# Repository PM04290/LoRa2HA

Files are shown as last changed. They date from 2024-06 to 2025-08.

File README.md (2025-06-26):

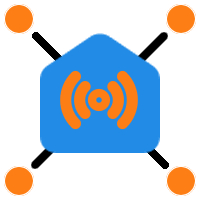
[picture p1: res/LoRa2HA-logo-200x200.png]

# LoRa2HA

Document version 1.4

## Introduction
LoRa2HA permet de combler un vide dans les équipements domotique lorsque qu'il est nécéssaire de surveiller/piloter sur une longue distance, là où Wifi et Zigbee ne peuvent aller.
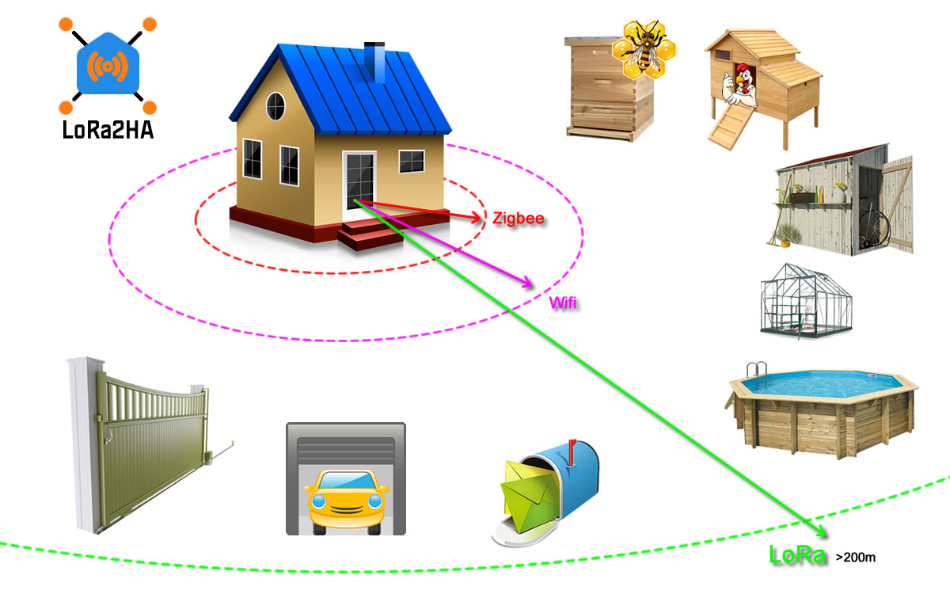
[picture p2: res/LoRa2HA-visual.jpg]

Le projet propose des équipements permettant une interconnexion entre des capteurs/actionneurs très éloignés d'un serveur HomeAssistant (via MQTT), par radio en utilisant des modules LoRa.
Le HUB, à base d'ESP32 (Wifi ou Ethernet), reçoit les données radio et les envoi vers Home Assistant (H.A.) au travers d'un serveur MQTT. Le terme de HUB sera utilisé, et non Gateway, afin de ne pas créer de confusion avec les Gateway « LoRaWan ».

Le projet contient les sources de tous les firmwares, les schémas des cartes, les « Gerber » afin de pouvoir les fabriquer et des fichiers 3D pour la fabrication de boîtiers.

## Documentation

Le fichier PDF de la documentation complète est téléchargeable [ici](https://raw.githubusercontent.com/PM04290/LoRa2HA/main/doc/LoRa2HA-readme-14.pdf)

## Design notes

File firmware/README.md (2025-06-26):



# LoRa2HA T3216 Firmware
Firmware library for LoRa2HA module with ATtiny3216 mcu

|File name|Version|Target|Description|
|---|--:|---|---|
|T3216_blinkLED|1.0|T3216|Just a blink test, for 1MHz, low power (MLA30)
|T3216_blinkRGB|1.0|T3216|Just a blink test, for 4MHz (MLD03, MLE31, MLE42)
|MLD03_waterpool-02|2.0|T3216|Waterpool manager (filter, refill, frost)
|MLD03_sprinkle-02|2.0|T3216|2 ways sprinkle manager
|MLA30_mboxS-02|2.0|T3216|Mailbox with 3 magnetic sensor (NO), state in H.A
|MLA30_mboxT-02|2.0|T3216|Mailbox with 3 magnetic sensor (NO), opening trigger in H.A
|MLA30_ping-02|2.0|T3216|MLA30+Oled pinger for distance test
|MLE31_gate-02|2.0|T3216|Control gate opening
|MLE42_garage-02|2.0|T3216|Control garage door
|MLE42_henhouse-02|2.0|T3216|Control henhouse door

# HowTo

Use a simple USB/TTL dongle, with 1k resistor between RX and TX; connect VCC/GND and TX to UPDI.

Run uploadfirmware.bat

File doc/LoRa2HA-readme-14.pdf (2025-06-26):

# LoRa2HA

Documentation version 1.4

# Introduction

LoRa2HA est un ensemble d’équipements permettant une interconnexion entre des capteurs/actionneurs éloignés et un serveur Home Assistant (via MQTT), par radio en utilisant des modules LoRa®
; la portée peut
aller jusqu’à plus de 500m selon la qualité des antennes.

Le HUB (basé sur ESP32), reçoit les données radio et les envoi à Home Assistant (H.A) au travers d’un serveur MQTT.

Le terme de HUB sera utilisé, et non Gateway, afin de ne pas créer de confusion avec les Gateway
« LoRaWan ».

Le projet¹
contient les sources de tous les firmwares, les schémas des cartes ainsi que les « Gerber » afin de pouvoir fabriquer les PCB.

1 Ce projet est destiné à la communauté des « makers » et est fourni à titre informatif et éducatif. Il est fourni "tel quel", sans garantie d'aucune sorte, expresse ou implicite, y compris, mais sans s'y limiter, notamment concernant son fonctionnement, sa sécurité ou son adéquation à un usage particulier. L'utilisation de ce projet se fait à vos propres risques. L'auteur et les contributeurs ne pourront être tenus responsables des conséquences de l'utilisation de ce projet, des dommages directs, indirects, accessoires, ou consécutifs pouvant résulter de l'utilisation ou de l'incapacité d'utiliser le projet. L'assemblage, la modification ou l'utilisation des matériels et logiciels associés à ce projet impliquent des risques. Vous êtes seul responsable de l'utilisation que vous en faites, y compris des éventuels
dommages matériels, blessures, ou autres incidents pouvant survenir.
Important : Avant d'utiliser ce projet dans un environnement de production ou dans un cadre professionnel, veuillez vous assurer qu'il est conforme à vos exigences et aux réglementations en vigueur.
Attention : Manipuler des composants électroniques, des outils, ou des matériaux peut être dangereux. Prenez toutes les précautions nécessaires, notamment l'utilisation d'équipements de protection, et suivez les réglementations locales en matière de sécurité.

### LoRa2HA

## Sommaire

# 1 Les équipements

La référence de chaque module adopte la terminologie suivante :

- ML : Module LoRa
- H : Hub, D : Dédié, E : alimentation Externe, A : alimentation Autonome
- un nombre indiquant un ordre de création (Ex : Hub et Dédié) ou un nombre d’entrées sorties (Ex 31 = 3 entrées / 1 sortie), éventuellement suivi d’un ordre de création ou d’une lettre (fonctionnalité particulière).

La nouvelle génération de modules est basée sur le microprocesseur ATtiny3216, une carte « fille » MLT3216 équipe la majorité des modules de terrains, étant extractible elle permet une mise à jour firmware plus facilement.

## 1.1 Les HUB

Il existe 5 types de HUB selon le besoin, tous équipés d’un module LoRa :

- MLH1²
: ESP32-S2 Mini, en wifi
- MLH2 : Olimex-POE-ISO, en Ethernet avec POE
- MLH3 : WT32-ETH01, en Ethernet
- MLH4 : ESP32-D1-Mini, en wifi
- MLH5 : TTGO_LoRa32 (pcb T3_v1.6)

Dans le cas du MLH3, il est tout à fait possible de le rendre « POE » en le connectant derrière un répartiteur POE de ce type, type USB-C/5v (coût inférieur à 10€) :

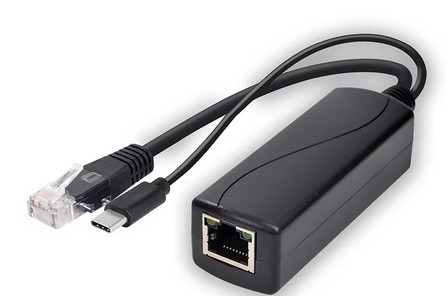
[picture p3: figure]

Le HUB dispose de son propre serveur web permettant le paramétrage de la connexion à H.A ainsi que l’identification des tous les modules sur le terrain.

Estimation de difficulté/prix

Modèle | Wifi | Ethernet | POE | DIY | Coût
MLH1 | ✓ | | | ★☆☆ | ★☆☆
MLH2 | ✓ | ✓ | ✓ | ★☆☆ | ★★★
MLH3 | ✓ | ✓ | indirect | ★★☆ | ★★☆
MLH4 | ✓ | | | ★☆☆ | ★☆☆
MLH5 | ✓ | | | ★☆☆ | ★★☆
DIY : difficulté de fabrication | Coût : <10€, <15€, >15€

2 Le HUB MLH1 ne permet pas le téléchargement des firmware par UPDI

## 1.2 Les modules « capteurs/actionneurs »

Il existe plusieurs types de modules :

- MLD01 : Relevé TIC Linky (alimenté par USB externe)
- MLD02 : Relevé TIC Linky (alimenté par Linky) (projet en cours)
- MLD03 : Gestion de piscine (hors chimie)
- MLA30 : 3 entrées, autonome, très basse consommation, avec batterie et panneau solaire
- MLE21 : 2 entrées / 1 sortie, alimenté en 8-28vdc (remplacé par MLE31)
- MLE31 : 3 entrées / 1 relai, alimenté en 8-28vdc
- MLE42 : 4 entrées / 2 relais ou 1 moteur (2 sens de rotation), alimenté en 8-28vdc

Chaque module possède un Firmware proposé par défaut mais il est possible d’adapter ceux-ci pour en modifier les fonctionnalités et/ou l’adapter aux capteurs connectés.

Estimation de difficulté/prix

Modèle | DIY | Coût module | Coût externe³
MLD01 | ★☆☆ | ★☆☆ | ☆☆☆
MLD03 | ★★☆ | ★★★ | ★★☆
MLA30 | ★★★ | ★★☆ | ★★☆
MLE31 | ★★☆ | ★★★ | ★☆☆
MLE42 | ★★☆ | ★★★ | ★★☆
DIY : difficulté de fabrication | Coût : <10€, <15€, >15€

3 Le coût externe est une indication du coût des différents capteurs/actionneurs les plus courants dans les applications pour lesquelles les modules sont utilisés.

# 2 Fonctionnement

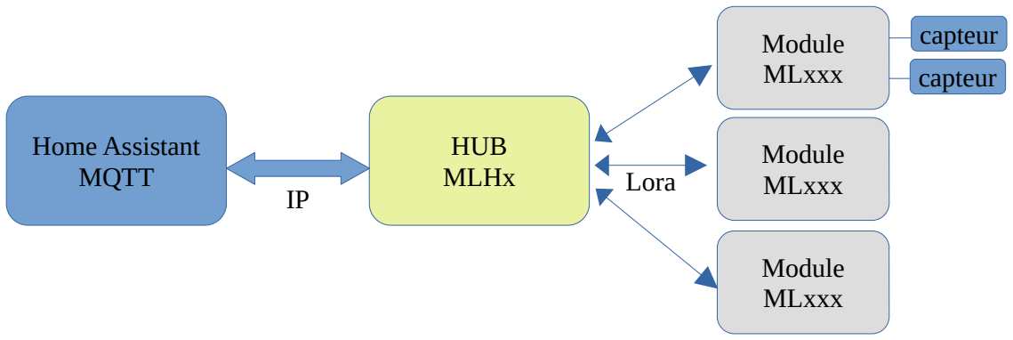
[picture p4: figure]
Home Assistant MQTT; HUB MLHx; Module MLxxx; Lora; capteur capteur

Chaque module (MLxxx) transmet les informations des capteurs (par LoRa) vers le HUB, celui-ci est connecté à H.A (via MQTT) par IP, et redirige les informations.

❗️ ATTENTION : le choix des antennes et leur position sont particulièrement importants.

Il est conseillé d’installer une antenne à gain important sur le HUB (> 3 dBi).

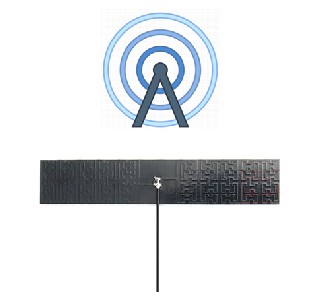
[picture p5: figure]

L’antenne à « ressort » des modules RA-01, ainsi que les antennes « bâton » (généralement avec connecteur SMA) doivent être utilisées à la verticale.

Les antennes IPX sur PCB, comme ci-contre (jonction au milieu), doivent être utilisées à la verticale et perpendiculaire à l’azimut du HUB.

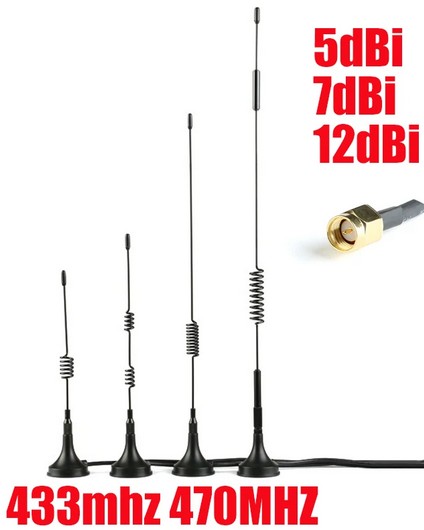
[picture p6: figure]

Exemple de choix d’antenne que vous pouvez installer sur le HUB, avec un convertisseur IPX/SMA, sur un module RA-02.

# 3 Mise en route

Cela commence par l’installation et la configuration du HUB.

H.A doit avoir un serveur MQTT en état de fonctionnement.

## 3.1 Installation du HUB

→ Pour la programmation du HUB, voir le chapitre « Programmation »

Le HUB une foi programmé doit être raccordé au réseau IP, identique à celui de H.A.

## 3.1.1 Sélecteur WMODE

Le sélecteur « WMODE » permet de choisir le mode de fonctionnement du réseau IP : Wifi STA, Wifi AP ou Ethernet.

- Wifi STA (Station) démarre le HUB en mode Wifi « classique », même si ce wifi n’est pas disponible, il restera alors en « défaut » (l’ancienne version passait automatiquement en mode AP, cela générait des problèmes lors de coupure générale du secteur, quand le routeur wifi était long à démarrer, le HUB ne le trouvait pas et passait en mode AP),
- Wifi AP force le HUB à rester en mode AP (Access Point), même si les données wifi ont été renseignées,
- Ethernet (seulement sur MLH2 et MLH3) force le HUB à fonctionner en Ethernet, le Wifi n’est pas utilisé, câble connecté ou non.

→ Pour les HUB wifi :

- si aucun paramétrage n’a jamais été effectué, il passe automatiquement en mode « Point d’accès » (AP).
- si un autre réseau wifi a déjà été paramétré et que vous souhaitez en changer parce qu’il n’est pas accessible, positionnez le sélecteur « WMODE » en position AP.

## 3.1.2 Wifi AP

Cherchez un réseau wifi nommé « lora2ha0 » et connectez-vous ; le mot de passe est : 12345678.

En mode AP, le HUB est à l’adresse IP 192.168.4.1 ou l’URL lora2ha0.local ; la page ci-dessous doit s’afficher.

Avec un smartphone, scannez les QRcode suivants :

Connexion au wifi AP du HUB

Accès à la page web

❗️ Si la page ne s’affiche pas, il est probable que le dossier « data », contenant le serveur web, n’ai pas été téléchargé correctement dans l’ESP32.

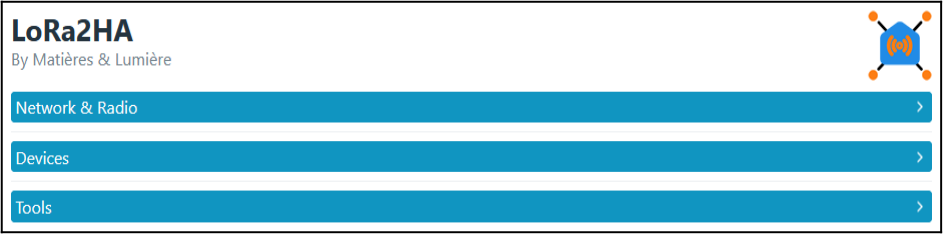
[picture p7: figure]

## 3.1.3 Configuration réseau

Ouvrez la zone « Network & Radio », renseignez les données demandées puis enregistrez.

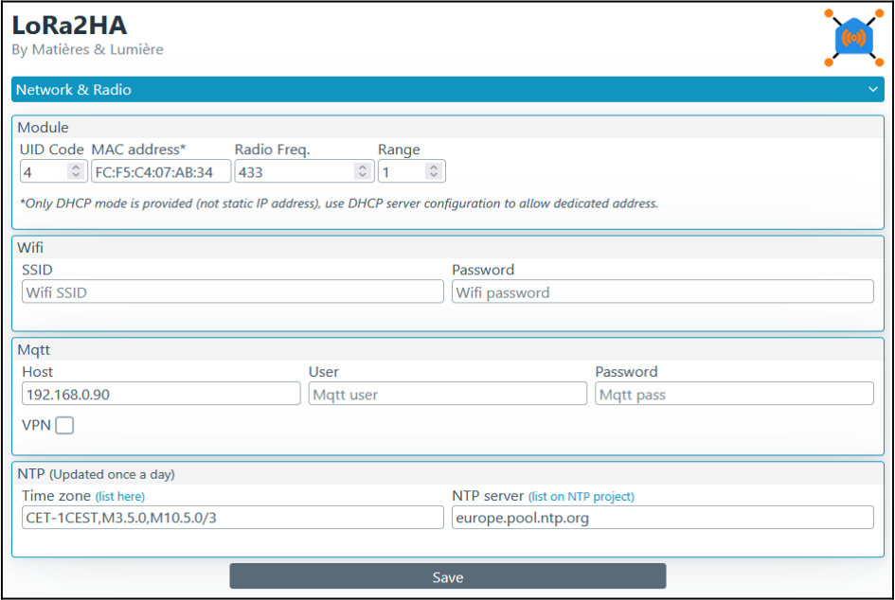
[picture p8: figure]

L’information de l’adresse MAC vous permet de pouvoir gérer votre serveur DHCP et affecter une adresse IP spécifique, le HUB ne fonctionne QUE avec un serveur DHCP, il n’est pas possible de lui attribuer une IP fixe.

Si vous envisagez de mettre plusieurs HUB sur le réseau, il faut indiquer un code unique à chacun dans « UID Code » (sinon laissez 0) ; il est conseillé de mettre « 1 » au premier HUB que vous paramétrez et laisser « 0 » pour le suivant.

Selon le modem LoRa qui est utilisé, vous devez indiquer la fréquence 433 ou 868 (MHz).

Dans « Mqtt host » indiquez uniquement l’adresse IP du serveur Mqtt (ou celle de H.A si Mqtt y est intégré en Add-on).

☞ Le port par défaut est le 1883 (pas de SSL). Un prochaine version permettra d’utiliser SSL.

Le configuration NTP sert au HUB pour « publier » l’heure vers les différents modules qui en ont besoin.

Une fois sauvegardé, il faut redémarrer le HUB, physiquement ou en cliquant sur le bouton « Reset » dans la zone « Tools », avant cela, positionnez le sélecteur « WMODE » sur STA.

En « production » l’adresse du HUB est « lora2ha0.local », ou l’adresse IP fournie par votre serveur DHCP.

Le HUB est prêt à recevoir les informations radio des « modules » et ainsi pouvoir les paramétrer.

## 3.1.4 Utilitaires

La zone « Tools » permet d’effectuer la maintenance du HUB ainsi que des mises à jours de fichiers, ou sauvegarder la configuration.

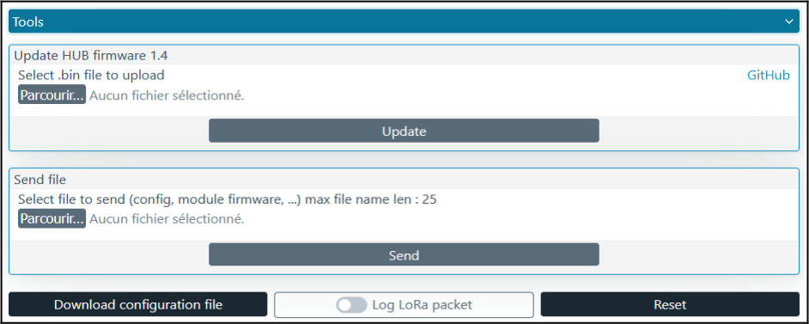
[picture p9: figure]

## 3.1.5 Mise à jour du Firmware

Le firmware peut être mis à jour par OTA (Other The Air), cliquant sur le bouton « Parcourir » de la zone « Update firmware », de sélectionner le fichier contenant le Firmware (avec un extension .bin), le nom contient en général le type d’ESP32 qui est utilisé, et enfin cliquer sur le bouton « Update ».

Le téléchargement prend entre 5 et 10 secondes, l’ESP32 redémarre et la page est web rechargée.

☞ Avant toute mise à jour du firmware, effectuez une sauvegarde de la configuration en cliquant sur le bouton

« Download configuration file ».

## 3.1.6 Mise à jour de fichiers

Tous les fichiers du serveur web peuvent être mis à jour en cliquant sur le bouton « Parcourir » de la zone « Send file », de sélectionner le fichier dans le dossier « data », et enfin de cliquer sur le bouton « Send ».

L’ESP32 ne redémarre pas mais la page web est rechargée.

Si vous avez envoyé un nouveau fichier de configuration, il faut redémarrer l’ESP32 pour qu’il soit pris en compte.

## 3.2 Installation des modules capteurs/actionneurs

→Pour la programmation des modules, voir le chapitre « Programmation »

Sur la page web du HUB, ouvrez la zone « Devices », si aucun module n’a encore été appairé, l’indication suivante est affichée.

Il faut mettre le HUB en mode « Pairing » (appairage) en activant le sélecteur « Pairing active », un bandeau orange apparaît.

Sur le module, appuyez sur le bouton « CFG » et mettez le sous tension. Si une led est présente, elle clignote tant que vous tenez le bouton appuyé. Relâchez le bouton pour passer le module en mode « Pairing ».

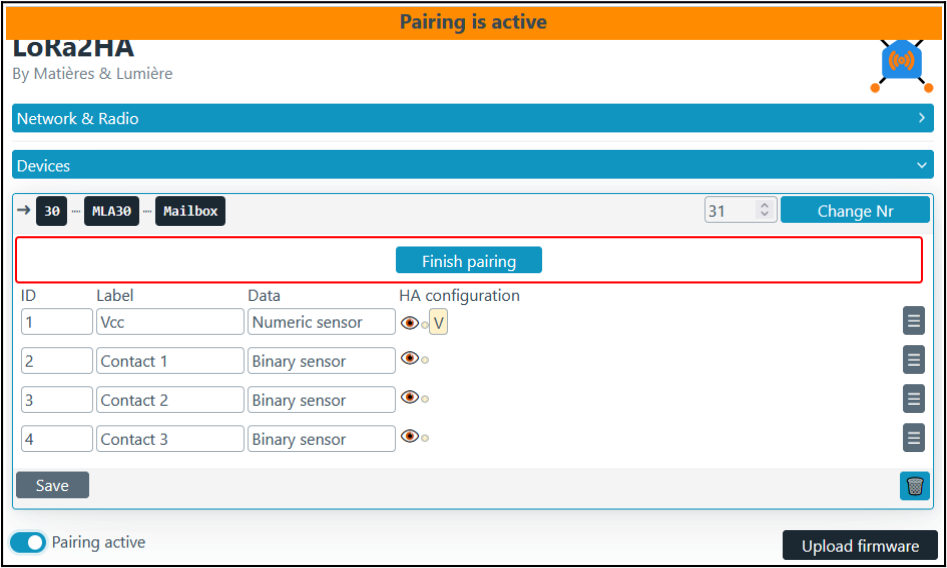
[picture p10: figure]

☞Attention, si vous tenez le bouton « CFG » appuyé plus de 10 secondes, le module fera une remise à zéro complète

de sa mémoire (Factory setting).

Chaque module doit avoir une adresse unique (définie par le firmware), lorsqu’il y a plusieurs modules identiques, il faut modifier l’adressage de ceux-ci :

1. affectez un nouveau numéro
2. cliquez sur le bouton « Change Nr »

Pour libérer le module de son mode « Pairing », vous devez cliquer sur le bouton « Finish pairing ».

→ l’action « Finish pairing » n’a aucune incidence sur le HUB, elle libère simplement le module.

☞ L’image ci-dessus correspond au firmware « mla30-mboxS », avec des contacts qui envoient leur état binaire (Binary

sensor / State) ; dans le cas du firmware « mla30-mboxT » c’est un événement qui est généré (Trigger) et il n’est seulement visible que dans les automatisations.

## 3.2.1 Multiples modules identiques

Lorsque vous avez plusieurs modules identiques, par exemple 2 modules MLA30, ils doivent avoir les numéros 30 et 31, commencez toujours par le numéro le plus haut :

1. appairez le premier module

2. il affiche son numéro par défaut : 30
3. changez son adresse par 31
4. terminez le « pairing »
5. sauvegardez la configuration
6. appairez le deuxième module
7. il affiche son numéro par défaut : 30
8. gardez ce numéro
9. sauvegardez la configuration

## 3.2.2 Paramétrage des capteurs

- « ID » est le n° du capteur/actionneur, il est défini par le firmware de chaque module
- « Label » est le nom du capteur/actionneur qui apparaîtra dans H.A
- « Data » est le type de donnée transmise par le module, il est définit par le firmware

Cliquez ensuite sur le bouton pour ouvrir la boite de dialogue permettant la configuration du capteur/actionneur pour H.A.

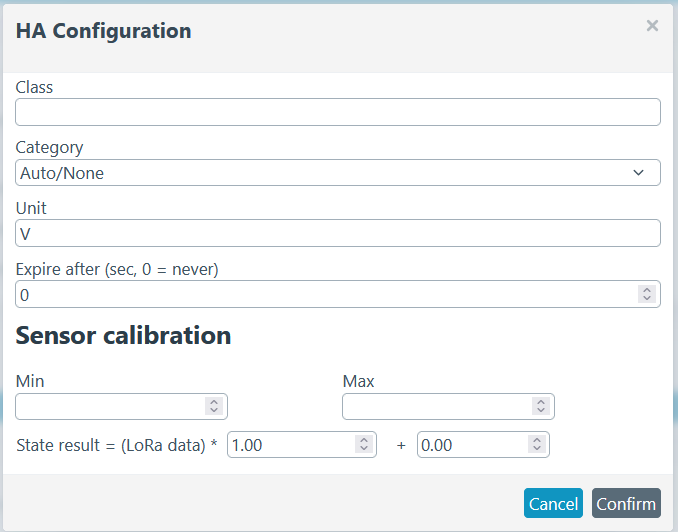
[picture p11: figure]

- « Class » selon le type de capteur (sensor, binary_sensor, etc), il est possible d’avoir des classes différentes, vous trouvez les informations nécessaires sur la page web du site de Home Assistant : https://www.home-assistant.io/docs/configuration/customizing-devices/#device-class (https://www.home-assistant.io/docs/configuration/customizing-devices/#device-class)
- « Category » permet de classer le capteur en tant que Mesure, Diagnostic ou Configuration.
- « Unit » permet d’indiquer l’unité correspondant à la mesure du capteur
- « Expire after » est la durée pendant laquelle la mesure est valide, au-delà elle sera « indisponible » au sens H.A.
- « Min » et « Max » permettent de borner les mesures reçues. Il peut arriver qu’il y ai des erreurs de mesure (ou autre) qui aboutissent à une donnée qui soit hors de sa plage normale, par exemple une consommation électrique de plus de 100 KW, si vous avez un abonnement 9KWh, vous pouvez entrer 10 000 dans max, par exemple.
- « State result » permet d’appliquer des coefficients correcteur à une mesure brute (Y = A*X + B), par exemple si une température est 1° en dessus de la température normale, entrez -1 dans le deuxième paramètre (B).

Dans la zone « Class », commencez à taper le début du texte si vous connaissez la classe à attribuer, ou faite 2 fois 1 clic pour afficher la liste complète.

Après avoir complété les différents paramètres, sauvegardez le paramétrage en cliquant sur « Confirm ».

Après avoir tout configuré, cliquez sur le bouton « Save ».

Il est possible de supprimer entièrement un module en cliquant sur le bouton .

## 3.2.3 Module MLD01 Linky

Le module est à l’adresse « 10 » par défaut (elle ne peut pas être changée, sauf à modifier le firmware et reprogrammer le module).

Le code source proposé, fonctionne en mode « Historique » par défaut, avec très peu de modification il est possible de le faire fonctionner en mode « standard ».

Le module ayant une forte consommation, il n’est pas possible d’utiliser l’alimentation fournie par le connecteur TIC du Linky (borne A), il devra donc avoir sa propre alimentation externe, type chargeur USB.

Connectez le module sur le connecteur TIC du linky : bornes I1 et I2.

Dans le Firmware par défaut (lora2ha-MLD01-Linky-ProMicro) vous disposez des informations ci-dessous :

ID | Label linky | Donnée
1 | OPTARIF | BASE, HPHC/HCHP
2 | BASE | Compteur (KWh)
3 | HPHC | Compteur HC (KWh)
4 | HCHP | Compteur HP (KWh)
5 | PAPP | Puissance apparente (VA)
6 | INST (monophasé) INST1 (triphasé) | Intensité instantanée 1 (A)
7 | INST2 (triphasé) | Intensité instantanée 2 (A)
8 | INST3 (triphasé) | Intensité instantanée 3 (A)

## 3.2.4 Module MLD02 Linky (Autonome)

Ce module n’est pas encore validé.

## 3.2.5 Module MLD3 (Piscine)

Le module « Piscine » est plus particulièrement adapté aux piscines hors-sol, il peut être positionné à l’endroit où est branché la pompe du filtre, dans un boîtier équipé de rail DIN.

La documentation détaillée se trouve dans le document LoRa2HA-MLD03-readme.pdf.

## 3.2.6 Module MLE21 (2 in / 1 out)

Ce module est remplacé par le module MLE31.

## 3.2.7 Module MLE31 (3 in / 1 out)

Ce module est principalement destiné à la gestion d’un portail, mais sa polyvalence d’entrées/sortie permet de l’utiliser dans beaucoup d’autres projets.

La documentation détaillée se trouve dans le document LoRa2HA-MLE31-readme.pdf.

## 3.2.8 Module MLE42 (4 in / 2 out)

Ce module est principalement destiné à la gestion d’une porte de garage ou d’un poulailler. Les 2 sorties peuvent être 2 relais OU 1 moteur (bidirectionnel), mais sa polyvalence d’entrées/sortie permet de l’utiliser dans beaucoup d’autres projets.

La documentation détaillée se trouve dans le document LoRa2HA-MLE42-readme.pdf.

## 3.2.9 Module MLA30 (3 in / 0 out)

Ce module est principalement destiné à la gestion d’une boite à lettre.

Étant autonome pour son alimentation, il peut être utilisé pour tous les projets de mesure à faible fréquence.

Sa consommation en veille est d’environ 5µA, soit une durée de vie de plus de 20 ans (sur le papier) ; cette durée est altérée par la consommation lors de son réveil, par le type de capteur qui lui est raccordé, et la fréquence à laquelle il est réveillé. La transmission LoRa consomme environ 60mA durant 100ms, par donnée à transférer.

La documentation détaillée se trouve dans le document LoRa2HA-MLA30-readme.pdf.

3.3 Contrôle dans H.A.

Dans H.A, cliquez sur « Paramètres » puis « Appareils et Services ».

Dans le bloc « MQTT » cliquez sur le nombre d’appareils pour afficher la liste des appareils connus.

Le premier appareil trouvé concerne le HUB, « lora2ha0 HUB », il propose 2 entités :

- Watchdog timer, période à laquelle le HUB envoie une information de « vie » à H.A
- Connection state, information de connexion du HUB.

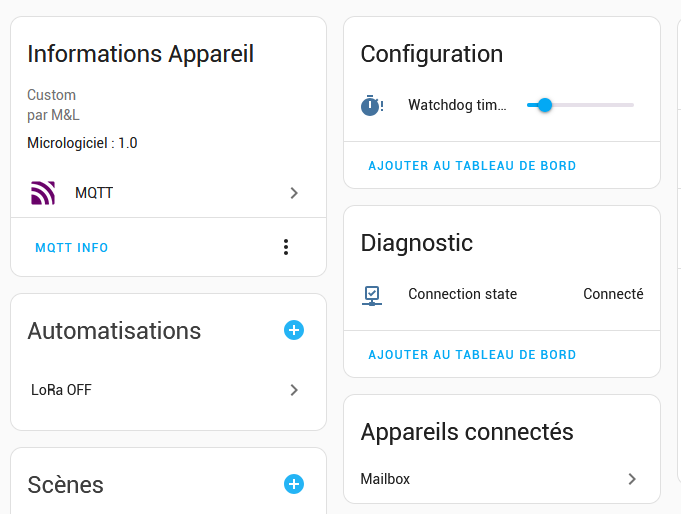
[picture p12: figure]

Il propose la liste des tous les appareils qui lui sont connectés. En choisissant « Mailbox » vous arrivez sur cette page :

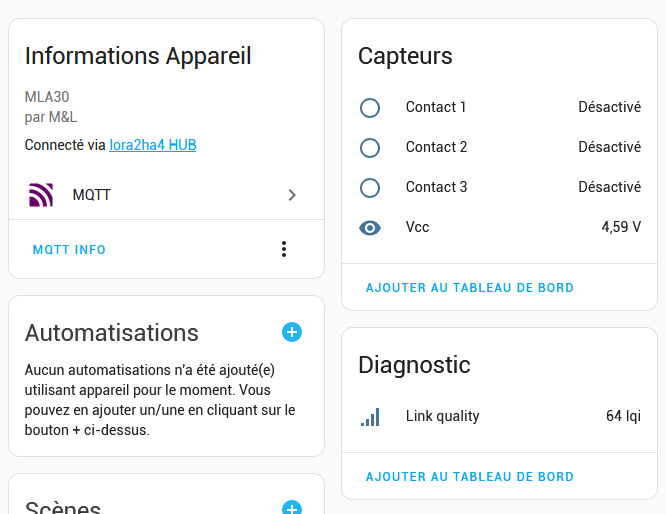
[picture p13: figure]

Si vous voyez apparaître des anciens capteurs ou contrôles (après changement de nom ou de type par exemple), il faut supprimer l’appareil en totalité. Si besoin un nouvel appareil sera re-créé lors du prochain démarrage du HUB.

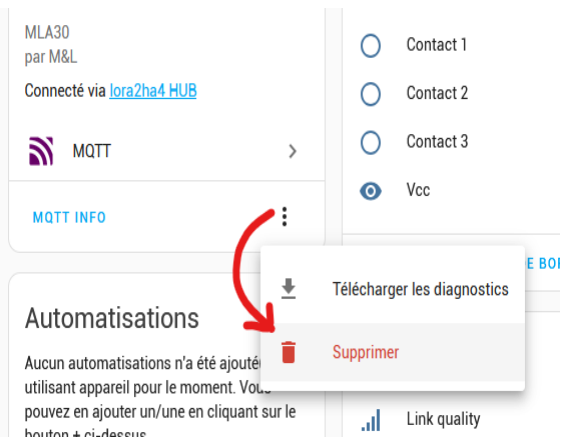
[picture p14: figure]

# 4 Montage des HUB

La liste complète des différents composants est fournie en Annexe A.

## 4.1 MLH1

La carte MLH1 doit être équipée d’un ESP32-S2 Mini.

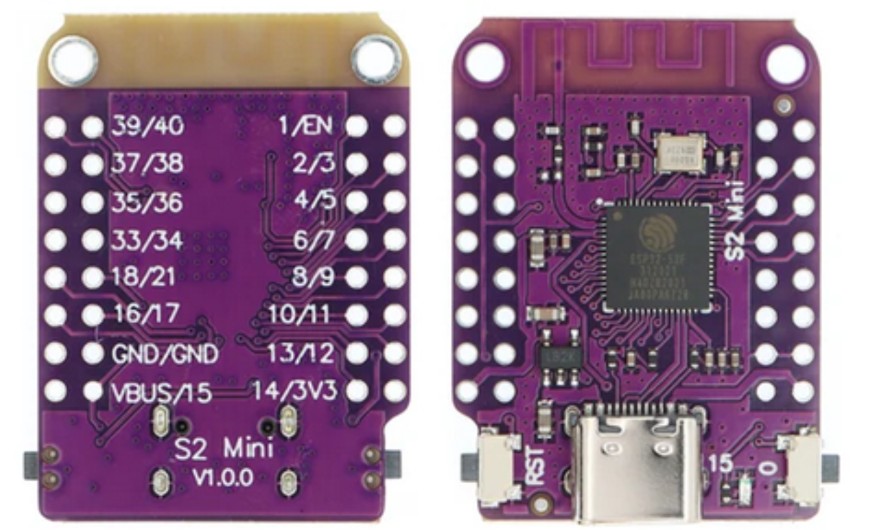
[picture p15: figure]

Le module LoRa conseillé est en 433MHz, RA-02 (connecteur IPX), en choisissant une antenne adaptée (> 3 Dbi).

Attention, il existe plusieurs modèles de modules LoRa, il faut celui avec le connecteur DIP 2x4 pins.

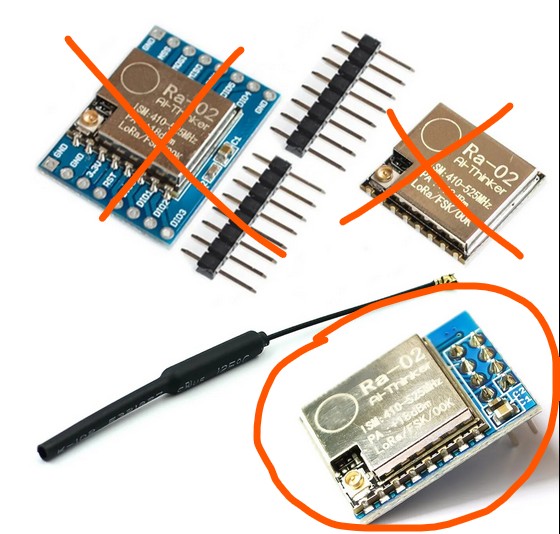
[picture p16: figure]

L’alimentation de la carte se fait au travers du connecteur USB de l’ESP32 ou par le connecteur H1 en 5V.

## 4.2 MLH2

La carte MLH2 doit être équipée d’un ESP32-POE-ISO, Wifi à gauche, Ethernet à droite.

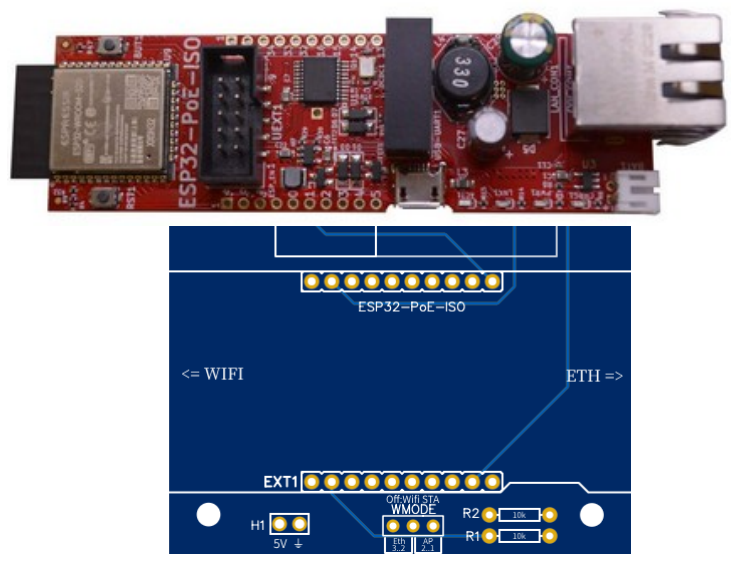
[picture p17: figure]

Il y a la possibilité d’utiliser la version « EA » avec une antenne IPX

Le connecteur H1 peut être utilisé pour l’alimentation (5V) si le POE n’est pas disponible.

Le module LoRa est identique à la carte MLH1.

## 4.3 MLH3

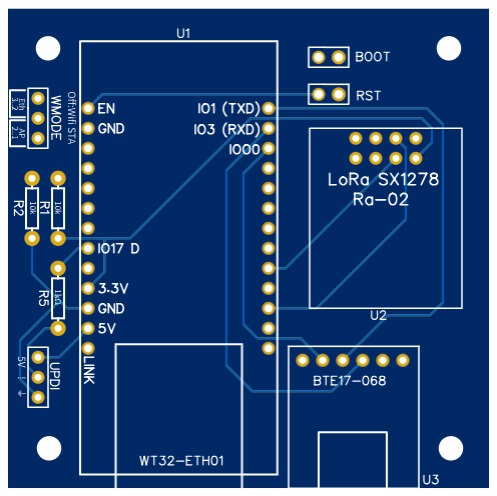
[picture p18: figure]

La carte MLH3 doit être équipée d’un WT32-ETH01.

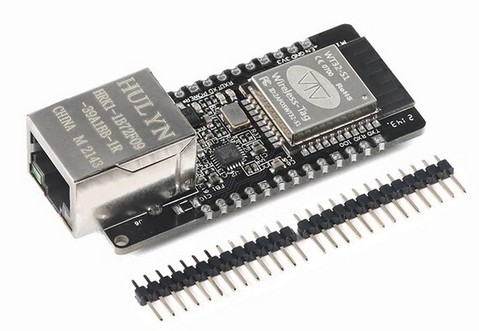
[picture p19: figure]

Le module LoRa est identique à la carte MLH1.

L’alimentation se fait au travers d’une mini carte USB (BTE17-06B), cette carte est un convertisseur USB /TTL CH340E, permettant la programmation du module.

Pour passer le module en mode « programmation », il faut relier le Jumper « BOOT » et faire un « Reset » avec le Jumper « RST ».

## 4.4 MLH4

La carte MLH4 doit être équipée d’un ESP32-D1-Mini.

Le module LoRa est identique à la carte MLH1.

Le connecteur J1 peut être utilisé pour l’alimentation (5V).

## 4.5 MLH5

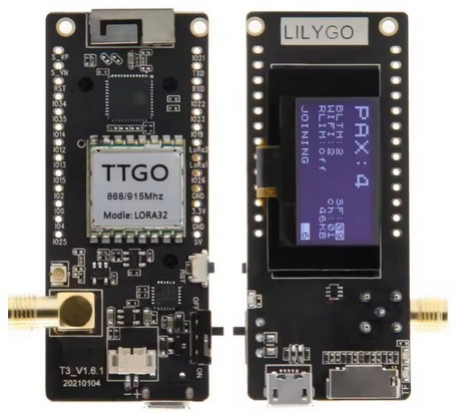
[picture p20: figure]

Il n’y a pas de PCB pour ce HUB, la carte inclue tous les modules.

WMode peut être géré en connectant un interrupteur sur l’entrée IO4.

# 5 Programmation

Ce chapitre sous-entend que vous maîtrisez la programmation d’un Arduino.

Plusieurs tutos traitent de ce sujet, cette documentation n’a pas vocation à entrer dans le détail de la programmation d’un Arduino.

## 5.1 Prérequis

La librairie « RadioLink » doit être installée en téléchargeant le fichier zip sur le GitHub « PM04290 » (https://github.com/PM04290/RadioLink) et en le décompressant dans le dossiers des librairies Arduino ;

Les différentes librairies utiles à la compilation sont détaillées dans le code source de chaque projet.

## 5.2 Programmer le HUB

Il existe une manière simple de programmer le HUB si vous ne souhaitez pas recompiler tout le programme ; il suffit d’utiliser les fichiers de commandes (.bat) du dossier « tools ». Ce dossier embarque tous les exécutables permettant d’effectuer la programmation sans IDE Arduino.

Il faut utiliser un câble USB équipé des fils de « data », pas simplement dédiée à la charge des appareils.

## 5.2.1 Programmation simple de MLH1

1. Appuyez sur le bouton « BOOT »
2. Mettez la carte sous tension en raccordant la prise USB
3. Relâchez le bouton « BOOT »
4. Dans le dossier « tools », exécutez le fichier de commande commande « MLH1_LOLIN-S2-Mini.bat »
5. Sélectionnez le port « COM » correspondant au connecteur USB
6. Le téléchargement se passe en 2 étapes : fichiers du serveur web, puis firmware
7. En fin de téléchargement, l’ESP32 ne fera pas de Reset, Faites un contact bref sur le bouton « RST ».

## 5.2.2 Programmation simple de MLH2

1. Appuyez sur le bouton « BUT1 »
2. Mettez la carte sous tension en raccordant la prise USB
3. Relâchez le bouton « BUT1 »
4. Dans le dossier « tools », exécutez le fichier de commande commande « MLH2_Olimex-POE_ISO.bat »
5. Sélectionnez le port « COM » correspondant au connecteur USB
6. Le téléchargement se passe en 2 étapes : fichiers du serveur web, puis firmware
7. En fin de téléchargement, l’ESP32 ne fera pas de Reset, Faites un contact bref sur le bouton « RST1 ».

## 5.2.3 Programmation simple de MLH3

1. Positionnez le Jumper « BOOT »

2. Mettez la carte sous tension en raccordant la prise USB
3. Enlevez le Jumper « BOOT »
4. Dans le dossier « tools », exécutez le fichier de commande commande « MLH3-WT32-ETH01.bat »
5. Sélectionnez le port « COM » correspondant au connecteur USB
6. Le téléchargement se passe en 2 étapes : fichiers du serveur web, puis firmware
7. En fin de téléchargement, l’ESP32 ne fera pas de Reset, Faites un contact bref sur « RST » à l’aide du Jumper.

## 5.2.4 Programmation simple de MLH4

1. Mettez la carte sous tension en raccordant la prise USB
2. Dans le dossier « tools », exécutez le fichier de commande commande « MLH3-WT32-ETH01.bat »
3. Sélectionnez le port « COM » correspondant au connecteur USB
4. Le téléchargement se passe en 2 étapes : fichiers du serveur web, puis firmware

## 5.2.5 Programmation simple de MLH5

5. Mettez la carte sous tension en raccordant la prise USB
6. Dans le dossier « tools », exécutez le fichier de commande commande « MLH5.ttgo-lora32-v21new.bat »
7. Sélectionnez le port « COM » correspondant au connecteur USB
8. Le téléchargement se passe en 2 étapes : fichiers du serveur web, puis firmware
9. En fin de téléchargement, l’ESP32 ne fera pas de Reset, Faites un contact bref sur le bouton « RST ».

## 5.2.6 Programmation avec l’IDE Arduino

Avec l’IDE Arduino, l’ESP32 doit être compilé avec le Core version ≥ 2.0.11 (la version 3.x, n’a pas encore été validée), et installer les add-on pour télécharger le dossier « Data » dans la mémoire flash de l’ESP32.

- Attention, pour l’ESP32-S2, le téléchargement du dossier « data » n’est, à ce jour, pas possible avec l’IDE (l’add-on ne sait pas le gérer) ; il faut donc utiliser le fichier de commande (dans « tools ») pour programmer celui-ci. Si vous adaptez le programme, il faudra « Exporter le binaire compilé » et le téléverser de la même manière.

Ouvrez le projet « lora2ha-HUB-x-y.ino », ou « x » et « y » sont les numéros de version.

Sélectionnez le « Type de carte » adapté au HUB que vous programmez :

- MLH1 : LOLIN S2 Mini
- MLH2 : Olimex-POE_ISO
- MLH3 : WT32-ETH01 Ethernet module
- MLH4 : WEMOS D1 MINI ESP32 (ou MH ET LIVE ESP32MiniKit)
- MLH5 : TTGO LoRa32 v2.1 (1.6.1)

Si vous avez installé toutes les librairies requises, vous pouvez compiler et télécharger le firmware.

Utilisez l’add-on « ESP32 Sketch Data Upload » pour téléverser le dossier « data » contenant le serveur web.

## 5.3 Programmation UPDI

Les HUB (à partir de la version 2.0, sauf MLH1) permettent de programmer tous les modules équipés d’un ATtiny3216, pour cela il suffit de connecter à 3 broches UPDI du HUB à celle de la carte MLT3216 ou du module, en respectant bien les signaux VCC, GND et UPDI.

Il est possible d’utiliser des fils Dupont sir des connecteurs ont été montés ou une « pince » de programmation.

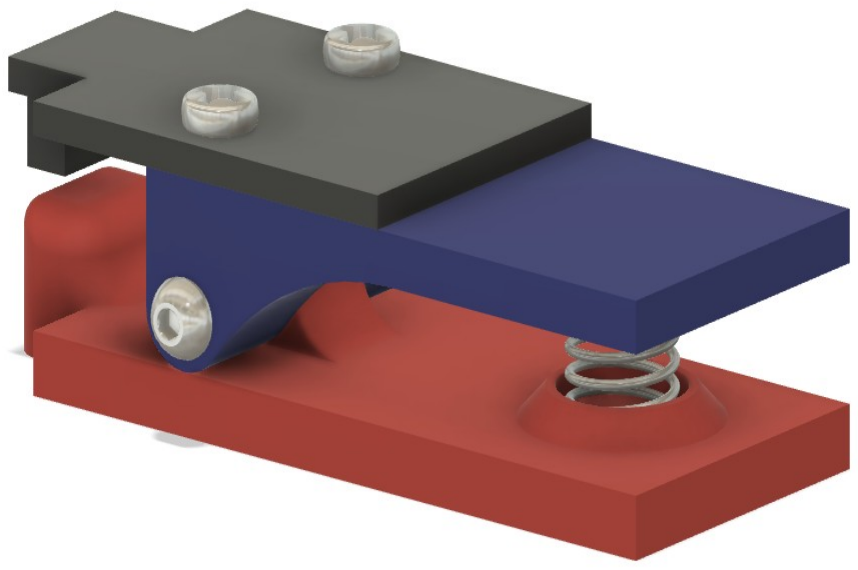
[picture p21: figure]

Le PCB de la carte MLT3216 et « sécable » et fourni un petit PCB permettant de fabriquer un pince de programmation(en noir) ; un fichier 3D est disponible afin de pouvoir imprimer les différents éléments de la pince (rouge et bleu), il faut ensuite :

- 2 vis M2x5 (pour fixer la carte au dessus)
- 1 vis M2x20 et son écrou (pour l’axe de la pince)
- 1 ressort de compression, diamètre 6mm longueur 10mm

Sur la page web du HUB, en bas à droite de la zone « Devices », cliquez sur le bouton « Upload device ».

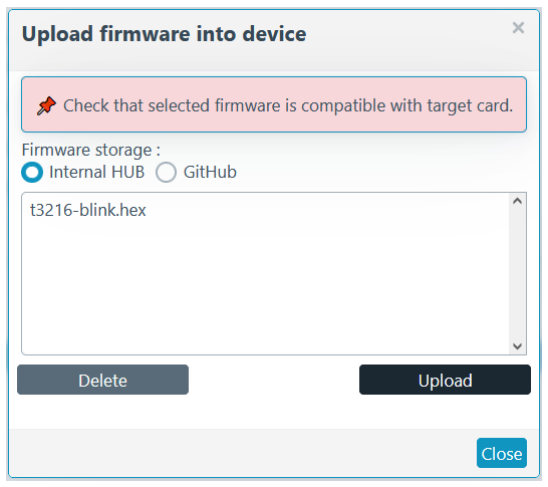
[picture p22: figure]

L’ESP32 peut contenir des firmware dans sa flash interne (Internal HUB) ou il est possible de récupérer des firmware sur le GitHub du projet (GitHub).

Clisez simplement sur le bouton « Upload » pour téléverser le firmware dans le module, après avoir connecté la pince UPDI

# 6 ANNEXE A : Nomenclatures

## 6.1 MLH1

U1 | ESP32-S2 Mini
U2 | RA-02 | Module LoRa SX1278 433MHz
WMODE | Connecteur 1x2 2.54

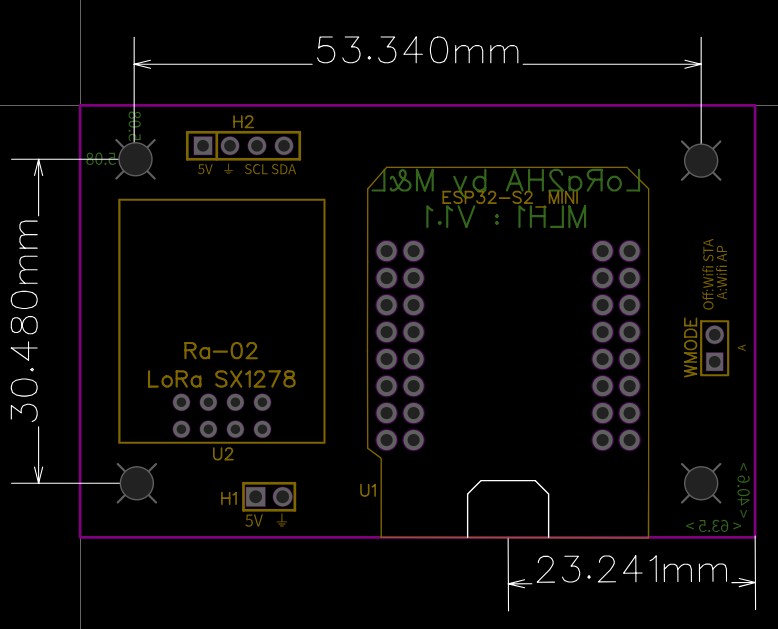
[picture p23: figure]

L’ESP32-S2 n’étant quasiment pas utilisé, cette carte n’est pas encore à jour de la dernière version, la gestion du WMODE.

## 6.2 MLH2

U1 | Olimex-POE-ISO
U2 | RA-02 | Module LoRa SX1278 433MHz
R1, R2 | 10KΩ
R3 | 1KΩ
WMODE | Connecteur mâle 1x3 2.54
H1 | Connecteur femelle 1x2 5.54 | optionnel
UPDI | Au choix selon le besoin de connexion

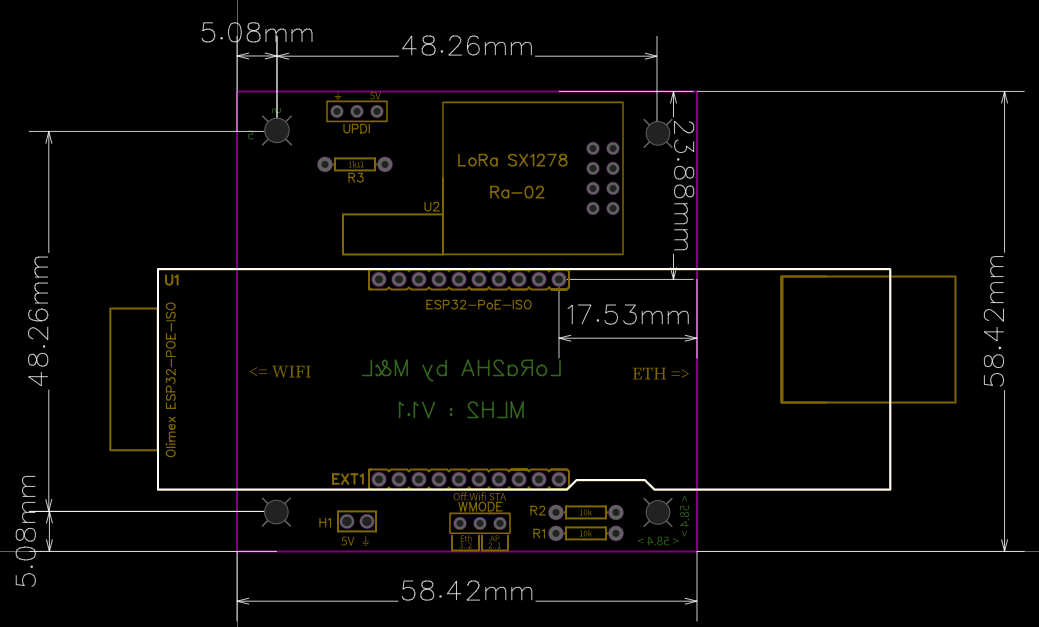
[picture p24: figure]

## 6.3 MLH3

U1 | WT32-ETH01
U2 | RA-02 | Module LoRa SX1278 433MHz
U3 | Carte USB/TTL BTE17-06B | Alimentation / programmation
BOOT | Connecteur mâle 1x2 2.54 | Jumper lors de la programmation
RST | Connecteur mâle 1x2 2.54 | Jumper lors de la programmation
R1, R2 | 10KΩ
R3 | 1KΩ
WMODE | Connecteur mâle 1x3 2.54
UPDI | Au choix selon le besoin de connexion

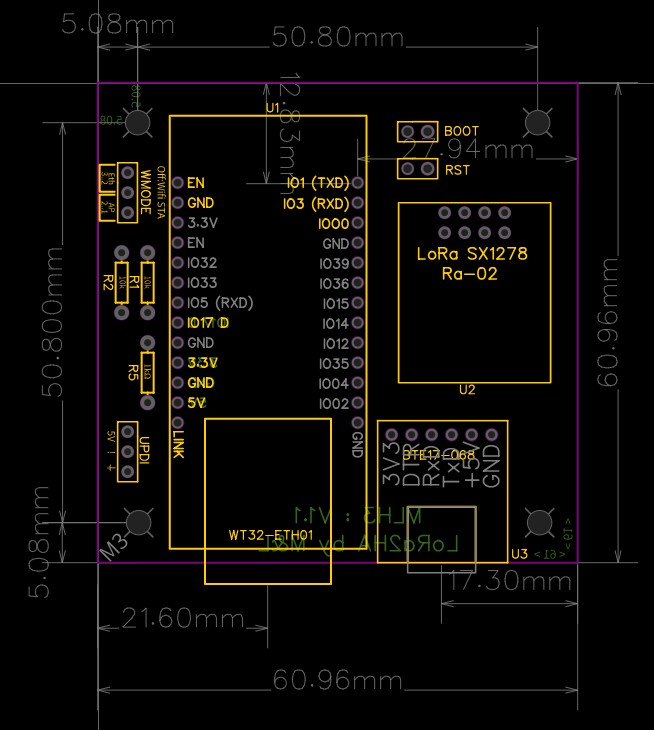
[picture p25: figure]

## 6.4 MLH4

U1 | ESP32-D1 Mini
U2 | RA-02 | Module LoRa SX1278 433MHz
J1 | Connecteur 1x2 2.54 | optionnel
WMODE | Connecteur 1x2 2.54
R1 | 1KΩ
UPDI | Au choix selon le besoin de connexion

## 6.5 MLH5

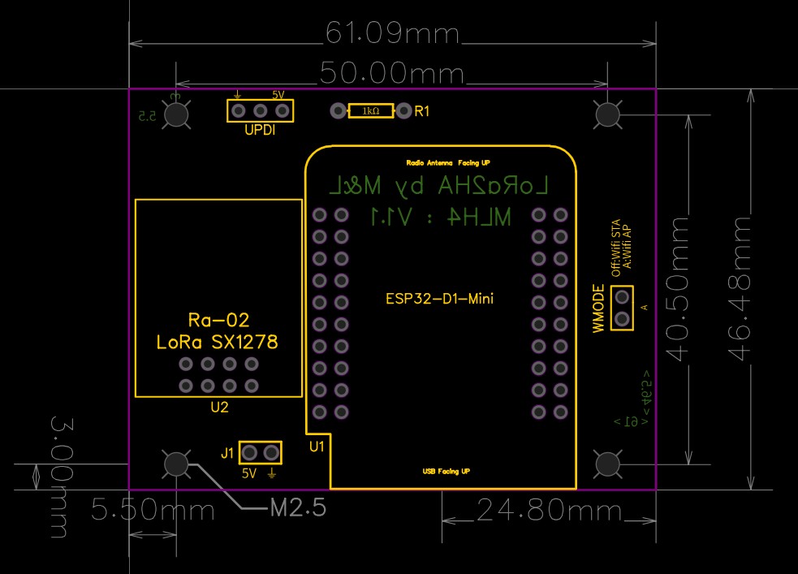
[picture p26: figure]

Il n’y a pas de PCB pour le module MLH5.

L’interrupteur WMode doit être connecté entre IO4 et GND.

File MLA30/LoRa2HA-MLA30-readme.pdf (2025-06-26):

# LoRa2HA

# MLA30


## Table des matières

# 1 Description

Le module MLA30 est principalement destiné à la mesure de capteurs, plus particulièrement des contacts, par exemple pour le suivi d’activité d’une boite à lettres.

Il fonctionne sur batterie, il est donc autonome et n’a pas besoin d’une alimentation externe distante, seule une cellule solaire peut venir recharger la batterie.

# 2 Caractéristiques techniques

Le module doit fonctionner avec une carte d’extension MLT3216, c’est elle qui possède le microprocesseur.

Pour les caractéristiques techniques du microprocesseur, voir la documentation de la carte MLT3216.

Attention de monter la carte MLT3216 dans le bon sens, en suivant la position du bouton CFG (un montage à l’envers n’est pas destructif, mais cela marchera beaucoup moins bien).

## 2.1 Entrées


La carte comporte 4 connecteurs à vis, permettant de brancher les différents capteurs.


- J1, J2 : capteur binaire ou analogique
- J3 : capteur binaire ou analogique, avec alimentation 3.3 V
- J4 : capteur I2C

Les entrées J1, J2 et J3 peuvent fonctionner avec un « pont résistif » pour certain capteur analogique. L’activation du pont résistif se fait en positionnant un « jumper » sur les connecteurs JR1, JR2, JR3.

Les valeurs des résistances sont respectivement 4.7KΩ, 4.7KΩ, 1KΩ, connectée au VCC.

Exemple : Une thermistance CTN de 5KΩ est raccordée à J2, il lui faut un pont résistif afin de pouvoir mesurer la tension aux bornes de celle-ci ; il faut donc mettre un jumper sur JR2.

Dans le cas de certain contact, il peut exister un phénomène de « rebond » ; un petit condensateur de 100nF peut régler le problème ; il est activé en positionnant un jumper sur JC1, JC2 ou JC3.
Exemple : Un contact de porte est positionné en J1, si un « rebond » est détecté régulièrement, il faut positionner un jumper sur JC1 ?

## 2.2 Alimentation


L’alimentation s’effectue au travers de la carte CRLD20MA ☐ et celle-ci gère la charge de la batterie.

Connectez un batterie Lithium sur l’un des connecteur BATXH ou BATPH ☐, selon le type de connecteur qui équipe la batterie. Si la batterie n’a pas de connecteur JST (XH ou PH), il est possible de souder un connecteur à vis (pas 2.54) sur BATXH.

Une cellule solaire de 5V (maxi 500mA) peut être branchée au connecteur PV ☐ afin d’assurer la recharge de la batterie, lors de montages à forte consommation.

→ Attention, si vous avez besoin de relancer le module en débranchant la batterie, il faut laisser la batterie débranchée durant plusieurs secondes (> 30) car le module consomme tellement peu quand il est en veille, qu’il arrive à s’auto-alimenter durant plusieurs secondes par les composants internes.

Lors du branchement de la batterie, le LED doit faire un flash ; si il n’y a pas de flash c’est que le module est toujours en « veille », il faut laisser débrancher plus longtemps.

## 2.3 Module LoRa

Le module LoRa est un RA-02, en 433MHz, il est conseillé de lui connecter une antenne adaptée à la distance souhaitée ; généralement une antenne supérieure à 3 dBi permet de couvrir une distance d’au moins 200m.

## 2.4 LED

La led L1 permet de contrôler le fonctionnement du module, cela est utile lors de la mise en service mais totalement inutile par la suite et cela consomme de l’énergie supplémentaire. Pour que la led fonctionne, il faut positionner le jumper H1.

Lors de la mise sous tension, la LED doit faire 1 seul Flash ; si elle fait 3 flashs consécutifs c’est qu’il y a un défaut sur le module LoRa.

## 2.5 UPDI

C’est le connecteur qui permet la programmation du module, référez vous au chapitre « Programmation ».

- Il faut débrancher l’alimentation principale lors de la programmation.

# 3 Montage de la carte

Il est conseillé de souder en premier les composants CMS puis ensuite les traversants.

- La carte processeur MLT3216 peut être soudée directement mais il est conseillé de la mettre sur support afin de faciliter la programmation de celle-ci lorsque le montage est finalisé et en production.

## 3.1 Schéma


## 3.2 Nomenclatures

Repère | Valeur/référence | Qté
C1 | 1uF (CMS 0805) | 1
C2 | 10nF (CMS0805) | 1
C3 | 2.2uF (CMS0805) | 1
CJ1,CJ2,CJ3 | 100nF (CMS0805) | 3
H1,JC1,JC2,JC3,JR1,JR2,JR3 | 2 Pin header mâle 2.54 | 7
J1,J2,J4 | KF128L-3.81-2P | 3
J3 | KF128L-3.81-3P | 1
L1 | LED-0805_B | 1
PV | DB125-3.81-2P-RD | 1
R1 | 200Ω (CMS0805) | 1
RJ1,RJ2 | 4.7kΩ | 2
RJ3 | 1kΩ | 1
U1B,U2B | 10 pin header femelle 2.54 | 2
U3 | TPS79533 | 1
CRLD20MA | CRLD20MA | 1
BATXH | JST XH 2.54 mâle | 1
BATPH | JST PH 2.0 mâle | 1

# 4 Programmation

La programmation utilise « MegaTinyCore », un projet Github prévu pour tous les microprocesseurs de la gamme Mega/Tiny de la série 0/1/2.

https://github.com/SpenceKonde/megaTinyCore

Dans le projet on trouve toute la documentation afin de transformer un simple Arduino (Uno, Nano) en programmateur UPDI. Il est aussi possible d’utiliser une carte USB/TTL, avec une résistance montée entre TX et RX. Les 2 possibilités sont détaillées dans la documentation MegaTinyCore.

Toutes les librairies utiles sont incluses dans le package MegaTinyCore ou l’IDE Arduino, sauf la libraire dédiée à LoRa2HA : MLiotComm.

https://github.com/PM04290/MLiotComm

La librairie MLiotElements permet de gérer facilement tous les capteurs/actionneurs des modules. Elle n’est pas indispensable si vous créez votre propre programme, mais obligatoire si vous recompilez les firmwares par défaut.

Depuis la version 1.0 des HUB, ces derniers permettent la programmation des ATtiny3216 à l’aide du connecteur UPDI , voir le chapitre « Programmation UPDI » de la documentation principale.

# 5 Utilisation

Avec les Firmwares fournis dans le projet, lors de la première utilisation, la carte MLT3216 va s’initialiser avec des valeurs par défaut :
- Numéro (UID) = 30
- Numéro du Hub (HUID) = 0

Pour appairer le module avec le HUB, il faut :
1. maintenir le bouton CFG lors de la mise sous tension ; la LED va clignoter (1Hz)
2. relâcher le bouton CFG avant 10s (si vous tenez appuyé durant plus de 10s, les données internes vont être ré-initialisées)
3. la LED va s’allumer durant la transmission des informations vers le HUB (il doit être en mode
« Active pairing »)
4. après transmission, la LED clignote lentement
5. lors de la fin du paramétrage par le HUB (Finish Pairing), le module passe en mode « normal », la LED s’éteint.

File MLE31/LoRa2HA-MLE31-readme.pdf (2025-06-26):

# LoRa2HA

# MLE31


## Table des matières

# 1 Description

Le module MLE31 permet la gestion de 3 entrée et 1 sortie (relais contact sec).

Il fonctionne avec une alimentation externe : 5V ou 8-28V.

# 2 Caractéristiques techniques

Le module doit fonctionner avec une carte d’extension MLT3216, c’est elle qui possède le microprocesseur.

Pour les caractéristiques techniques du microprocesseur, voir la documentation de la carte MLT3216.

Attention de monter la carte MLT3216 dans le bon sens, en suivant la position du bouton CFG (un montage à l’envers n’est pas destructif, mais cela marchera beaucoup moins bien).


Les connecteurs de la carte sont les suivants :

- capteurs ☐
- contact sec ☐
- alimentation ☐


## 2.1 Entrées capteurs

La carte comporte 5 connecteurs à vis, permettant de brancher les différents capteurs.

- J1 : capteur binaire ou analogique
- J2, J3 : capteur binaire ou analogique, avec alimentation 3.3 V
- J4 : capteur I2C
- J5 : alimentation 5 V pour capteurs.

Les entrées J1, J2 et J3 sont équipées d’un « pont résistif » pour certain capteur analogiques, les valeurs des résistances sont de 4.7KΩ.

## 2.2 Sortie contact sec

Le connecteur OUT1 fourni un contact sec, il peut aussi permettre de piloter certains équipements avec une très faible puissance : < 1 A.

## 2.3 Alimentation

Le module est alimenté par le connecteur PWR.

Si l’alimentation est directement du 5 VDC, il n’est pas utile de monter le régulateur REG, mais il faut faire un « shunt » en reliant les deux pastilles indiquées sur le PCB (out et in) comme indiqué ci-dessous.


Lorsque le régulateur REG est monté, il accepte une tension d’entrée comprise entre 8 et 28 VDC.

- Ce régulateur ne peut fournir que 1 A, il est donc conseillé de faire un bilan énergétique des tous les équipements qui pourraient être connectés au module : capteur, actionneur, led, rtc.

## 2.4 Module LoRa

Le module LoRa est un RA-02, en 433MHz, il est conseillé de lui connecter une antenne adaptée à la distance souhaitée ; généralement une antenne supérieure à 3 dBi permet de couvrir une distance d’au moins 500m.

## 2.5 LED

La led LED1 permet de contrôler le fonctionnement du module. C’est une led adressable de type WS2812 et il est possible d’étendre le nombre de led en utilisant le connecteur H1.

- Attention à ne pas dépasser la limitation en courant imposé par le régulateur. Si l’alimentation est directement du 5V, il faudra dimensionner correctement celle-ci.

## 2.6 RTC

Le connecteur DS3231-PI permet de monter une horloge temps réel (RTC) afin que le module puisse être autonome lors d’automatisation basée sur l’horodatage.


→ Astuce : ce même connecteur peut aussi être utilisé pour gérer un afficheur I2C, ou tout autre dispositif sur bus I2C.

## 2.7 UPDI

C’est le connecteur qui permet la programmation du module, référez vous au chapitre « Programmation ».

- Il faut débrancher l’alimentation principale lors de la programmation.

# 3 Montage de la carte

Il est conseillé de souder en premier les composants CMS puis ensuite les traversants.

- La carte processeur MLT3216 peut être soudée directement mais il est conseillé de la mettre sur support afin de faciliter la programmation de celle-ci lorsque le montage est complet et en production.

## 3.1 Schéma


## 3.2 Nomenclatures

Repère | Valeur/référence | Qté | Commentaire
D1 | 1N4004 | 1Ou équivalent
DS3231-PI | Pin header femelle 2.54 1x5 | 1
J1,OUT1 | KF128L-3.81-3P | 2
J2,J3,J4,J5 | KF128L-3.81-2P | 4
K1 | HFD4/5 | 1
LED1 | SKC6812MINI-RV | 1
REG | R-78E5.0-1.0 | 1Version 0.5A possible
PWR | KF301-5.0-2P | 1
Q1 | BS170 | 1
R1 | 200Ω | 1
R2 | 22kΩ | 1
RJ1, RJ2, RJ3 | 4.7kΩ | 3Adaptable selon besoin
U1A,U1B | Pin header Femelle 2.54 1x10 | 2
U3 | L78L33 | 1
U2 | Module LoRa RA-02 (connecteur 2x4) | 1

# 4 Programmation

La programmation utilise « MegaTinyCore », un projet Github prévu pour tous les microprocesseurs de la gamme Mega/Tiny de la série 0/1/2.

https://github.com/SpenceKonde/megaTinyCore

Dans le projet on trouve toute la documentation afin de transformer un simple Arduino (Uno, Nano) en programmateur UPDI.

Toutes les librairies utiles sont incluses dans le package MegaTinyCore ou l’IDE Arduino, sauf la libraire dédiée à LoRa2HA : MLiotComm.

https://github.com/PM04290/MLiotComm

- Si vous avez installé une ancienne version (< 2.0), il faut la re-télécharger.

La librairie MLiotElements permet de gérer facilement tous les capteurs/actionneurs des modules. Elle n’est pas indispensable si vous créez votre propre programme, mais obligatoire si vous recompilez les firmwares par défaut.

Depuis la version 1.0 des HUB, ces derniers permettent la programmation des ATtiny3216 à l’aide du connecteur UPDI , voir le chapitre « Programmation UPDI » de la documentation principale.

# 5 Utilisation

Avec les Firmwares fournis dans le projet, lors de la première utilisation, la carte MLT3216 va s’initialiser avec des valeurs par défaut :
- Numéro (UID) = 40
- Numéro du Hub (HUID) = 0

Pour appairer le module avec le HUB, il faut :
1. maintenir le bouton CFG lors de la mise sous tension ; la LED va clignoter (1Hz)
2. relâcher le bouton CFG avant 10s (si vous tenez appuyé durant plus de 10s, les données internes vont être ré-initialisées)
3. la LED va s’allumer durant la transmission des informations vers le HUB (il doit être en mode
« Active pairing »)
4. après transmission, la LED clignote lentement
5. lors de la fin du paramétrage par le HUB (Finish Pairing), le module passe en mode « normal », la LED s’éteint.

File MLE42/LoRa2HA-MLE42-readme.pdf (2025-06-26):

# LoRa2HA

# MLE42


## Table des matières

# 1 Description

Le module MLE42 permet la gestion de 4 entrées et 2 sorties relais ou 1 moteur (bidirectionnel).

Il fonctionne avec une alimentation externe : 5V ou 8-28V.

# 2 Caractéristiques techniques

Le module doit fonctionner avec une carte d’extension MLT3216, c’est elle qui possède le microprocesseur.

Pour les caractéristiques techniques du microprocesseur, voir la documentation de la carte MLT3216.

Attention de monter la carte MLT3216 dans le bon sens, en suivant la position du bouton CFG (un montage à l’envers n’est pas destructif, mais cela marchera beaucoup moins bien).


Les connecteurs de la carte sont les suivants :

- capteurs ☐
- contact sec, moteur ☐
- alimentation ☐



## 2.1 Entrées capteurs

La carte comporte 5 connecteurs à vis, permettant de brancher les différents capteurs.

- J1 : capteur binaire ou analogique, avec alimentation 5 V
- J2, J3, J4 : capteur binaire ou analogique
- I2C : capteur ou module I2C

Les entrées J1, J2, J3 et J4 sont équipées d’un « pont résistif » pour certain capteur analogiques, les valeurs des résistances sont de 4.7KΩ.

## 2.2 Sortie contact sec/moteur

Les connecteurs OUT1 et OUT2 fournissent un contact sec, il peuvent aussi permettre de piloter certains équipements avec une très faible puissance : < 1 A.

Le connecteur MOT permet d’alimenter un moteur DC de faible puissance. Le moteur peut être alimenté avec 2 types d’alimentation possible à l’aide du sélecteur SW :

- sur Vin, le moteur sera alimenté directement par le connecteur PWR
- sur 5V, le moteur sera alimenté en 5 V par le régulateur REG. Le courant du moteur ne devra pas excéder le courant fourni par le régulateur : 1 A moins la consommation de la carte.

## 2.3 Alimentation

Le module est alimenté par le connecteur PWR.

Si l’alimentation est directement du 5 VDC, il n’est pas utile de monter le régulateur REG, mais il faut faire un

« shunt » en reliant les deux pastilles indiquées sur le PCB (out et in) comme indiqué ci-dessous.


Lorsque le régulateur REG est monté, il accepte une tension d’entrée comprise entre 8 et 28 VDC.

- Ce régulateur ne peut fournir que 1 A, il est donc conseillé de faire un bilan énergétique des tous les équipements qui pourraient être connectés au module : capteur, actionneur, led, rtc.

## 2.4 Module LoRa

Le module LoRa est un RA-02, en 433MHz, il est conseillé de lui connecter une antenne adaptée à la distance souhaitée ; généralement une antenne supérieure à 3 dBi permet de couvrir une distance d’au moins 500m.

## 2.5 LED

La led LED1 permet de contrôler le fonctionnement du module. C’est une led adressable de type WS2812 et il est possible d’étendre le nombre de led en utilisant le connecteur H1.

- Attention à ne pas dépasser la limitation en courant imposé par le régulateur. Si l’alimentation est directement du 5V, il faudra dimensionner correctement celle-ci.

## 2.6 RTC

Le connecteur DS3231-PI permet de monter une horloge temps réel (RTC) afin que le module puisse être autonome lors d’automatisation basée sur l’horodatage.


→ Astuce : ce même connecteur peut aussi être utilisé pour gérer un afficheur I2C, ou tout autre dispositif sur bus I2C.

## 2.7 UPDI

C’est le connecteur qui permet la programmation du module, référez vous au chapitre « Programmation ».

- Il faut débrancher l’alimentation principale lors de la programmation.

# 3 Montage de la carte

Il est conseillé de souder en premier les composants CMS puis ensuite les traversants.

- La carte processeur MLT3216 peut être soudée directement mais il est conseillé de la mettre sur support afin de faciliter la programmation de celle-ci lorsque le montage est complet et en production.

## 3.1 Schéma


## 3.2 Nomenclatures

Repère | Valeur/référence | Qté
U1A,U1B | Pin header femelle 2.54 1x10 | 2
U2 | Module LoRa RA-02 | 1
U3 | L78L33 | 1
OUT1,J1,OUT2 | KF128L-3.81-3P | 3
J2,J3,J4 | KF128L-3.81-2P | 3
DS3231-PI | Pin header mâle 1x5 | 1
LED1 | SKC6812MINI-RV | 1
K1,K2 | HFD4/5 | 2
Q1,Q2 | BS170 | 2
D1,D2 | 1N4004 | 2
R2,R4 | 22kΩ | 2
R1,R3 | 200Ω | 2
RJ1, RJ2, RJ3 | 4.7KΩ (optionnal) | 3
PWR | KF301-5.0-2P | 1
REG | R-78E-5.0 | 1
SW | Pin header mâle 1x3 | 1

# 4 Programmation

La programmation utilise « MegaTinyCore », un projet Github prévu pour tous les microprocesseurs de la gamme Mega/Tiny de la série 0/1/2.

https://github.com/SpenceKonde/megaTinyCore

Dans le projet on trouve toute la documentation afin de transformer un simple Arduino (Uno, Nano) en programmateur UPDI.

Toutes les librairies utiles sont incluses dans le package MegaTinyCore ou l’IDE Arduino, sauf la libraire dédiée à LoRa2HA : MLiotComm.

https://github.com/PM04290/MLiotComm

- Si vous avez installé une ancienne version (< 2.0), il faut la re-télécharger.

La librairie MLiotElements permet de gérer facilement tous les capteurs/actionneurs des modules. Elle n’est pas indispensable si vous créez votre propre programme, mais obligatoire si vous recompilez les firmwares par défaut.

Depuis la version 1.0 des HUB, ces derniers permettent la programmation des ATtiny3216 à l’aide du connecteur UPDI , voir le chapitre « Programmation UPDI » de la documentation principale.

# 5 Utilisation

Avec les Firmwares fournis dans le projet, lors de la première utilisation, la carte MLT3216 va s’initialiser avec des valeurs par défaut :
- Numéro (UID) = 30
- Numéro du Hub (HUID) = 0

Pour appairer le module avec le HUB, il faut :
1. maintenir le bouton CFG lors de la mise sous tension ; la LED va clignoter (1Hz)
2. relâcher le bouton CFG avant 10s (si vous tenez appuyé durant plus de 10s, les données internes vont être ré-initialisées)
3. la LED va s’allumer durant la transmission des informations vers le HUB (il doit être en mode
« Active pairing »)
4. après transmission, la LED clignote lentement
5. lors de la fin du paramétrage par le HUB (Finish Pairing), le module passe en mode « normal », la LED s’éteint.

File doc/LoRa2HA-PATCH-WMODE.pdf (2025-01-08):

# LoRa2HA

## PATCH

A partir de la version 0.6 du firmware, un « sélecteur » WMODE permet de choisir le type de réseau au démarrage :
- Wifi STA
- Wifi AP
- Ethernet (si disponible)

Ce choix est basé sur une mesure de tension :
- Vcc (3.3v) : Wifi STA (mode par défaut sur MLH1 et MLH4, la pin est en INPUT_PULLUP)
- Gnd (0v) : Wifi AP
- Vcc/2 (1.65v) : Ethernet (ce mode est valide si la tension est comprise entre 0.1v et 3.2v, 125/3970 sur l’ADC 12 bits de l’ESP32)

## MLH1


La pin 13 est utilisée, un interrupteur ou jumper peut être placé entre cette pin et le GND (disponible sur H1, H2).
Interrupteur ouvert : Wifi STA
Interrupteur fermé : Wifi AP

Module : MLH1, MLH2, MLH3, MLH4 Version PCB : 1.x

## MLH2


La pin 32 est utilisée, un interrupteur 3 positions peut être raccordé selon le schéma suivant :


Le 5v et Gnd peuvent être pris sur H1 ou H2.
Le branchement d’un interrupteur 2P3T est le suivant :


L’interrupteur 3 positions peut être remplacé par un câblage direct si vous souhaitez rester en mode Ethernet, raccordez 2 et 3.

## MLH3


La pin utilisée est la 32, le montage est le même que pour la carte MLH2.

## MLH4


La pin 32 est utilisée, un interrupteur ou jumper peut être placé entre cette pin et le GND (disponible sur H1, H2).
Interrupteur ouvert : Wifi STA
Interrupteur fermé : Wifi AP

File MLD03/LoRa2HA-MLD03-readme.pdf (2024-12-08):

# LoRa2HA

# MLD03

# Piscine – Arrosage 2 voies


## Table des matières

# 1 Description

Le module MLD03 est dédié à la gestion de piscine (hors chimie) ou d’arrosage (2 voies, ou arrosage / pompage), il est prévu pour pouvoir être fixé sur rail DIN à l’aide de fixations DRG-02


Il est autonome et possède un module RTC secouru par une pile CR2032 ce qui lui permet de conserver l’horodatage en cas de coupure de l’alimentation générale.

Pour une piscine, le module permet :

- La gestion de la durée filtration,
- La gestion du remplissage,
- La gestion du mode « Hors-gel »,
- Le suivi de la pression du filtre, pour nettoyage.

Pour de l’arrosage, le module permet :

- La gestion multicritère horaire de l’arrosage,
- La commande d’une pompe
- Le suivi de l’humidité du sol
- La détection de pluie
- Le suivi de niveau de cuve d’eau

# 2 Caractéristiques techniques

## 2.1 Microprocesseur

Le processeur utilisé est un ATtiny3216 :

- 32 KB In-system self-programmable Flash memory
- 256 bytes EEPROM
- 2 KB SRAM
- 16/20 MHz low-power internal RC oscillator
- 32.768 kHz Ultra Low-Power (ULP) internal RC oscillator
- Speed Grades:
- 0-5 MHz @ 1.8V – 5.5V
- 0-10 MHz @ 2.7V – 5.5V
- 0-20 MHz @ 4.5V – 5.5


Le schéma de connexion est le suivant :


## 2.2 Entrées

La carte comporte 5 connecteurs à vis, permettant de brancher les différents capteurs.

## 2.2.1 JI1, JI2, JI3

Ces 3 connecteurs permettent de brancher 3 capteurs analogiques (JI3 fourni en plus une alimentation 5 VDC).

Le schéma par défaut propose une résistance de 1K (RJ1, RJ2) afin de créer un pont diviseur si le capteur fourni une tension (résistif), RJ3 ne sera montée que si le capteur nécessite un pont diviseur.


## 2.2.2 JI4

Le connecteur JI4 est configurable et permet de brancher, soit un capteur analogique, soit un capteur sur bus I2C.


Pour une utilisation en mode I2C, les switch 1 et 2 doivent être sur ON et les autres sur OFF.

Pour une utilisation avec capteur analogique, le switch 3 doit être sur ON, 1 et 2 sur OFF. Le switch 4 sur ON si il faut un pont diviseur (RJ4) sinon sur OFF.

## 2.2.3 JI5

Ce connecteur fourni une alimentation 5 VDC.

## 2.2.4 Mode « piscine »

Dans le firmware par défaut, la configuration du mode « Piscine », est la suivante :

- JI1, JI2 : Thermistance NTC 5K (si la thermistance fait 10K, il est conseillé RJ1/2 = 2,7K)
- JI3 : transducteur de pression, fournissant 0.5 à 4.5 v pour la plage 0 à « psi max ».
- JI4 : capteur de niveau d’eau (SWJ4 à configurer selon le modèle)
- JI5 : est disponible pour l’alimentation de certains capteurs, si besoin

## 2.3 Sorties

Le 2 sorties principales sont des relais, K1 et K2, pour piloter respectivement une électrovanne (connecteur VALVE) et une pompe (connecteur PUMP).

Les relais sont raccordés aux connecteurs en mode NO (Normalement Ouvert), ce qui signifie qu’a l’arrêt du système le courant ne circule pas sur le connecteur, et il faut donc « activer » le relais pour que le courant circule.

Le schéma de câblage des équipements est le suivant :


Les deux connecteurs de K1 et K2 sont totalement indépendants de la carte et peuvent laisser passer n’importe quel type de tension : VAC/VDC, dans la limite des caractéristiques des relais HF41F :

## 2.4 Alimentation

Si l’alimentation est directement du 5 VDC, il n’est pas utile de monter le régulateur REG1, mais il faut faire un « shunt » en reliant les deux pastilles indiquées sur le PCB (1 et 3).


Lorsque le régulateur REG1 est monté, il accepte une tension d’entrée comprise entre 7 et 30 VDC.

## 2.5 Indicateurs LED

Ce sont des leds WS2812D-F5, donc RGB adressables.

Elles sont utilisées pour servir d’indicateur local de bon fonctionnement ou d’erreur.

Le descriptif ci-dessous correspond au firmware « Piscine ».

## 2.5.1 LED0

A la mise sous tension elle est affichée en BLEU, si une erreur est détectée lors de l’initialisation du système, il y a un clignotement de 3 coups brefs en ROUGE.

Lorsque le système a démarré, si tout est correctement initialisé elle clignote à la période de 1 seconde en VERT, ou en ROUGE si au moins une erreur a été détectée.

## 2.5.2 LED1

Elle est allumée en VERT quand le relais K1 (VALVE) est activé.

## 2.5.3 LED2

Elle est allumée en VERT quand le relais K2 (PUMP) est activé.

## 2.6 Module LoRa

Le module LoRa est un RA-02, en 433MHz, il est conseillé de lui connecter une antenne adaptée à la distance souhaitée ; généralement une antenne de 3 dbi permet de couvrir une distance d’au moins 2Km.

## 2.7 RTC

Le maintien de l’horodatage, quand la carte n’est pas alimentée, est assuré par un module DS1307 et une pile de type CR2032.

En utilisation avec un HUB LoRa2HA (MLH01, 02, 03, 04), une mise à l’heure est reçue une foi par jour et corrige ainsi tout dérive excessive du module.

- Lors de l’hivernage, si le module n’est pas utilisé, il est recommandé d’enlever la pile. Lors de la remise en service, la mise à l’heure sera effectuée automatiquement via le HUB.

## 2.8 CN1

Ce connecteur (JST XH) est prévu pour des extensions futures, comme :

- Afficheur OLED
- Platine de boutons de commandes locales
- etc...

## 2.9 SERIAL

Ce connecteur est plus particulièrement dédié au « Debug » mais peut aussi bien servir pour dialoguer avec des équipements adaptés (en modifiant le code du firmware).

Le connecteur est configuré de telle manière qu’il puisse directement être utilisé avec les cartes du type ci-dessous, très courantes chez les vendeurs en ligne. Si la carte sert d’alimentation elle doit être configurée en 5V.

## 2.10 UDPI


C’est le connecteur qui permet la programmation du module, référez vous au chapitre « Programmation ».

Il est recommandé d’utiliser le type de pince ci-dessous pour effectuer la programmation.


- Il faut débrancher l’alimentation principale lors de la programmation.

## 2.10.1 RST

Le bouton RST sert à effectuer un « reset » de la carte pour la ré-initialiser (prévision pour le futur, la version actuelle n’est pas fonctionnelle).

## 2.10.2 CFG

Ce bouton sert à envoyer la configuration au HUB lors de la première utilisation, il doit être enfoncé lors du démarrage, il y a un clignotement VERT de LED0 durant l’appui pour indiquer qu’il a bien été pris en compte. Une foi relâché, le démarrage continu et le module enverra sa configuration au HUB.

# 3 Montage de la carte

Il est conseillé de souder en premier les composants CMS puis ensuite les traversants.

## 3.1 Schéma


## 3.2 Nomenclatures

Article | Identification/marquage | Quantité
ATTINY3216 | U1 | 1
KF301-5.0-2P | JPW,PUMP,VALVE | 3
DIP switchEI-04 | SWJ4 | 1
KF128L-3.81-3P | JI3 | 1
KF128L-3.81-2P | JI4,JI1,JI2,JI5 | 4
Résistance 1K | RJ1,RJ2,RJ4 [RJ3] | 3
R-78E5.0-1.0 | REG1 | 1
HF41F/5 | K1,K2 | 2
Condensateur polarisé 470uF | C1 | 1
Condensateur céramique 100nF | C2,C3 | 2
SW-SMD-6X3R5X4R3 | CFG,RST | 2
JST XH | CN1 | 1
1N4448 | D1,D2 | 2
BS170 | Q1,Q2 | 2

Résistance 200Ω | R1,R4 | 2
Résistance 22kΩ | R2,R3 | 2
Résistance 47kΩ | R5 | 1
HDR-F-2.54_1x6 | SERIAL | 1
LORA RA-02 | U2 | 1
AMS1117-3.3 | U3 | 1
HDR-F-2.54_1x3 | UDPI | 1
CR2032 | B1 | 1
DS1307N | U4 | 1
Oscillateur 32.768KHZ | X1 | 1

# 4 Programmation

La programmation utilise « MegaTinyCore », un projet Github prévu pour tous les microprocesseurs de la gamme Mega/Tiny de la série 0/1/2.

https://github.com/SpenceKonde/megaTinyCore

Dans le projet on trouve toute la documentation afin de transformer un simple Arduino (Uno, Nano) en programmateur UDPI.

Toutes les librairies utiles sont incluses dans le package MegaTinyCore ou l’IDE Arduino, sauf la libraire dédiée à LoRa2HA : Radiolink (version 2.0 obligatoire).

https://github.com/PM04290/RadioLink

- Si vous avez installé une ancienne version, il faut la re-télécharger.

# 5 Utilisation

Avec les Firmwares fournis dans le projet, lors de la première utilisation, la carte MLT3216 va s’initialiser avec des valeurs par défaut :
- Numéro (UID) = 30
- Numéro du Hub (HUID) = 0

Pour appairer le module avec le HUB, il faut :
1. maintenir le bouton CFG lors de la mise sous tension ; la LED va clignoter (1Hz)
2. relâcher le bouton CFG avant 10s (si vous tenez appuyé durant plus de 10s, les données internes vont être ré-initialisées)
3. la LED va s’allumer durant la transmission des informations vers le HUB (il doit être en mode
« Active pairing »)
4. après transmission, la LED clignote lentement
5. lors de la fin du paramétrage par le HUB (Finish Pairing), le module passe en mode « normal », la LED s’éteint.

# 6 Annexe

Voici quelques liens permettant d’acheter les différents composants ou outillage connexe, pour un montage « Piscine ».

Outillage

Support rail DIN : (DRG-02)

https://fr.aliexpress.com/item/32834853066.html

Pince de programmation :

https://fr.aliexpress.com/item/1005004258921308.html

Composants carte

Relais : (5v)

https://fr.aliexpress.com/item/1005004360170067.html

Module RA-02 : (celui avec le connecteur 4x2)

https://fr.aliexpress.com/item/1005004992009022.html

Connecteurs KF128, 3.81 :

https://fr.aliexpress.com/item/1005002424998185.html

Connecteurs KF301 5.0 :

https://fr.aliexpress.com/item/1005001341135808.html

Bouton poussoir SMD : 3x6x4.3

https://fr.aliexpress.com/item/32884600594.html

DIP switch : 4 bits

https://fr.aliexpress.com/item/1005004848151376.html

Régulateur AMS1117 : 3.3

https://fr.aliexpress.com/item/1005004908874511.html

Assortiment de condensateur CMS : 0805

https://fr.aliexpress.com/item/1005006157020955.html

Assortiment de résistance CMS : 0805

https://fr.aliexpress.com/item/1005003021579348.html

Assortiment de diodes :

https://fr.aliexpress.com/item/1005006359972346.html

Mosfet BS170 :

https://fr.aliexpress.com/item/32694408264.html

Support batterie CR2032 :

https://fr.aliexpress.com/item/4001240194584.html

Régulateur R-78E3 : 1.0 1

https://fr.aliexpress.com/item/1005003137936602.html

ATTiny3216 : 2

https://fr.aliexpress.com/item/1005007202986972.html

Capteurs pour l’application « Piscine »

Thermistance NTC 5K :

https://fr.aliexpress.com/item/1005005314075798.html

Transducteur de pression : output 0.5-4.5v, pressions adaptée au filtre

https://fr.aliexpress.com/item/1005006317511174.html

Carte MPR121 pour capteur de niveau d’eau inductif : à souder sur le PCB ML90 (cf Github)

https://fr.aliexpress.com/item/1005006201984763.html

ou capteur binaire : XKC-Y25-V

https://fr.aliexpress.com/item/4001212670355.html

1 le régulateur se trouve moins cher chez les distributeurs institutionnels : RS, Mouser, Digikey, etc... 2 sur ce composant critique, rien ne garantit que Aliexpress livre un original.

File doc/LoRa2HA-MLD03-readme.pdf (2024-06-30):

# LoRa2HA

# MLD03

# Piscine – Arrosage 2 voies


## Table des matières

# 1 Description

Le module MLD03 est dédié à la gestion de piscine (hors chimie) ou d’arrosage (2 voies, ou arrosage / pompage), il est prévu pour pouvoir être fixé sur rail DIN à l’aide de fixations DRG-02


Il est autonome et possède un module RTC secouru par une pile CR2032 ce qui lui permet de conserver l’horodatage en cas de coupure de l’alimentation générale.

Pour une piscine, le module permet :

- La gestion de la durée filtration,
- La gestion du remplissage,
- La gestion du mode « Hors-gel »,
- Le suivi de la pression du filtre, pour nettoyage.

Pour de l’arrosage, le module permet :

- La gestion multicritère horaire de l’arrosage,
- Le suivi de l’humidité du sol
- La détection de pluie
- Le suivi de niveau de cuve d’eau

# 2 Caractéristiques techniques

## 2.1 Microprocesseur

Le processeur utilisé est un ATtiny3216 :

- 32 KB In-system self-programmable Flash memory
- 256 bytes EEPROM
- 2 KB SRAM
- 16/20 MHz low-power internal RC oscillator
- 32.768 kHz Ultra Low-Power (ULP) internal RC oscillator
- Speed Grades:
- 0-5 MHz @ 1.8V – 5.5V
- 0-10 MHz @ 2.7V – 5.5V
- 0-20 MHz @ 4.5V – 5.5


Le schéma de connexion est le suivant :


## 2.2 Entrées

La carte comporte 5 connecteurs à vis, permettant de brancher les différents capteurs.

## 2.2.1 JI1, JI2, JI3

Ces 3 connecteurs permettent de brancher 3 capteurs analogiques (JI3 fourni une alimentation 5 vdc).

Le schéma par défaut propose une résistance de 1K (RJ1, RJ2) afin de créer un pont diviseur si le capteur fourni une tension (résistif), RJ3 ne sera montée que si le capteur nécessite un pont diviseur.


## 2.2.2 JI4

Le connecteur JI4 est configurable et permet de brancher, soit un capteur analogique, soit un capteur sur bus I2C.


Pour une utilisation en mode I2C, les switch 1 et 2 doivent être sur ON et les autres sur OFF.

Pour une utilisation avec capteur analogique, le switch 3 doit être sur ON, 1 et 2 sur OFF. Le switch 4 sur ON si il faut un pont diviseur (RJ4) sinon sur OFF.

## 2.2.3 JI5

Ce connecteur fourni une alimentation 5 vdc.

## 2.2.4 Mode « piscine »

Dans le firmware par défaut, la configuration du mode « Piscine », est la suivante :

- JI1, JI2 : Thermistance NTC 5K (si la thermistance fait 10K, il est conseillé RJ1/2 = 2,7K)
- JI3 : transducteur de pression, fournissant 0.5 à 4.5 v pour la plage 0 à « psi max ».
- JI4 : capteur de niveau inductif sur bus I2C, SWJ4 est configuré en [ON ON OFF OFF]
- JI5 : est utilisé pour l’alimentation du capteur inductif I2C

## 2.3 Sorties

Le 2 sorties principales sont des relais, K1 et K2, pour piloter respectivement une électrovanne (connecteur VALVE) et une pompe (connecteur PUMP).

Les relais sont raccordés aux connecteurs en mode NO (Normalement Ouvert), ce qui signifie qu’a l’arrêt du système le courant ne circule pas sur le connecteur, et il faut donc « activer » le relais pour que le courant circule.

Le schéma de câblage des équipements est le suivant :


Les deux connecteurs de K1 et K2 sont totalement indépendants de la carte et peuvent laisser passer n’importe quel type de tension : VAC/VDC, dans la limite des caractéristiques des relais HF41F :

## 2.4 Alimentation

Si l’alimentation est directement du 5 VDC, il n’est pas utile de monter le régulateur REG1, mais il faut faire un « shunt » en reliant les deux pastilles indiquées sur le PCB (1 et 3).


Lorsque le régulateur REG1 est monté, il accepte une tension d’entrée comprise entre 7 et 30 VDC.

## 2.5 Indicateurs LED

Ce sont des leds WS2812D-F5, donc RGB adressables.

Elles sont utilisées pour servir d’indicateur local de bon fonctionnement ou d’erreur.

Le descriptif ci-dessous correspond au firmware « Piscine ».

## 2.5.1 LED0

A la mise sous tension elle est affichée en BLEU, si une erreur est détectée lors de l’initialisation du système, il y a un clignotement de 3 coups brefs en ROUGE.

Lorsque le système a démarré, si tout est correctement initialisé elle clignote à la période de 1 seconde en VERT, ou en ROUGE si au moins une erreur a été détectée.

## 2.5.2 LED1

Elle est allumée en VERT quand le relais K1 (VALVE) est activé.

## 2.5.3 LED2

Elle est allumée en VERT quand le relais K2 (PUMP) est activé.

## 2.6 Module LoRa

Le module LoRa est un RA-02, en 433MHz, il est conseillé de lui connecter une antenne adaptée à la distance souhaitée ; généralement une antenne de 3 dbi permet de couvrir une distance d’au moins 2Km.

## 2.7 RTC

Le maintien de l’horodatage, quand la carte n’est pas alimentée, est assuré par un module DS1307 et une pile de type CR2032.

En utilisation avec un HUB LoRa2HA (MLH01, 02, 03, 04), une mise à l’heure est reçue une foi par jour et corrige ainsi tout dérive excessive du module.

- Lors de l’hivernage, si le module n’est pas utilisé, il est recommandé d’enlever la pile. Lors de la remise en service, la mise à l’heure sera effectuée automatiquement via le HUB.

## 2.8 CN1

Ce connecteur (JST XH) est prévu pour des extensions futures, comme :

- Afficheur OLED
- Platine de boutons de commandes locales
- etc...

## 2.9 SERIAL

Ce connecteur est plus particulièrement dédié au « Debug » mais peut aussi bien servir pour dialoguer avec des équipements adaptés (en modifiant le code du firmware).

Le connecteur est configuré de telle manière qu’il puisse directement être utilisé avec les cartes du type ci-dessous, très courantes chez les vendeurs en ligne. Si la carte sert d’alimentation elle doit être configurée en 5V.

## 2.10 UDPI


C’est le connecteur qui permet la programmation du module, référez vous au chapitre « Programmation ».

Il est recommandé d’utiliser le type de pince ci-dessous pour effectuer la programmation.


- Il faut débrancher l’alimentation principale lors de la programmation.

## 2.10.1 RST

Le bouton RST sert à effectuer un « reset » de la carte pour la ré-initialiser.

## 2.10.2 CFG

Ce bouton sert à envoyer la configuration au HUB lors de la première utilisation, il doit être enfoncé lors du démarrage, il y a un clignotement VERT de LED0 durant l’appui pour indiquer qu’il a bien été pris en compte. Une foi relâché, le démarrage continu et le module enverra sa configuration au HUB.

# 3 Montage de la carte

Il est conseillé de souder en premier les composants CMS puis ensuite les traversants.

## 3.1 Schéma


## 3.2 Nomenclatures

Article | Identification/marquage | Quantité
ATTINY3216 | U1 | 1
KF301-5.0-2P | JPW,PUMP,VALVE | 3
DIP switchEI-04 | SWJ4 | 1
KF128L-3.81-3P | JI3 | 1
KF128L-3.81-2P | JI4,JI1,JI2,JI5 | 4
Résistance 1K | RJ1,RJ2,RJ4 [RJ3] | 3
R-78E5.0-1.0 | REG1 | 1
HF41F/5 | K1,K2 | 2
Condensateur polarisé 470uF | C1 | 1
Condensateur céramique 100nF | C2,C3 | 2
SW-SMD-6X3R5X4R3 | CFG,RST | 2
JST XH | CN1 | 1
1N4448 | D1,D2 | 2
BS170 | Q1,Q2 | 2

Résistance 200Ω | R1,R4 | 2
Résistance 22kΩ | R2,R3 | 2
Résistance 47kΩ | R5 | 1
HDR-F-2.54_1x6 | SERIAL | 1
LORA RA-02 | U2 | 1
AMS1117-3.3 | U3 | 1
HDR-F-2.54_1x3 | UDPI | 1
CR2032 | B1 | 1
DS1307N | U4 | 1
Oscillateur 32.768KHZ | X1 | 1

# 4 Programmation

La programmation utilise « MegaTinyCore », un projet Github prévu pour tous les microprocesseurs de la gamme Mega/Tiny de la série 0/1/2.

https://github.com/SpenceKonde/megaTinyCore

Dans le projet on trouve toute la documentation afin de transformer un simple Arduino (Uno, Nano) en programmateur UDPI.

Toutes les librairies utiles sont incluses dans le package MegaTinyCore ou l’IDE Arduino, sauf la libraire dédiée à LoRa2HA : Radiolink (version 2.0 obligatoire).

https://github.com/PM04290/RadioLink

- Si vous avez installé une ancienne version, il faut la re-télécharger.

# 5 Annexe

Voici quelques liens permettant d’acheter les différents composants ou outillage connexe, pour un montage « Piscine ».

Outillage

Support rail DIN : (DRG-02)

https://fr.aliexpress.com/item/32834853066.html

Pince de programmation :

https://fr.aliexpress.com/item/1005004258921308.html

Composants carte

Relais : (5v)

https://fr.aliexpress.com/item/1005004360170067.html

Module RA-02 : (celui avec le connecteur 4x2)

https://fr.aliexpress.com/item/1005004992009022.html

Connecteurs KF128, 3.81 :

https://fr.aliexpress.com/item/1005002424998185.html

Connecteurs KF301 5.0 :

https://fr.aliexpress.com/item/1005001341135808.html

Bouton poussoir SMD : 3x6x4.3

https://fr.aliexpress.com/item/32884600594.html

DIP switch : 4 bits

https://fr.aliexpress.com/item/1005004848151376.html

Régulateur AMS1117 : 3.3

https://fr.aliexpress.com/item/1005004908874511.html

Assortiment de condensateur CMS : 0805

https://fr.aliexpress.com/item/1005006157020955.html

Assortiment de résistance CMS : 0805

https://fr.aliexpress.com/item/1005003021579348.html

Assortiment de diodes :

https://fr.aliexpress.com/item/1005006359972346.html

Mosfet BS170 :

https://fr.aliexpress.com/item/32694408264.html

Support batterie CR2032 :

https://fr.aliexpress.com/item/4001240194584.html

Régulateur R-78E3 : 1.0 1

https://fr.aliexpress.com/item/1005003137936602.html

ATTiny3216 : 2

https://fr.aliexpress.com/item/1005007202986972.html

Capteurs pour l’application « Piscine »

Thermistance NTC 5K :

https://fr.aliexpress.com/item/1005005314075798.html

Transducteur de pression : output 0.5-4.5v, pressions adaptée au filtre

https://fr.aliexpress.com/item/1005006317511174.html

Carte MPR121 pour capteur de niveau d’eau inductif : à souder sur le PCB ML90 (cf Github)

https://fr.aliexpress.com/item/1005006201984763.html

ou capteur binaire : XKC-Y25-V

https://fr.aliexpress.com/item/4001212670355.html

1 le régulateur se trouve moins cher chez les distributeurs institutionnels : RS, Mouser, Digikey, etc... 2 sur ce composant critique, rien ne garantit que Aliexpress livre un original.

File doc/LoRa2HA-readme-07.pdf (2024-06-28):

# LoRa2HA

Document version 0.7

# Introduction

LoRa2HA est un ensemble d’équipements permettant une interconnexion entre des capteurs éloignés et un serveur HomeAssistant (via MQTT) par radio en utilisant des modules LoRa.

Le HUB, à base d’ESP32 (Wifi ou Ethernet), permet la collecte des données radio et les envoi vers Home Assistant (H.A.) au travers d’un serveur MQTT. Le terme de HUB sera utilisé, et non Gateway, afin de ne pas créer de confusion avec les Gateway « LoRaWan ».

Le projet contient les sources de tous les firmwares, les schémas des cartes ainsi que les « Gerber » afin de pouvoir les fabriquer.

### LoRa2HA

## Sommaire

# 1 Les équipements

Les références des modules adoptent la terminologie suivante :

- ML : Module LoRa (et non Matière & Lumière ) 😄
- H : Hub, D : Dédié, E : alimentation Externe, A : alimentation Autonome
- un nombre indiquant un ordre de création (Ex : Hub et Dédié) ou un nombre d’entrées sorties (Ex 21 = 2 entrées / 1 sortie), éventuellement suivi d’un ordre de création.

## 1.1 Les HUB

Il existe 4 types de HUB selon le besoin, tous équipés d’un module LoRa :

- MLH1 : Avec un ESP32-S2 Mini, en wifi
- MLH2 : Avec un Olimex-POE-ISO, en Ethernet avec POE
- MLH3 : Avec un WT32-ETH01, en Ethernet
- MLH4 : Avec un ESP32-D1-Mini, en wifi

Le HUB dispose de son propre serveur web permettant le paramétrage de la connexion à H.A. ainsi que l’identification des tous les capteurs sur le terrain.

## 1.2 Les modules « capteurs/actionneurs »

A ce jour il existe 3 types de modules, et 4 projets en cours :

- MLD01 : Relevé TIC Linky (alimenté par USB externe)
- MLD02 : Relevé TIC Linky (alimenté par Linky) (projet en cours)
- MLD03 : Gestion de piscine (hors chimie)
- MLE21 : 2 entrées / 1 sortie, alimenté en 8-32vdc
- MLE12 : 1 entrée / 2 sorties, alimenté en 8-32vdc (projet en cours)
- MLA30 : 3 entrées, autonome, basse consommation, avec batterie et panneau solaire
- MLA10-1 : Télécommande 1 bouton (ou contact sec), sur pile CR2450 (projet en cours)
- MLA10-2 : 1 bouton (ou contact sec), sur pile CR2030 ou batterie

Chaque module possède un Firmware par défaut mais il est possible d’adapter celui-ci pour en modifier les fonctionnalités.

Un module codeur (ML99) permet de donner une adresse à chaque module (à base d’ATtiny84) lors de l’installation, sans avoir besoin de le reprogrammer.

# 2 Fonctionnement

Home Assistant MQTT; HUB MLHx; Module MLxxx; Lora; capteur capteur

Chaque module (MLxxx) transmet les informations des capteurs (par LoRa) vers le HUB, connecté à H.A. (MQTT) par IP, ce dernier va pouvoir rediriger les informations.

❗️ATTENTION : le choix des antennes et leur position sont particulièrement importants.

Il est conseillé d’installer une antenne à gain important sur le HUB (> 2 dBi).

L’antenne ressort des module RA-01, ainsi que les antennes « bâton » (généralement avec connecteur SMA) doivent être utilisées à la verticale.


Les antennes IPX sur PCB comme ci-contre (jonction au milieu) doivent être
utilisées à plat, verticales et perpendiculaires à l’azimut du HUB.


Exemple de choix d’antenne que vous pouvez installer sur le HUB, avec un convertisseur IPX/SMA, sur un module RA-02 : https://fr.aliexpress.com/item/1005003818758184.html

# 3 Mise en route

Cela commence par l’installation et le configuration du HUB.

H.A. doit avoir un serveur MQTT en état de fonctionnement.

## 3.1 Installation du HUB

→ Pour la programmation du HUB, voir le chapitre « Programmation »

Le HUB une foi programmé (ou reçu prêt à l’emploi) doit être raccordé au réseau IP (identique à celui de H.A.).

Dans le cas d’un HUB wifi, ce dernier ne connaissant pas les informations de votre wifi, il est passé automatiquement en mode « Point d’accès ». Cherchez un réseau wifi nommé « lora2ha0 » et connectez-vous ; le mot de passe est : 12345678.

Le HUB est à l’adresse IP 192.168.4.1 ou l’URL lora2ha0.local ; la page ci-dessous doit s’afficher.

❗️ Si la page ne s’affiche pas, il est probable que le dossier « data », contenant les serveur web, n’ai pas été téléchargé.

Oui, c’est en anglais… mais très simple 😄


Ouvrez la zone « Network & Radio », renseignez les données demandées puis enregistrez.

L’information de l’adresse MAC vous permet de pouvoir gérer votre serveur DHCP et affecter une adresse IP spécifique.

Si vous envisagez de mettre plusieurs HUB sur le réseau, il faut indiquer un code unique à chacun dans « UID Code » (sinon laissez 0) ; il est conseillé de mettre « 1 » au premier HUB que vous paramétrez et laisser « 0 » pour le suivant.

Selon le modem LoRa qui est utilisé, vous devez indiquer la fréquence 433 ou 868 (MHz).

Dans « Mqtt host » indiquez uniquement l’adresse IP du serveur Mqtt (ou celle de H.A. si Mqtt y est intégré en Add-on).

☞ Le port par défaut est le 1883 (pas de SSL). Un prochaine version permettra d’utiliser SSL.

Le configuration NTP sert au HUB pour « publier » l’heure vers les différents modules qui en ont besoin.

Une fois sauvegardé, il faut redémarrer le HUB, physiquement ou en cliquant sur le bouton « Reset » dans la zone « Tools ».

Le wifi du point d’accès du HUB devrait être perdu et si il n’y a pas de problème dans le paramétrage il a dû se connecter au wifi qui a été configuré, vous pouvez accéder à la même page web, via votre réseau, à l’adresse « lora2ha0.local ».

Le HUB est prêt à recevoir les informations radio des « modules capteurs ».


## 3.1.1 Mise à jour du Firmware

Le firmware peut être mis à jour par OTA (Other The Air), cliquant sur le bouton « Parcourir » de la zone « Update firmware », de sélectionner le fichier contenant le Firmware (avec un extension .bin), le nom contient en général le type d’ESP32 qui est utilisé, et enfin cliquer sur le bouton « Update ».

Le téléchargement prend entre 5 et 10 secondes, l’ESP32 redémarre et la page est web rechargée.

## 3.1.2 Mise à jour de fichiers

Tous les fichiers du serveur web peuvent être mis à jour en cliquant sur le bouton « Parcourir » de la zone « Send file », de sélectionner le fichier dans le dossier « data », et enfin de cliquer sur le bouton « Send ».

L’ESP32 ne redémarre pas mais la page web est rechargée.

Si vous avez envoyé un nouveau fichier de configuration, il faut redémarrer l’ESP32 pour qu’il soir pris en compte.

## 3.2 Installation des modules capteurs

→Pour la programmation du module, voir le chapitre « Programmation »

Une foi programmé (ou reçu tout prêt), le module doit avoir une adresse unique.

Si vous n’avez qu’un seul module il n’y a rien à faire, il aura son adresse par défaut.

Pour affecter une adresse il faut connecter le boîtier « codeur » (ML99) sur le connecteur ICSP du module, choisir l’adresse à l’aide des 2 encodeurs rotatifs, par exemple pour l’adresse 31 il faut mettre 3 sur 10X et 1 sur 1X. Alimentez le module et celui-ci prendra directement l’adresse indiqué. Après quelques secondes vous pouvez débrancher le module et déconnecter la carte ML99.

Lors du démarrage d’un module, celui-ci envoi sa configuration au HUB . Si il s’agit du premier démarrage du module et que la configuration du HUB ne connaît pas le module, ce dernier est ajouté automatiquement et il ne reste plus qu’a compléter certains paramètres manquants : Classe, Unité, etc.

Depuis la version 0.7, pour que le Module envoi sa configuration complète, il faut démarrer ce dernier en appuyant sur le bouton « CFG » (pin RST du module LoRA à la masse, si le bouton n’est pas câblé).

## 3.2.1 Module MLD01 Linky

Le module est à l’adresse « 10 » par défaut (elle ne peut pas être changée, sauf à modifier le firmware et reprogrammer le module).

Le code source proposé, fonctionne en mode « Historique » par défaut, avec très peu de modification il est possible de le faire fonctionner en mode « standard ».

Le module ayant une forte consommation, il n’est pas possible d’utiliser l’alimentation fournie par le connecteur TIC du Linky (borne A), il devra donc avoir sa propre alimentation externe, type chargeur USB.

Connectez le module sur le connecteur TIC du linky : bornes I1 et I2.

Dans le Firmware par défaut (lora2ha-MLD01-Linky-ProMicro) vous disposez des informations référencées dans le tableau ci-dessous :

ID | Label linky | Donnée
1 | OPTARIF | BASE, HPHC/HCHP
2 | BASE | Compteur (KWh)
3 | HPHC | Compteur HC (KWh)
4 | HCHP | Compteur HP (KWh)
5 | PAPP | Puissance apparente (VA)
6 | INST (monophasé) INST1 (triphasé) | Intensité instantanée 1 (A)
7 | INST2 (triphasé) | Intensité instantanée 2 (A)
8 | INST3 (triphasé) | Intensité instantanée 3 (A)

## 3.2.2 Module MLD02 Linky (Autonome)

Ce module n’est pas encore validé.

## 3.2.3 Module MLD3 (Piscine)

Le module « Piscine » est plus particulièrement adapté aux piscines hors-sol, il peut être positionné à l’endroit où est branché la pompe du filtre, en utilisant la prise étanche tu type de celle ci-dessous.


Lien aliexpress : https://fr.aliexpress.com/item/1005005866444183.html

Le Module a été étudié pour s’intégrer au fond du boîtier.

Par défaut, le module est à l’adresse 23 mais peut être modifié dans le firmware.

Le module dispose de :

- 4 entrées analogiques (T° eau, T° air, Pression filtre, niveau d’eau)
- 1 bus I2C (niveau d’eau)
- 2 sortie relais (Pompe filtre, électrovanne remplissage)
- 1 module RTC pour gestion horaire autonome

### 3.2.3.1 Capteur sur J1

Le connecteur J1 permet de raccorder une thermistance afin de mesurer la température de l’eau, il est conseillé de prendre une NTC 5K avec une résistance RJ1 de 1K, ou une NTC de 10K avec une résistance RJ1 de 2.7K.

La température de l’eau permet de calculer la durée de filtration, par défaut : Durée (h) = T° / 2

Une température d’eau de 28° donnera un temps de filtration de 14h.

### 3.2.3.2 Capteur sur J2

Le connecteur J2 permet de raccorder une thermistance afin de mesurer la température de l’air, il est conseillé de prendre une NTC 5K avec une résistance RJ2 de 1K, ou une NTC de 10K avec une résistance RJ2 de 2.7K.

La température de l’air peut être utilisée pour la gestion du mode « Hors-gel », afin de déclencher la filtration lors des températures négatives.

### 3.2.3.3 Capteur sur J3 (ou CN1)

Le connecteur J3 permet de raccorder un capteur de niveau d’eau « analogique » ; le firmware par défaut utilise un capteur I2C raccordé sur CN1.

Il est aussi possible d’utiliser un capteur « tout ou rien » de type « chasse d’eau ».

Du fait des vaguelettes engendrées par la filtration et/ou la baignade, la gestion du niveau d’eau n’est activée que lorsque la filtration est stoppée, généralement la nuit.

### 3.2.3.4 Capteur sur J4

Le connecteur J4 permet de raccorder un capteur de pression afin de pouvoir surveiller l’encrassement du filtre.

### 3.2.3.5 Connecteurs PUMP, VALVE, J230

Le connecteur PUMP permet de raccorder la pompe de la filtration, si vous utilisez la prise étanche IP66, il faut le raccorder à la prise qui est installée sur le bloc.

Le connecteur VALVE permet de raccorder l’électrovanne servant au remplissage, ATTENTION, il faut une électrovanne 230VAC.

L’alimentation générale se fait à partir du connecteur J230.

## 3.2.4 Module MLE21 (2 in / 1 out)

Le module est à l’adresse « 20 » par défaut. Si vous installez plusieurs modules du même type, incrémentez l’adresse de chaque nouveau module (21, 22, etc.).

J1 permet d’alimenter le module en courant continu avec une tension comprise entre 7 et 35v.

J2 et J3 permettent de connecter les capteurs.

J4 permet de connecter la sortie du relais (NO ou NC).

### 3.2.4.1 Capteur sur J2

J2 permet de connecter plusieurs types de capteurs :

- analogique
- binaire (contact)

Si un capteur DS18B20 est raccordée, il faut monter la résistance RJ2 (4,7k).

Si un capteur résistif est raccordé, et qu’il y a besoin d’établir un pont de résistance pour la mesure, il faut mettre en RJ2 la résistance à votre pont.

Si un capteur binaire est monté, il ne faut pas monter RJ2.

### 3.2.4.2 Capteur sur J3

J3 accepte les capteurs analogiques et binaires.

Si un capteur résistif est raccordé, et qu’il y a besoin d’établir un pont de résistance pour la mesure, il faut mettre en RJ3 la résistance à votre pont.

Si un capteur binaire est monté, il ne faut pas monter RJ3.

### 3.2.4.3 Sortie relais sur J4

Le relais HFD4/5 installé permet de gérer sans problème un contact sec (type ouverture de portail), si il doit agir sur un équipement actif, voici ses caractéristiques :


Le connecteur J4 est utilisé pour connecter la sortie relais, sur NO (Normally Open) ou NC (Normally Close).

Le Firmware par défaut (lora2HA-MLE21-Portail.ino) permet la gestion d’un portail :

- J2 : contact sec de détection de portail ouvert
- J3 : bouton poussoir d’appel
- J4 : contact sec d’ouverture

## 3.2.5 Module MLA30 (3 in / 0 out)

Le module est à l’adresse « 50 » par défaut. Si vous installez plusieurs modules du même type, incrémentez l’adresse de chaque nouveau module (51, 52, etc.).

BAT permet de connecter une batterie 3.7v.

PV permet de connecter une cellule Photovoltaïque de 5V.

J4 permet de connecter la carte de gestion de charge batterie, type CRLD20MA.

J1 permet de connecter un capteur analogique, binaire ou de type DS18B20.

J2 permet de connecter un capteur analogique ou binaire.

J3 permet de connecter un capteur analogique ou binaire.

### 3.2.5.1 Capteur sur J1

J1 permet de connecter plusieurs types de capteurs :

- analogique
- binaire (contact)

Si un capteur DS18B20 est raccordée, il faut monter la résistance RJ1 (4,7k).

Si un capteur résistif est raccordé, et qu’il y a besoin d’établir un pont de résistance pour la mesure, il faut mettre en RJ1 la résistance à votre pont.

Si un capteur binaire est monté, il ne faut pas monter RJ1.

### 3.2.5.2 Capteur sur J2 et J3

J2 et J3 acceptent les capteurs analogiques et binaires.

Si un capteur résistif est raccordé, et qu’il y a besoin d’établir un pont de résistance pour la mesure, il faut mettre en RJ2 (ou RJ3) la résistance à votre pont.

Si un capteur binaire est monté, il ne faut pas monter RJ2 (ou RJ3).

## 3.2.5.3 Alimentation

L’alimentation du module peut se faire à partir d’une simple batterie connectée sur BAT.

Si une cellule solaire est connectée sur PV, il faut monter un module CRLD20MA sur le connecteur J4 afin de gérer la charge.

### - Attention, la batterie doit avoir une protection, le module CRLD20MA ne gère pas la protection de charge/décharge. Généralement, les batteries comme celles ci-dessous sont équipées d’une protection

## 3.2.6 Paramétrage des capteurs dans le HUB

Ouvre la zone « Devices ».


- « @ » est l’adresse par défaut du module ou celle que vous avez fixé avec le module ML99
- « Name » est le nom de l’appareil qui apparaîtra dans H.A.
- « RL ver » est le n° de version des paquets LoRa (laissez 0), cette donnée est en prévision de futures évolutions
- « ID » est le n° du capteur/actionneur, il est défini par le firmware de chaque module
- « Label » est le nom du capteur/actionneur qui apparaîtra dans H.A.
- « Data » est le type de donnée transmise par le module, il est définit par le firmware

Cliquez ensuite sur le bouton pour ouvrir la boite de dialogue permettant la configuration du capteur/actionneur pour H.A.

- « Type » permet de choisir dans une liste le type de capteur/actionneur dans H.A.
- « Class » selon le Type que vous avez choisi, il est possible d’avoir des classes différentes, vous trouvez les informations nécessaires sur la page web du site de Home Assistant : https://www.home-assistant.io/docs/configuration/customizing-devices/#device-class
- « Category » permet de classer le sensor en tant que Mesure, Diagnostic ou Configuration.
- « Unit » permet d’indiquer l’unité correspondant à la mesure du capteur
- « Expire after » est la durée pendant laquelle la mesure est valide (indisponible au sens H.A.).
- « Min » et « Max » permettent de borner les mesures reçues. Il peut arriver qu’il y ai des erreurs de mesure (ou autre) qui aboutissent à une donnée qui soit hors de sa plage normale, par exemple une consommation électrique de plus de 100 KW, si vous avez un abonnement 9KWh, vous pouvez entrer 10 000 dans max, par exemple.

Dans la zone « Class », commencez à taper le début du texte si vous connaissez la classe à attribuer, ou faite 2 fois 1 clic pour afficher la liste.

Pour ajouter un nouveau capteur/actionneur dans un module, clique sur le bouton « Add Child ».

Pour ajouter un nouveau module, cliquez sur le bouton « Add Device ».

Après avoir tout configuré, cliquez sur le bouton « Save all devices » et redémarrez le HUB (Physique ou « Tools / Reset ») pour recharger la novelle configuration.

- Pour supprimer un Module (Child), laissez la zone « Label » vide, il ne sera pas pris en compte lors de l’enregistrement.
- Pour supprimer un « Device », si il n’y a plus de « Child », laissez la zone «Name» vide, il ne sera pas pris en compte lors de l’enregistrement.

3.2.7 Contrôle dans H.A.

Dans H.A., cliquez sur « Paramètres » puis sur « Appareils et Services ».

Dans le bloc « MQTT » cliquez sur le nombre d’appareils pour afficher la liste des appareils connus.

Allez chercher « lora2ha0 » dans la liste et cliquez dessus, vous devriez obtenir une page dans ce style :


Si vous voyez apparaître des anciens capteurs ou contrôles (après changement de nom ou de type par exemple), il faut supprimer l’appareil en totalité, il sera re-créé lors du prochain redémarrage du HUB.

# 4 Montage des cartes

La liste complète des différents composants est fournie en Annexe A.

## 4.1 MLH1

La carte MLH1 doit être équipée d’un ESP32-S2 Mini.


Le module LoRa conseillé est en 433MHz, RA-01 (antenne filaire) ou RA-02 (connecteur IPX). Il sera privilégié le RA-02 pour de la longue distance en choisissant une antenne adaptée (> 2 Dbi).

Attention, il existe plusieurs modèles de modules LoRa, il faut celui avec le connecteur DIP 2x4 pins.


Exemples de lien de matériel :

RA-01 / RA-02 : https://fr.aliexpress.com/item/1005001593805902.ht ml

ESP32-S2 Mini : https://fr.aliexpress.com/item/1005004344359250.html

L’alimentation de la carte se fait au travers du connecteur USB de l’ESP32 (transfo séparé conseillé).

## 4.2 MLH2


La carte MLH2 doit être équipée d’un ESP32-POE-ISO, connecteur USB vers le bas (H1).

Il y a la possibilité d’utiliser la version « EA » avec une antenne IPX

Le connecteur H1 peut être utilisé pour l’alimentation (5V) si le POE n’est pas disponible.

Le connecteur H2 peut être utilisé (après modification du firmware) pour connecter une extension I2C, par exemple un écran Oled.

Le module LoRa est identique à la carte MLH1.

Exemple de lien d’achat : https://www.olimex.com/Products/IoT/ESP32/ESP32-POE-ISO/open-source-hardware (https://www.olimex.com/Products/IoT/ESP32/ESP32-POE-ISO/open-source-hardware)

## 4.3 MLH3


La carte MLH3 doit être équipée d’un WT32-ETH01.

Le module LoRa est identique à la carte MLH1.

L’alimentation se fait au travers d’une mini carte USB dont on utilisera uniquement les pins +5V et GND. Celle-ci peut être soudée directement sur la carte en utilisant le modèle donné en exemple d’achat, ou en utilisant un modèle à visser sur le boîtier et en la raccordant au connecteur.

La programmation s’effectue uniquement au travers du connecteur « PROG » à l’aide de n’importe quel convertisseur USB/TTL (type FT232), il doit avoir les pin : +5v, GND, TX, RX.

Exemple de liens d’achat :

- WT32-ETH01 : https://fr.aliexpress.com/item/1005002920674329.html
- USB-C : https://fr.aliexpress.com/item/1005002795893679.html
- USB/TTL : https://fr.aliexpress.com/item/1005005921832515.html

## 4.4 MLH4

La carte MLH4 doit être équipée d’un ESP32-D1-Mini.

Le module LoRa est identique à la carte MLH1.

Le connecteur H1 peut être utilisé pour l’alimentation (5V).

Le connecteur H2 peut être utilisé (après modification du firmware) pour connecter une extension I2C, par exemple un écran Oled.

Exemple de lien d’achat : https://fr.aliexpress.com/item/1005001621844145.html

## 4.5 MLD01

La carte MLD01 doit être équipée d’un Arduino Pro Micro (ATMega32U4).

Le module LoRa est identique à la carte MLH1.

Exemple de liens d’achats : https://fr.aliexpress.com/item/32846843498.html

→ Attention, sur la version v1.0 du PCB, il y a une petite erreur de routage, il faut relier les pin « 5 » et « RX » du ProMicro après avoir soudé celui-ci.

## 4.6 MLD03 (Piscine)


La carte MLD03 doit être équipée d’un ATtiny3232.

Le module LoRa est identique à la carte MLH1.

Le module RTC est un module « gigogne » type DS3231 Pi : https://fr.aliexpress.com/item/1005004861126782.html

Les relais sont du type HF41F, 6A max : https://fr.aliexpress.com/item/1005004360170067.html

Le module alimentation 230VAC / 5VDC est le modèle 5V/700mA ici : https://fr.aliexpress.com/item/1005005848999837.html

## 4.7 MLE21

La carte MLE21 doit être équipée d’un ATtiny84-20PU.

Le module LoRa est identique à la carte MLH1.

Exemple de liens d’achat :

- Convertisseur DC/DC : https://www.digikey.fr/fr/products/detail/recom-power/R-78E5-0-1-0/4930585
- Relais HFD4 5V : https://fr.aliexpress.com/item/1005004845392306.html

Il est possible d’alimenter directement la carte avec du 5V sur le connecteur J1, dans ce cas REG1 n’est pas monté mais il faudra relier les pastilles « in » et « out » de son connecteur .

## 4.8 MLA30


La carte MLA30 doit être équipée d’un ATtiny84-20PU.

Le module LoRa est identique à la carte MLH1.

La carte « chargeur » est de type CRLD20MA, 3.3V ; exemple de lien d’achat : https://fr.aliexpress.com/item/1005005478025758.html

Si la carte n’est pas montée, afin d’utiliser le module avec une alimentation 5V externe, vous avez les possibilités suivantes :

- Alimentation en VCC et GND sur J4
- Alimentation sur connecteur BAT et relier les points VCC et BAT de J4
- Alimentation sur connecteur PV et relier les points VCC et PV de J4

Conseils :

- Commencez par souder le régulateur « cms » U3, avec à minima le condensateur C3, C1 et C2 ne sont indispensable que si des parasites sont constatés sur l’alimentation.
- Montez un support pour l’ATtiny84

## 4.9 ML99

La carte ML99 doit être équipée d’un ATtiny84-20PU.

Les encodeurs 10 positions (DIP) doivent avoir les caractéristique suivantes :

### Exemple de lien d’achat : https://fr.aliexpress.com/item/1005002489382650.html

# 5 Programmation

Ce chapitre sous-entend que vous maîtrisez la programmation d’un Arduino, que ce soit les ATTiny ou les ESP32. Pour les ATtiny, il faut avoir un « programmateur » ou transformer un UNO (Nano) en Programmateur ISP.

Plusieurs tutos traitent de ces différents sujets si vous n’êtes pas un expert ; cherchez « ATtini84 programmer », en anglais vous aurez plus de réponse.

## 5.1 Prérequis

La librairie « RadioLink » doit être installée en téléchargeant le fichier zip sur le GitHub « PM04290 » (https://github.com/PM04290/RadioLink) et en le décompressant dans le dossiers des librairies Arduino ; pour les ATtiny84 la librairie « tinySPY » doit être installée en téléchargeant le fichier zip sur le GitHub https://github.com/JChristensen/tinySPI et en le décompressant dans le dossiers des librairies Arduino..

La librairie « HAintegration » doit être installée en téléchargeant le fichier zip sur le GitHub « PM04290 » (https://github.com/PM04290/HAintegration) et en le décompressant dans le dossiers des librairies Arduino.

## 5.2 Programmer le HUB

Il existe une manière simple de programmer le HUB si vous ne souhaitez pas recompiler tout le programme ; il suffit d’utiliser les fichiers de commandes (.bat) du dossier « tools ». Ce dossier embarque tous les exécutables permettant d’effectuer la programmation sans IDE Arduino.

Avec l’IDE Arduino, l’ESP32 doit être compilé avec le Core version ≥ 2.0.11 (pas la version 3 alpha, il reste trop de bug de compilation), et installer les add-on pour télécharger le dossier « Data » dans la mémoire flash de l’ESP32.

- Attention, pour l’ESP32-S2, le téléchargement du dossier « data » n’est, à ce jour, pas possible avec l’IDE (l’add-on ne sait pas le gérer) ; il faut donc utiliser le fichier de commande (dans « tools ») pour programmer celui-ci. Si vous adaptez le programme, il faudra « Exporter le binaire compilé » et le téléverser de la même manière.

Pour programmer les ESP32, il faut indiquer un lien à mettre dans « Préférences » de l’IDE pour avoir la liste des cartes ESP :

https://dl.espressif.com/dl/package_esp32_index.json

Vous devez avoir installé les librairies suivantes avec le gestionnaire de bibliothèque :

- ArduinoJson, version ≥ 7.0 (par Benoit Blanchon)
- AsyncTCP, version ≥ 1.1.4 (par dvarel)
- PubSubClient

Vous devez installer les librairies suivantes en décompressant le fichier zip dans le dossier des librairies Arduino :

- https://github.com/me-no-dev/ESPAsyncWebServer

Ouvrez le projet « lora2ha-HUB.ino », dans le fichier « config.h » dé-commentez la ligne #define USE_ETHERNET si vous utilisez une carte Ethernet au lieu de Wifi (Olimex-POE ou WT32-ETH01).

Sélectionnez le « Type de carte » adapté au HUB que vous programmez :

- MLH1 : LOLIN S2 Mini
- MLH2 : Olimex-POE_ISO
- MLH3 : WT32-ETH01 Ethernet module
- MLH4 : WEMOS D1 MINI ESP32 (ou MH ET LIVE ESP32MiniKit)

Si vous avez installé toutes les librairies requises, vous pouvez compiler et télécharger le firmware.

Utilisez l’add-on « ESP32 Sketch Data Upload » pour téléverser le dossier « data » contenant le serveur web.

## 5.3 Programmer le module MLD01 (Linky)

Installez la librairie «TeleInfo» à l’aide du gestionnaire de bibliothèque.

Ouvrez le projet « lora2ha-MLD01-Linky », choisissez le type de carte « Arduino Leonardo ».

Compilez et téléchargez le firmware à l’aide du câble USB connecté à la carte.

Si vous souhaitez utiliser « DEBUG_SERIAL », il faut savoir que la liaison série USB du moniteur (dans l’IDE) ne fonctionne correctement que suite à un téléchargement ; en effet, un simple « reset » sur le ProMicro ne permettra pas d’avoir la liaison série ouverte correctement, il faut légèrement modifier le code source.

## 5.4 Programmer les modules ATtiny84 (MLE21, MLA30, etc.)

Pour programmer les cartes équipées d’ATtiny84, il vous faut un programmeur ISP ; il peut être fait en utilisant un simple Arduino UNO (ou Nano).

Il existe plusieurs tutoriels sur le sujet, choisissez celui qui correspond le mieux à votre cas de figure.

Les cartes sont équipées d’un connecteur ICSP, il est possible d’utiliser le type de pince ci-dessous pour programmer, dans ce cas il n’est pas utile de souder le connecteur.

- Important : Il est impératif de débrancher l’alimentation de la carte durant la phase de programmation, la carte est alimentée par le programmateur.

Pour programmer toutes les cartes basées sur l’ATtiny84, il est conseillé d’utiliser le gestionnaire de cartes avec le modèle « Attiny Microcontollers ».


Si vous n’avez pas ce modèle de carte, ajoutez la ligne ci-dessous dans les « Préférences » de l’IDE puis redémarrez le.
https://raw.githubusercontent.com/damellis/attiny/ide-1.6.x-boards-manager/package_damellis_attiny_index.json (https://raw.githubusercontent.com/damellis/attiny/ide-1.6.x-boards-manager/package_damellis_attiny_index.json)

## 5.4.1 Debug

Les cartes à base d’ATtiny84 sont toutes équipées d’un connecteur (souvent H1), il permet de brancher provisoirement une LED (avec résistance 330 ohm) qui peut donner quelques informations sur le bon fonctionnement du firmware.

Exemple ci-contre de ce que j’utilise, protégé par une gaine thermo.

## 5.4.2 Programmer le module MLE21

L’ATtiny84 est prévu pour fonctionner avec son oscillateur interne à 8MHz ; après avoir connecté le programmateur et ouvert le projet « lora2ha-MLE21-Portail », sélectionnez le type de carte et le processeur ATtiny84 ; réglez la « Clock » sur « internal / 8MHz » puis gravez la séquence d’initialisation, après avoir vérifié que vous avez sélectionné le bon programmateur, généralement « Arduino as ISP ».

Ensuite il faut « Téléverser avec un programmateur ».

Pour les capteurs Binaires (contact), ne montez pas la résistance RJn (« n » est le connecteur utilisé par le contact).

Lors de mesure Analogique, adaptez la résistance RJn au pont diviseur que vous souhaitez (« n » est le connecteur utilisé par le capteur).

## 5.4.3 Programmer le module MLA30

L’ATtiny84 est prévu pour fonctionner avec son oscillateur interne à 1MHz afin d’économiser l’énergie de la batterie ; après avoir connecté le programmeur et ouvert le projet « lora2ha-MLA30 », sélectionnez le type de carte et le processeur ATtiny84 ; réglez la « Clock » sur « internal / 1MHz » puis gravez la séquence d’initialisation, après avoir vérifié que vous avez sélectionné le bon programmateur, généralement « Arduino as ISP ».

Ensuite il faut « Téléverser avec un programmateur ».

Utilisez les différents #define afin de configurer les types de capteurs que vous souhaitez connecter, par exemple, dé-commenter WITH_BINARY2 si vous avez un contact sec sur IO2. Si ce même contact doit « réveiller » le module, dé-commenter aussi WAKEUP_ON_IO2

Pour le « réveil » par contact (ex : WAKE_ON_IO2) , celui-ci s’effectue sur les deux fronts, descendant et montant ; il y aura donc deux transmissions.

Pour les capteurs Binaires (contact), ne montez pas la résistance RJn (« n » est le connecteur utilisé par le contact).

Lors de mesure Analogique, adaptez la résistance RJn au pont diviseur que vous souhaitez (« n » est le connecteur utilisé par le capteur).

## 5.5 Programmer les modules ATtiny3232 (MLD03)

Pour programmer les cartes équipées d’ATtiny3232, il vous faut un programmeur ISP ; il peut être fait en utilisant un simple Arduino UNO (ou Nano).

Il faut utiliser « MegaTinyCore » pour programme les ATtiny3232 (ou 3216), se référer au gitub du projet qui présente une documentation complète pour la programmation : https://github.com/SpenceKonde/megaTinyCore

Les cartes sont équipées d’un connecteur ICSP, il est possible d’utiliser le type de pince identique au ATtiny84 pour programmer, dans ce cas il n’est pas utile de souder le connecteur.

- Important : Il est impératif de débrancher l’alimentation de la carte durant la phase de programmation, la carte est alimentée par le programmateur.

# 6 ANNEXE A : Nomenclatures

A noter que toutes les dimensions nécessaires à la fabrication des boîtiers sont sérigraphiées au dos des cartes.

## 6.1 MLH1

U1 | ESP32-S2 Mini
U2 | RA-01 ou RA-02

Taille : 58.4 x 40.6 mm

## 6.2 MLH2

U1 | Olimex-POE-ISO
U2 | RA-01 ou RA-02
H1 | Connecteur Dupont femelle | optionnel
H2 | Connecteur Dupont | optionnel

Taille : 58.4 x 58.4 mm

## 6.3 MLH3

U1 | WT32-ETH01
U2 | RA-01 ou RA-02
BOOT | Connecteur Dupont mâle | Jumper lors de la programmation
PROG | Connecteur Dupont | optionnel
ALIM USB C | Carte USB C / Connecteur Dupont | optionnel


Taille : 61 x 61 mm

## 6.4 MLH4

U1 | ESP32-D1 Mini
U2 | RA-01 ou RA-02
H1 | Connecteur Dupont femelle | optionnel
H2 | Connecteur Dupont | optionnel

Taille : 40.6 x 63.6 mm

## 6.5 MLD01

U1 | Arduino Pro Micro | 5v
U2 | RA-01 ou RA-02 | Au dos de la carte
U3 | LTV-814
Q1 | BS170 | Ou 2N7000, IRFZ44, etc
Q2 | L78L33
R1 | 4.7K
R2, R3 | 10K
I1, I2 | Dupont mâle coudé ou bornier à visser | Pas 5.08

Taille : 27.94 x 50.8 mm

## 6.6 MLD03 (Piscine)

U1 | ATTiny3232 | 5v
U2 | RA-02
U3 | AMS1117-3.3 | 3.3v
K1, K2 | HF41F/5-ZS | 5v
Q1, Q2 | BS170 | Ou 2N7000, IRFZ44, etc
D1, D2 | 1N4448
R1, R4 | 220 | R0805
R2, R3 | 22K | R0805
R5 | 47K | R0805
C1 | 470µF | polarisé
C2, C3 | 100nF | C0805
J1, J2, J3 | KF128L-3.81 2P | Pas 3.81
J4 | KF128L-3.81 3P | Pas 3.81
230, PUMP, VALVE | KF301-5.0 2P | Pas 5.0
LED0,1,2 | WS2812D-F5
RTC | DS3231 Rasp Pi | Monté en gigogne sur connecteur 2.54 mâle.
Alim 230 | Module 230/5v 700mA


## 6.7 MLE21

U1 | ATtiny84
U2 | RA-01 ou RA-02
D1 | 1N4448 | Ou équivalent
Q1 | BS170 | Ou 2N7000, IRFZ44, etc
Q2 | L78L33
R1 | 220
R2 | 22K
RJ3 | 4.7K si DS18B20, ou valeur adaptée si pont | optionnel
RJ2 | valeur adaptée si pont | optionnel
K1 | HFD4 / 5v
REG1 | R-78E5.0-1.0 | Optionnel si Alim 5V
J1,2,3,4 | Bornier à visser | Pas 5.08
H1 | Connecteur Dupont femelle | Optionnel
ICSP | Connecteur Dupont femelle (ou pince) | Optionnel


Taille : 66.2 x 48.26 mm

## 6.8 MLA30 (v1.1)

U1 | ATtiny84 | 5v
U2 | RA-01 ou RA-02 | Au dos de la carte
U3 | TPS79433DCQ
C1 | 1µF | optionnel si pas de parasite
C2 | 2.2µF | optionnel si pas de parasite
C3 | 0.01µF (10nF)
RJ1 | 4.7K si DS18B20, ou valeur adaptée si pont | optionnel
RJ2, 3 | valeur adaptée si pont | optionnel
BAT | JST XH | Pas 2.54
PV | JST XH (ou connecteur à visser*) | Pas 2.54 (ou 5.08)
J1,2,3 | Bornier à visser | Pas 5.08
J4 | CRLD20MA 3.3V
H1 | Connecteur Dupont femelle | optionnel
ICSP | Connecteur Dupont femelle (ou pince) | optionnel
* Le connecteur PV peut être un JST XH ou à visser 2.54, ou 5.08 en utilisant la pastille « ! »


Taille : 58.4 x 45.7 mm

## 6.9 MLA10-1 (projet futur)

Projet de télécommande 1 bouton (ou contact sec)

Le point bloquant est l’antenne PCB : bonne forme et longueur

U1 | ATtiny84-SSFR | SMD
U2 | SX1278S2 | SMD
Q1 | BS170 | Ou 2N7000, IRFZ44, etc
R1 | 220 | R0805
RJ2 | 10K | R0805
KEY1 | K2-3.6x6.1 | SMD (ou contact externe)
H1 | Socle pile CR2450 KLS5
ICSP | Connecteur Dupont femelle (ou pince) | optionnel

Taille : 33 x 35mm
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

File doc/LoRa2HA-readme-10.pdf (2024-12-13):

# LoRa2HA

Documentation version 1.0

# Introduction

LoRa2HA est un ensemble d’équipements permettant une interconnexion entre des capteurs/actionneurs éloignés et un serveur Home Assistant (via MQTT), par radio en utilisant des modules LoRa®
; la portée peut
aller jusqu’à plus de 500m selon la qualité des antennes.

Le HUB (basé sur ESP32), reçoit les données radio et les envoi à Home Assistant (H.A) au travers d’un serveur MQTT.
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

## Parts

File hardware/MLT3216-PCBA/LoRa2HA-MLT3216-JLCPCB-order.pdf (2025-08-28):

# LoRa2HA

## MLT3216 : Commande chez JLCPCB

Les 3 fichiers à utiliser pour la fabrication de la carte MLT3216 sont :
- Gerber_MLT3216_PCB_V1.1.zip
- BOM_MLT3216_V1.1.csv
- PickAndPlace_PCB_MLT3216-V1.1.csv

Attention, le fichier Gerber contient la carte seule, pour une fabrication par JLCPCB, la taille minimale est de 70x70mm, il faudra donc demander une « panelisation » par JLCPCB, 3 row, 4 line minimum, soit 12 cartes par plaque.

Procédure sur le site JLCPCB :
- le fichier Gerber est à télécharger en premier
- choisir la quantité de « plaque » à fabriquer (avec une panulisation de 3x4, et une quantité de 5, le résultat final donnera 60 cartes).
- dans "delivery format", choisir "panel by JLCPCB" mettre 3 colonne et 4 lignes

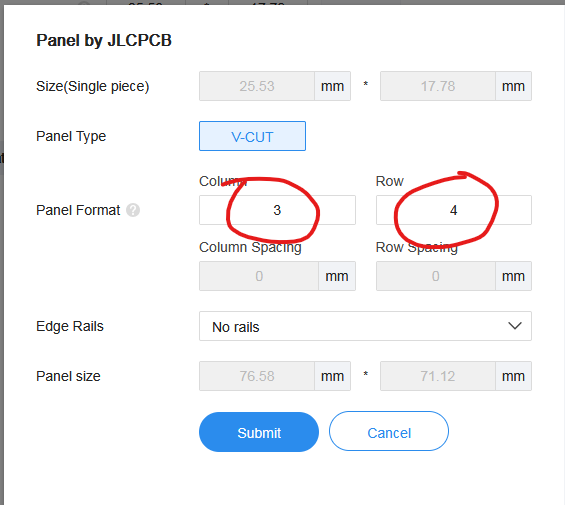
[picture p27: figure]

- choisir la couleur NOIR (couleur distinctive de la MLT3216),
- dans "Mark on PCB", choisir "Remove Mark"
- dans "PCB Remark, mettre le texte suivant : GME layer has a V-cut line need to be made
- activer la fabrication de la carte

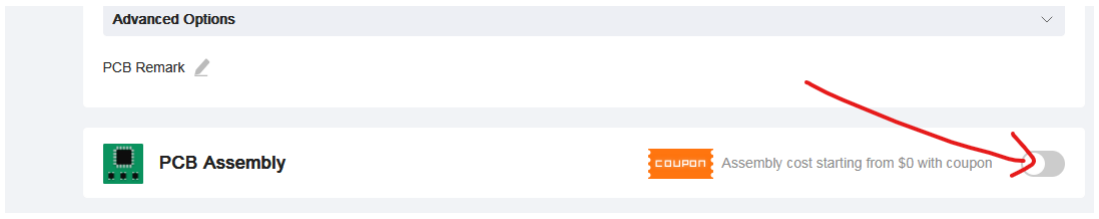
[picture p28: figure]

- choisir le type de PCB "Standard" (Economic ne passe pas avec les type de composant que l'on a et la découpe finale)
- dans "Edge Rails/Fiducial", choisir "Added by customer'
- cliquer sur le bouton "Next" à droite, pour passer à la configuration de fabrication
- la première est le choix de la face ou les composants sont soudés, laisser TOP, cliquer sur "Next"
- la suivante est l'ajout des fichier BOM et CPL (Nomenclature et Placement de composants)
- cliquer sur "Process BOM & CPL", il peut y avoir un message d'erreur pour des composants non montés, faire "Continue"
- il apparait un récapitulatif des composants qui seront montés, faire "Next"

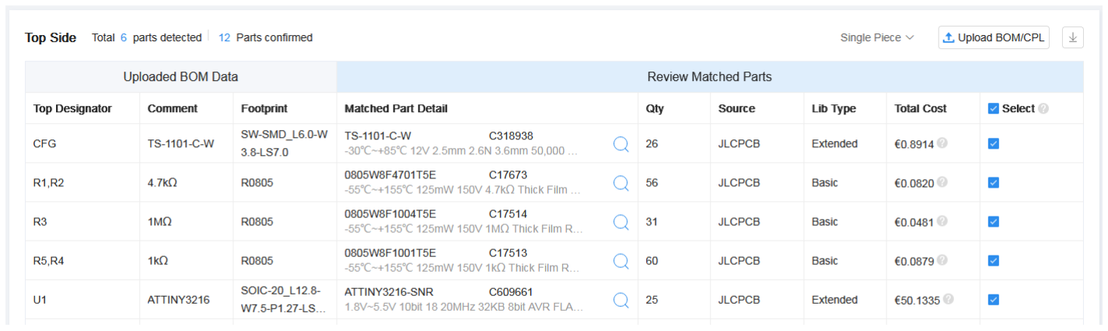
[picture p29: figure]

- en suite il y a la vérification des placements de composants, cliquer sur Next
- et enfin on arrive à la finalisation de commande…

Il se peut que tous les composants ne soient pas disponible pour le montage, dans ce cas vous avez 2 possibilités :
- passer la commander plus tard quand les stock seront rechargés
- effectuer une pré-commande, puis finaliser la commander ultérieurement (cette procédure est plus complexe).

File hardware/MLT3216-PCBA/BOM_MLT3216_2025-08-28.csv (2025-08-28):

ID | Name | Designator | Footprint | Quantity | Manufacturer Part | Manufacturer | Supplier | Supplier Part
1 | 1MΩ | R3 | R0805 | 1 |  | UNI-ROYAL(厚声) | LCSC | C17514
2 | TS-1101-C-W | CFG | SW-SMD_L6.0-W3.8-LS7.0 | 1 |  | XKB Connectivity(中国星坤) | LCSC | C318938
3 | ATTINY3216 | U1 | SOIC-20_L12.8-W7.5-P1.27-LS10.3-BL | 1 |  | MICROCHIP(美国微芯) | LCSC | C609661
4 | 4.7kΩ | R1,R2 | R0805 | 2 |  | UNI-ROYAL(厚声) | LCSC | C17673
5 | 1kΩ | R4 | R0805 | 1 |  | UNI-ROYAL(厚声) | LCSC | C17513

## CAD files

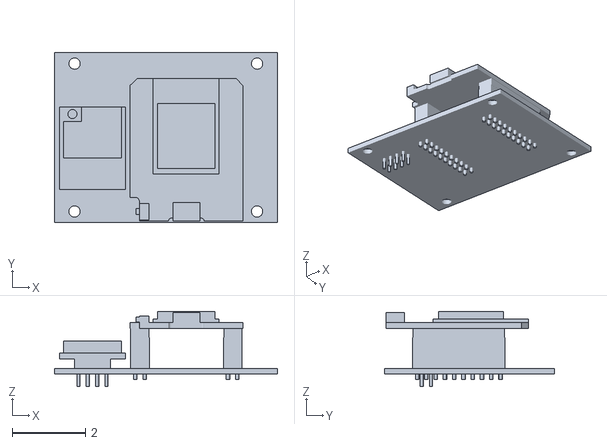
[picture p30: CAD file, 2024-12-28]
3D/MLH4 v2.0.obj
6.11 x 4.65 x 2.06

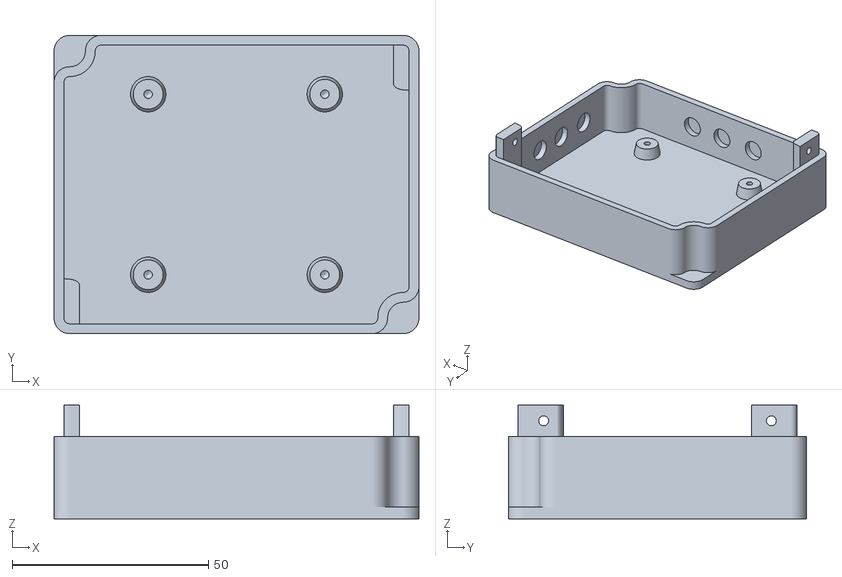
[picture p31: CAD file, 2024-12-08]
enclosure/MLE31-bottom.stl
93.0 x 76.0 x 29.0

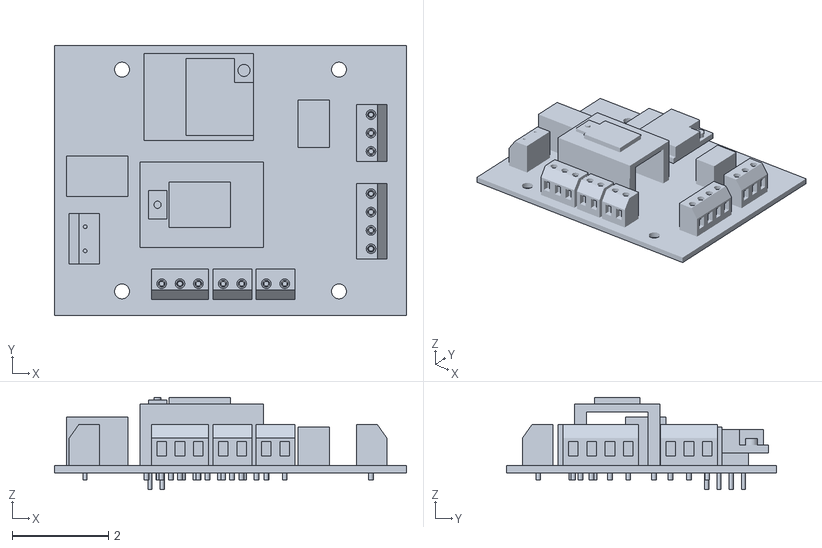
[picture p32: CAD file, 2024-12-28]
3D/MLE31 v1.0.obj
7.30 x 5.60 x 1.91

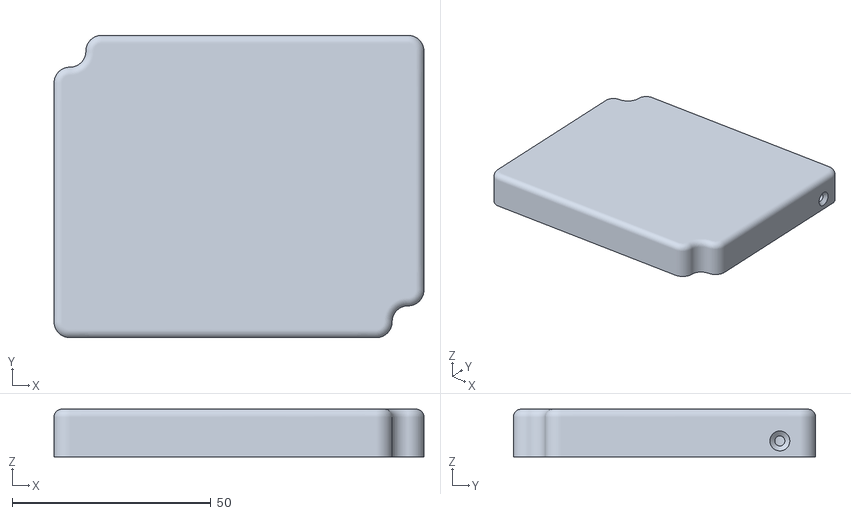
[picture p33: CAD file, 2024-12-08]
enclosure/MLE31-top.stl
93.0 x 76.0 x 12.0

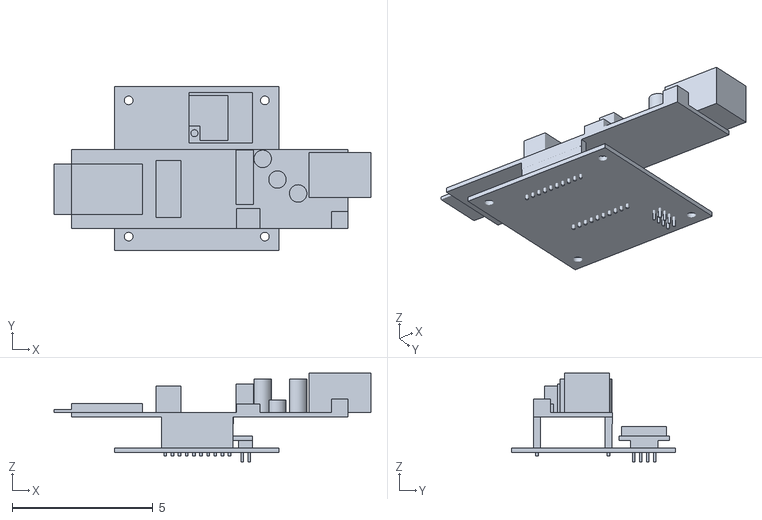
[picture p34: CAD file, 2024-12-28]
3D/MLH2 v2.0.obj
11.3 x 5.84 x 3.15

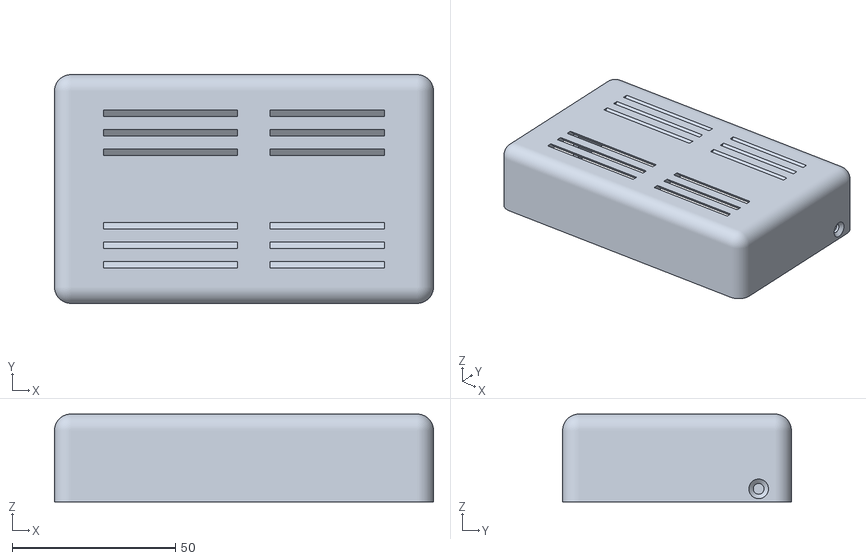
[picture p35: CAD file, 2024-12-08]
enclosure/MLH2-top.stl
116.0 x 70.0 x 26.9

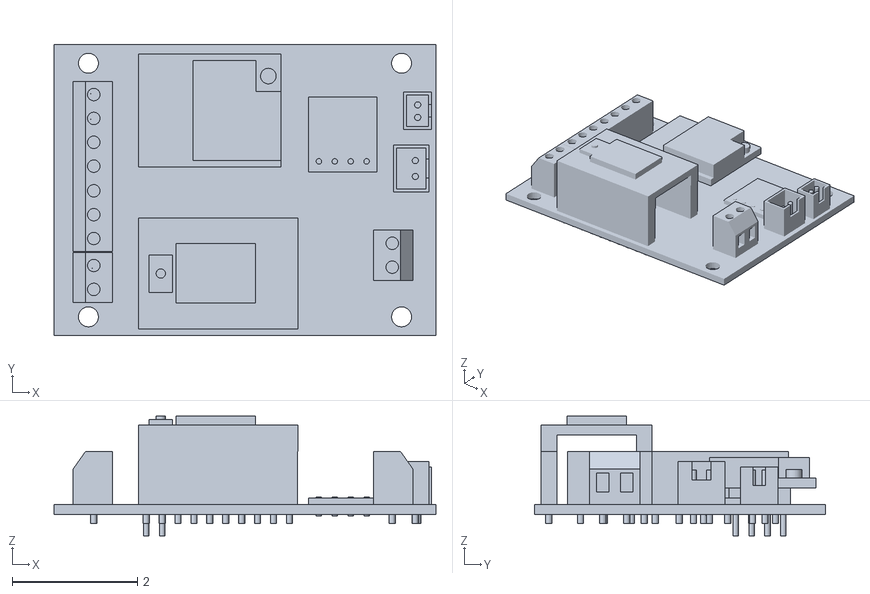
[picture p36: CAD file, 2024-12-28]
3D/MLA30 v2.1.obj
6.10 x 4.65 x 1.91

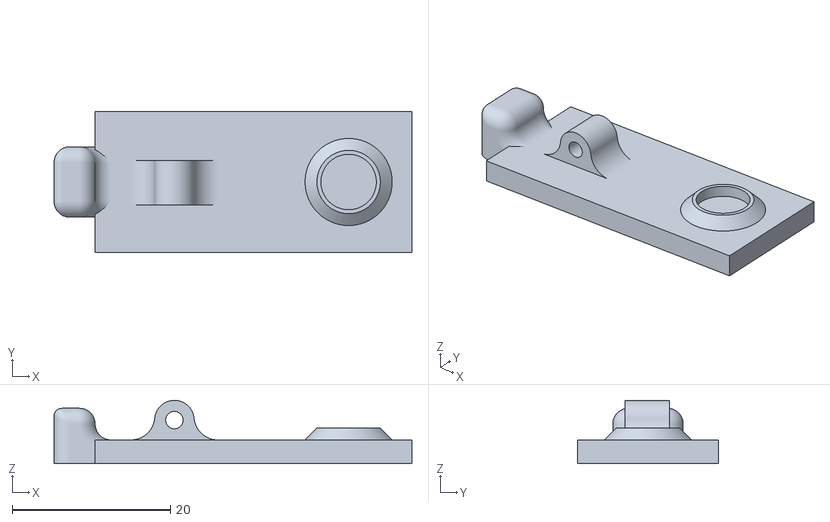
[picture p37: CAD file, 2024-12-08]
enclosure/UPDI-bottom.stl
45.2 x 17.8 x 8.00

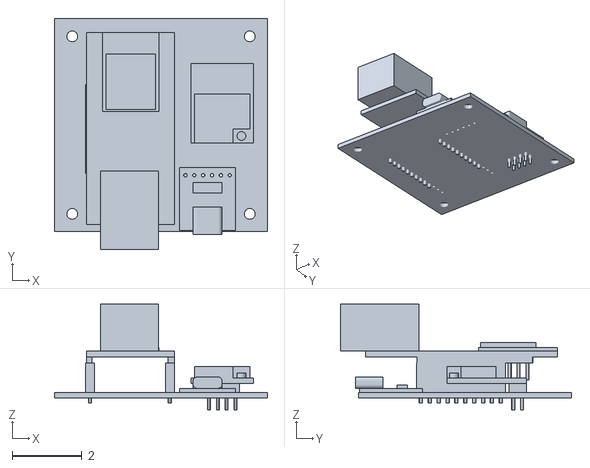
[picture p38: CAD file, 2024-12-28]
3D/MLH3 v2.0.obj
6.10 x 6.61 x 3.03

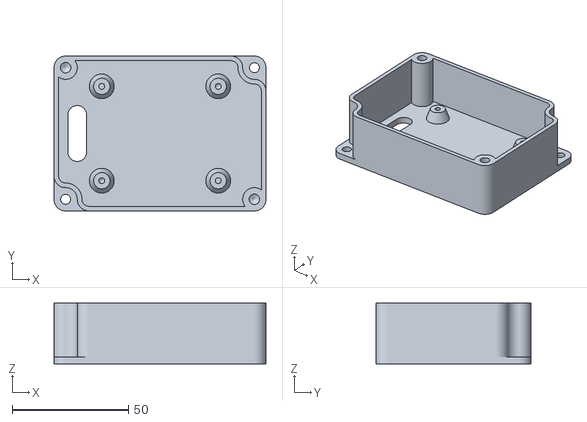
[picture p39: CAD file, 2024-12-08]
enclosure/MLA30-bottom.stl
91.0 x 66.5 x 26.0

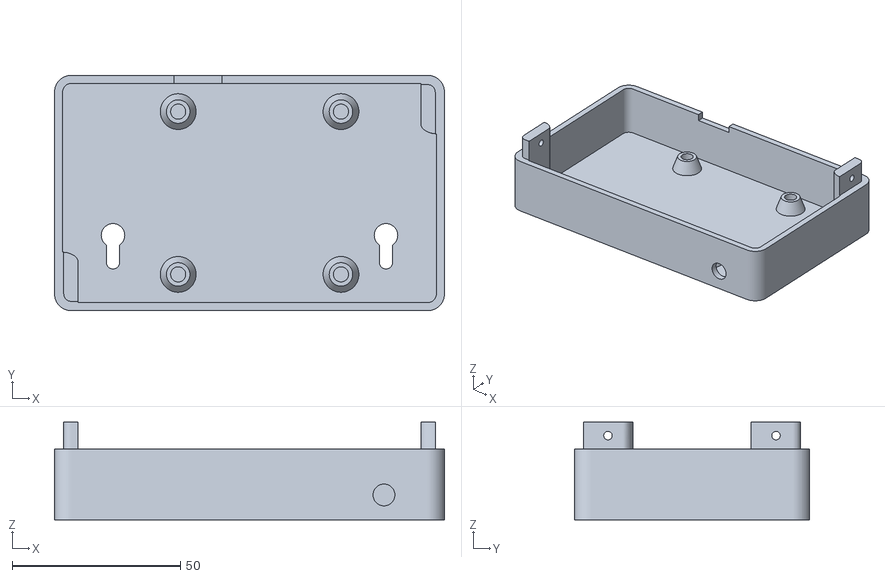
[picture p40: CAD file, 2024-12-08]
enclosure/MLH2-bottom.stl
116.0 x 70.0 x 29.0

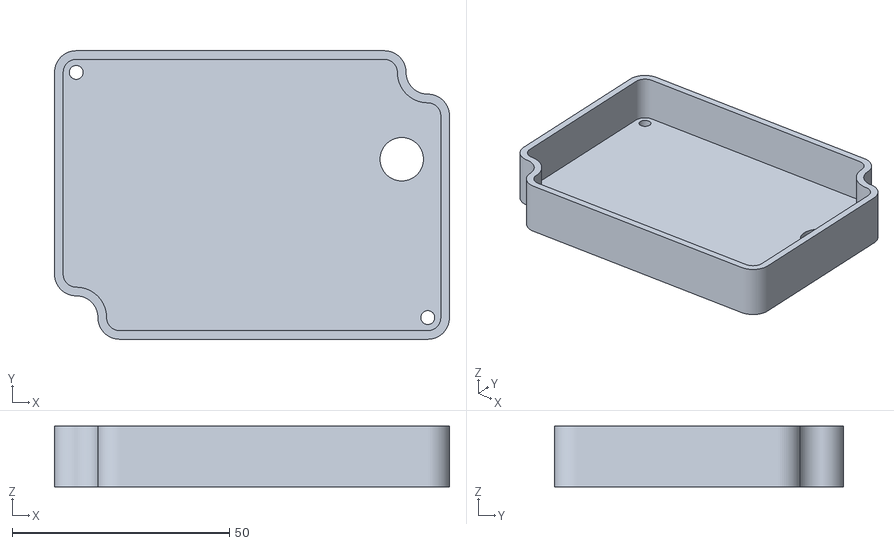
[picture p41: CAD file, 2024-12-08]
enclosure/MLA30-middle.stl
91.0 x 66.5 x 14.0

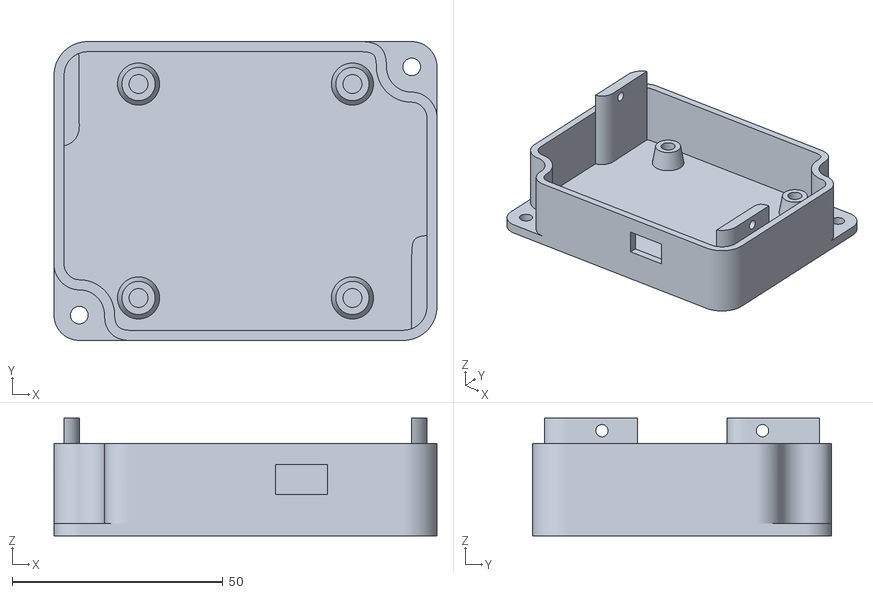
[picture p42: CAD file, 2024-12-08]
enclosure/MLH3-bottom.stl
91.0 x 71.0 x 28.0

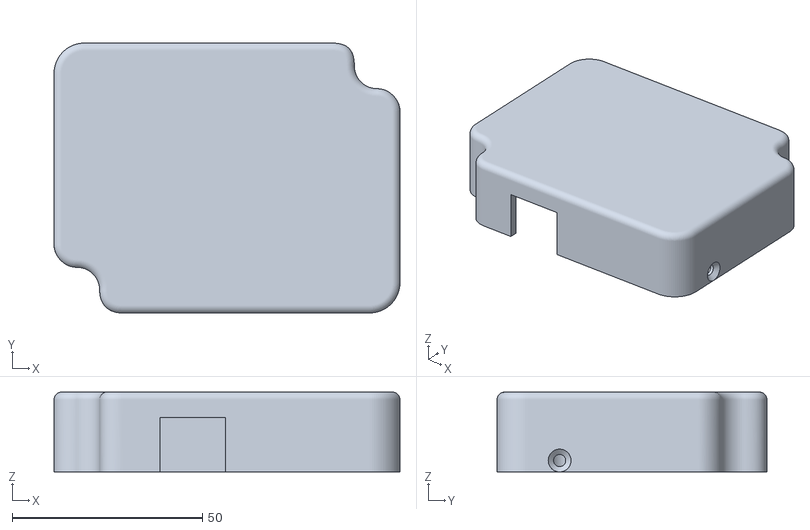
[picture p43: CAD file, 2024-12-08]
enclosure/MLH3-top.stl
91.0 x 71.0 x 21.0

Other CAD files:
enclosure/MLA30-top.stl
enclosure/UPDI-top.stl

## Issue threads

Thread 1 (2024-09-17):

erreur compilation

mickaelr3003, 2024-09-17:
bonjour j'ai ces erreurs quand je compile le programme MDL01
`C:\Users\Mickael\Desktop\LoRa2HA-main\lora2ha-MLD01-Linky-ProMicro\lora2ha-MLD01-Linky-ProMicro.ino: In function 'void loop()':
C:\Users\Mickael\Desktop\LoRa2HA-main\lora2ha-MLD01-Linky-ProMicro\lora2ha-MLD01-Linky-ProMicro.ino:205:9: error: 'rl_config_t' was not declared in this scope
         rl_config_t cnf;
         ^~~~~~~~~~~
C:\Users\Mickael\Desktop\LoRa2HA-main\lora2ha-MLD01-Linky-ProMicro\lora2ha-MLD01-Linky-ProMicro.ino:205:9: note: suggested alternative: 'rl_configs_t'
         rl_config_t cnf;
         ^~~~~~~~~~~
         rl_configs_t
C:\Users\Mickael\Desktop\LoRa2HA-main\lora2ha-MLD01-Linky-ProMicro\lora2ha-MLD01-Linky-ProMicro.ino:206:17: error: 'cnf' was not declared in this scope
         memset(&cnf, 0, sizeof(cnf));
                 ^~~
C:\Users\Mickael\Desktop\LoRa2HA-main\lora2ha-MLD01-Linky-ProMicro\lora2ha-MLD01-Linky-ProMicro.ino:206:17: note: suggested alternative: 'scanf'
         memset(&cnf, 0, sizeof(cnf));
                 ^~~
                 scanf
C:\Users\Mickael\Desktop\LoRa2HA-main\lora2ha-MLD01-Linky-ProMicro\lora2ha-MLD01-Linky-ProMicro.ino:209:35: error: 'S_TEXTSENSOR' was not declared in this scope
         cnf.deviceType = (uint8_t)S_TEXTSENSOR;
                                   ^~~~~~~~~~~~
C:\Users\Mickael\Desktop\LoRa2HA-main\lora2ha-MLD01-Linky-ProMicro\lora2ha-MLD01-Linky-ProMicro.ino:209:35: note: suggested alternative: 'E_TEXTSENSOR'
         cnf.deviceType = (uint8_t)S_TEXTSENSOR;
                                   ^~~~~~~~~~~~
                                   E_TEXTSENSOR
C:\Users\Mickael\Desktop\LoRa2HA-main\lora2ha-MLD01-Linky-ProMicro\lora2ha-MLD01-Linky-ProMicro.ino:210:33: error: 'V_TEXT' was not declared in this scope
         cnf.dataType = (uint8_t)V_TEXT;
                                 ^~~~~~
C:\Users\Mickael\Desktop\LoRa2HA-main\lora2ha-MLD01-Linky-ProMicro\lora2ha-MLD01-Linky-ProMicro.ino:210:33: note: suggested alternative: 'D_TEXT'
         cnf.dataType = (uint8_t)V_TEXT;
                                 ^~~~~~
                                 D_TEXT
C:\Users\Mickael\Desktop\LoRa2HA-main\lora2ha-MLD01-Linky-ProMicro\lora2ha-MLD01-Linky-ProMicro.ino:213:35: error: 'S_NUMERICSENSOR' was not declared in this scope
         cnf.deviceType = (uint8_t)S_NUMERICSENSOR;
                                   ^~~~~~~~~~~~~~~
C:\Users\Mickael\Desktop\LoRa2HA-main\lora2ha-MLD01-Linky-ProMicro\lora2ha-MLD01-Linky-ProMicro.ino:213:35: note: suggested alternative: 'E_NUMERICSENSOR'
         cnf.deviceType = (uint8_t)S_NUMERICSENSOR;
                                   ^~~~~~~~~~~~~~~
                                   E_NUMERICSENSOR
C:\Users\Mickael\Desktop\LoRa2HA-main\lora2ha-MLD01-Linky-ProMicro\lora2ha-MLD01-Linky-ProMicro.ino:214:33: error: 'V_NUM' was not declared in this scope
         cnf.dataType = (uint8_t)V_NUM;
                                 ^~~~~
C:\Users\Mickael\Desktop\LoRa2HA-main\lora2ha-MLD01-Linky-ProMicro\lora2ha-MLD01-Linky-ProMicro.ino:214:33: note: suggested alternative: 'D_NUM'
         cnf.dataType = (uint8_t)V_NUM;
                                 ^~~~~
                                 D_NUM
Plusieurs bibliothèque trouvées pour "SPI.h"
  Utilisé: C:\Users\Mickael\AppData\Local\Arduino15\packages\arduino\hardware\avr\1.8.6\libraries\SPI
  Non utilisé: C:\Users\Mickael\Documents\Arduino\libraries\SPI
exit status 1

Compilation error: 'rl_config_t' was not declared in this scope`

PM04290, 2024-09-18:
@mickaelr3003 essai de compiler avec un Arduino Leonardo.

mickaelr3003, 2024-09-18:
Non comme la carte est montée avec un Arduino pro micro, j'ai compilé avec celle-ci.

PM04290, 2024-10-03:
@mickaelr3003 alors, avec la compilation Arduino Leonardo, ça donne quoi ?

mickaelr3003, 2024-10-03:
Désolé je n'avais pas le temps.
je viens de compiler avec arduino leonardo et j'ai ceci 👍
`C:\Users\Mickael\Desktop\LoRa2HA-main\lora2ha-MLD01-Linky-ProMicro\lora2ha-MLD01-Linky-ProMicro.ino: In function 'void loop()':
C:\Users\Mickael\Desktop\LoRa2HA-main\lora2ha-MLD01-Linky-ProMicro\lora2ha-MLD01-Linky-ProMicro.ino:205:9: error: 'rl_config_t' was not declared in this scope
         rl_config_t cnf;
         ^~~~~~~~~~~
C:\Users\Mickael\Desktop\LoRa2HA-main\lora2ha-MLD01-Linky-ProMicro\lora2ha-MLD01-Linky-ProMicro.ino:205:9: note: suggested alternative: 'rl_configs_t'
         rl_config_t cnf;
         ^~~~~~~~~~~
         rl_configs_t
C:\Users\Mickael\Desktop\LoRa2HA-main\lora2ha-MLD01-Linky-ProMicro\lora2ha-MLD01-Linky-ProMicro.ino:206:17: error: 'cnf' was not declared in this scope
         memset(&cnf, 0, sizeof(cnf));
                 ^~~
C:\Users\Mickael\Desktop\LoRa2HA-main\lora2ha-MLD01-Linky-ProMicro\lora2ha-MLD01-Linky-ProMicro.ino:206:17: note: suggested alternative: 'scanf'
         memset(&cnf, 0, sizeof(cnf));
                 ^~~
                 scanf
C:\Users\Mickael\Desktop\LoRa2HA-main\lora2ha-MLD01-Linky-ProMicro\lora2ha-MLD01-Linky-ProMicro.ino:209:35: error: 'S_TEXTSENSOR' was not declared in this scope
         cnf.deviceType = (uint8_t)S_TEXTSENSOR;
                                   ^~~~~~~~~~~~
C:\Users\Mickael\Desktop\LoRa2HA-main\lora2ha-MLD01-Linky-ProMicro\lora2ha-MLD01-Linky-ProMicro.ino:209:35: note: suggested alternative: 'E_TEXTSENSOR'
         cnf.deviceType = (uint8_t)S_TEXTSENSOR;
                                   ^~~~~~~~~~~~
                                   E_TEXTSENSOR
C:\Users\Mickael\Desktop\LoRa2HA-main\lora2ha-MLD01-Linky-ProMicro\lora2ha-MLD01-Linky-ProMicro.ino:210:33: error: 'V_TEXT' was not declared in this scope
         cnf.dataType = (uint8_t)V_TEXT;
                                 ^~~~~~
C:\Users\Mickael\Desktop\LoRa2HA-main\lora2ha-MLD01-Linky-ProMicro\lora2ha-MLD01-Linky-ProMicro.ino:210:33: note: suggested alternative: 'D_TEXT'
         cnf.dataType = (uint8_t)V_TEXT;
                                 ^~~~~~
                                 D_TEXT
C:\Users\Mickael\Desktop\LoRa2HA-main\lora2ha-MLD01-Linky-ProMicro\lora2ha-MLD01-Linky-ProMicro.ino:213:35: error: 'S_NUMERICSENSOR' was not declared in this scope
         cnf.deviceType = (uint8_t)S_NUMERICSENSOR;
                                   ^~~~~~~~~~~~~~~
C:\Users\Mickael\Desktop\LoRa2HA-main\lora2ha-MLD01-Linky-ProMicro\lora2ha-MLD01-Linky-ProMicro.ino:213:35: note: suggested alternative: 'E_NUMERICSENSOR'
         cnf.deviceType = (uint8_t)S_NUMERICSENSOR;
                                   ^~~~~~~~~~~~~~~
                                   E_NUMERICSENSOR
C:\Users\Mickael\Desktop\LoRa2HA-main\lora2ha-MLD01-Linky-ProMicro\lora2ha-MLD01-Linky-ProMicro.ino:214:33: error: 'V_NUM' was not declared in this scope
         cnf.dataType = (uint8_t)V_NUM;
                                 ^~~~~
C:\Users\Mickael\Desktop\LoRa2HA-main\lora2ha-MLD01-Linky-ProMicro\lora2ha-MLD01-Linky-ProMicro.ino:214:33: note: suggested alternative: 'D_NUM'
         cnf.dataType = (uint8_t)V_NUM;
                                 ^~~~~
                                 D_NUM
Plusieurs bibliothèque trouvées pour "SPI.h"
  Utilisé: C:\Users\Mickael\AppData\Local\Arduino15\packages\arduino\hardware\avr\1.8.6\libraries\SPI
  Non utilisé: C:\Users\Mickael\Documents\Arduino\libraries\SPI
exit status 1

Compilation error: 'rl_config_t' was not declared in this scope`

PM04290, 2024-10-04:
La libraire RadioLink n'est pas à jour; il y a longtemps que tu l'as téléchargée ?

mickaelr3003, 2024-10-05:
je viens de la retelecharger sur : https://github.com/PM04290/RadioLink mais toujours le même problème

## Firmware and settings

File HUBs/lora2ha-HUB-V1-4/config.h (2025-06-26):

#pragma once

#define VERSION "1.4"

#if defined(ARDUINO_LOLIN_S2_MINI)
#define PIN_WMODE 13 // MLH1
//#define UPDI_TX   
//#define UPDI_RX   
#elif defined(ARDUINO_ESP32_POE_ISO) || defined(ARDUINO_ESP32_POE)
#define PIN_WMODE 32 // MLH2
#define UPDI_TX   13
#define UPDI_RX   16
#elif defined(ARDUINO_WT32_ETH01)
#define PIN_WMODE 32 // MLH3
#define UPDI_TX   17
#define UPDI_RX    5
#elif defined(ARDUINO_D1_MINI32)
#define PIN_WMODE 32 // MLH4
#define UPDI_TX   21
#define UPDI_RX   22
#elif defined(ARDUINO_TTGO_LoRa32_v21new)
#define PIN_WMODE  4 // MLH5
#define UPDI_TX   12
#define UPDI_RX   34
#else
#define PIN_WMODE 32 // custon ESP32 WROOM
#define UPDI_TX   21
#define UPDI_RX   22
#endif

// automatic use ETHERNET with Olimex POE and WT32-ETH01
#if defined(ARDUINO_WT32_ETH01) || defined(ARDUINO_ESP32_POE_ISO) || defined(ARDUINO_ESP32_POE)
#define USE_ETHERNET
//#define FORCE_ETHERNET // uncomment this if you want to force Ethernet every time
#endif

// this define permit switch from WiFi to Ehternet (need define USE_ETHERNET)
#if defined(ARDUINO_WT32_ETH01)
#define PIN_ETH_LINK 33
#endif

#define DEFAULT_ONLINE_WATCHDOG 10 // in min
#define DEFAULT_RETRY_NTP 10

#define EEPROM_MAX_SIZE    512

#define EEPROM_DATA_CODE     0
#define EEPROM_DATA_FREQ     1
#define EEPROM_DATA_RANGE    3
#define EEPROM_DATA_NVPN     4
#define EEPROM_DATA_WDOG    14

#define EEPROM_TEXT_OFFSET  16
#define EEPROM_TEXT_SIZE    48

char Wifi_ssid[EEPROM_TEXT_SIZE] = "";  // WiFi SSID
char Wifi_pass[EEPROM_TEXT_SIZE] = "";  // WiFi password

char mqtt_host[EEPROM_TEXT_SIZE] = "192.168.0.100";
uint16_t mqtt_port = 1883;
char mqtt_user[EEPROM_TEXT_SIZE] = "";  // MQTT user
char mqtt_pass[EEPROM_TEXT_SIZE] = "";  // MQTT password

char datetimeTZ[EEPROM_TEXT_SIZE] = "CET-1CEST,M3.5.0,M10.5.0/3";
char datetimeNTP[EEPROM_TEXT_SIZE] = "europe.pool.ntp.org";
char defaultNTP[EEPROM_TEXT_SIZE] = "pool.ntp.org";

char AP_ssid[9] = "lora2ha0";  // AP WiFi SSID
char AP_pass[9] = "12345678";  // AP WiFi password

// WireGuard configuration --- UPDATE this configuration from JSON
char private_key[65] = "";      // [Interface] PrivateKey
IPAddress local_ip(1,2,3,4);    // [Interface] Address
char public_key[65] = "";       // [Peer] PublicKey
char endpoint_address[16] = ""; // [Peer] Endpoint
int endpoint_port = 48123;      // [Peer] Endpoint

char HAuniqueId[13];

uint8_t UIDcode = 0;
uint16_t RadioFreq = 433;
uint8_t RadioRange = 1;
uint8_t rstCount = 0;
uint8_t Watchdog = DEFAULT_ONLINE_WATCHDOG;

const char HAConfigRoot[]                PROGMEM = {"homeassistant"};
const char HAlora2ha[]                   PROGMEM = {"lora2ha"};

const char HAComponentBinarySensor[]     PROGMEM = {"binary_sensor"};
const char HAComponentSensor[]           PROGMEM = {"sensor"};
const char HAComponentNumber[]           PROGMEM = {"number"};
const char HAComponentSelect[]           PROGMEM = {"select"};
const char HAComponentSwitch[]           PROGMEM = {"switch"};
const char HAComponentTag[]              PROGMEM = {"tag"};
const char HAComponentDeviceAutomation[] PROGMEM = {"device_automation"};

const char HAIdentifiers[]       PROGMEM = {"ids"};
const char HAManufacturer[]      PROGMEM = {"mf"};
const char HAModel[]             PROGMEM = {"mdl"};
const char HASwVersion[]         PROGMEM = {"sw"};
const char HAViaDevice[]         PROGMEM = {"via_device"};
const char HAUniqueID[]          PROGMEM = {"unique_id"};
const char HAObjectID[]          PROGMEM = {"objt_id"};
const char HAName[]              PROGMEM = {"name"};
const char HATopic[]             PROGMEM = {"topic"};
const char HAPayload[]           PROGMEM = {"payload"};
const char HAState[]             PROGMEM = {"state"};
const char HAStateTopic[]        PROGMEM = {"stat_t"};
const char HAStateOpen[]         PROGMEM = {"stat_open"};
const char HAStateOpening[]      PROGMEM = {"stat_opening"};
const char HAStateClosed[]       PROGMEM = {"stat_closed"};
const char HAStateClosing[]      PROGMEM = {"stat_closing"};
const char HAStateStopped[]      PROGMEM = {"stat_stopped"};
const char HAPayloadOpen[]       PROGMEM = {"pl_open"};
const char HAPayloadStop[]       PROGMEM = {"pl_stop"};
const char HAPayloadClose[]      PROGMEM = {"pl_close"};
const char HACommand[]           PROGMEM = {"command"};
const char HACommandTopic[]      PROGMEM = {"cmd_t"};
const char HADeviceClass[]       PROGMEM = {"dev_cla"};
const char HAEntityCategory[]    PROGMEM = {"ent_cat"};
const char HAUnitOfMeasurement[] PROGMEM = {"unit_of_meas"};
const char HAStateNone[]         PROGMEM = {"none"};
const char HAStateOn[]           PROGMEM = {"ON"};
const char HAStateOff[]          PROGMEM = {"OFF"};
const char HAExpireAfter[]       PROGMEM = {"exp_aft"};
const char HAMin[]               PROGMEM = {"min"};
const char HAMax[]               PROGMEM = {"max"};
const char HAIcon[]              PROGMEM = {"icon"};

#define DEBUG_SERIAL

#ifdef DEBUG_SERIAL
#define DEBUG(x) Serial.print(x)
#define DEBUGln(x) Serial.println(x)
#define DEBUGf(...) Serial.printf(__VA_ARGS__)
#else
#define DEBUG(x)
#define DEBUGln(x)
#define DEBUGf(x,y)
#endif 

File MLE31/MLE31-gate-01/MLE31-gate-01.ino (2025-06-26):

/*
  Version : 2.0
  PCB : MLE31 V1.0

  PIN config ATTiny3216 (internal oscillator 4MHz)

  This firmware manage gate (by his dry contact)

  IN1 is N.O. dry contact for Ring button
  IN2 is N.O. dry contact to indicate Gate is Closed
  IN3 is N.O. dry contact to indicate Gate is Opened
  OUT1 is the relay switch (N.O.), for temporary pulse on gate dry contact
  It is possible to define the pulse length time (300ms by default).
*/
//                 ATtiny3216
//                   _____
//            VDD  1|*    |20 GND
// (nSS)  PA4  0~  2|     |19 16~ PA3 (SCK)
// (IN1)  PA5  1~  3|     |18 15  PA2 (MISO)
// (DIO0) PA6  2   4|     |17 14  PA1 (MOSI)
// (nRST) PA7  3   5|     |16 17  PA0 (UPDI)
// (IN3)  PB5  4   6|     |15 13  PC3 (IN4)
// (IN2)  PB4  5   7|     |14 12  PC2 (LEDs)
// (RXD)  PB3  6   8|     |13 11~ PC1 (OUT1)
// (TXD)  PB2  7~  9|     |12 10~ PC0 (OUT2)
// (SDA)  PB1  8~ 10|_____|11  9~ PB0 (SCL)

#include <Arduino.h>
#include <EEPROM.h>

//--- debug tools ---
#define DSerial Serial
#define DEBUG_LED
//#define DEBUG_SERIAL

#define ML_SX1278
#include <MLiotComm.h>
#include <MLiotElements.h>

// I/O pin
#define PIN_IN1       PIN_PA5
#define PIN_IN2       PIN_PB4
#define PIN_IN3       PIN_PB5
#define PIN_IN4       PIN_PC2
#define PIN_OUT1      PIN_PC1
#define PIN_OUT2      PIN_PC0
#define PIN_DEBUG_LED PIN_PC2

// EEPROM dictionnary
#define EEP_UID         0
#define EEP_HUBID       (EEP_UID+1)
#define EEP_INPUT_TEMPO (EEP_HUBID+1)

// LoRa
extern uint8_t hubid; // Hub ID
extern uint8_t uid;   // this module ID

const uint32_t LRfreq = 433;
const uint8_t LRrange = 1;
bool LoraOK = false;
bool needPairing = false;

#define CHILD_ID_IN1    1 // sensor on J1
#define CHILD_ID_IN2    2 // sensor on J2
#define CHILD_ID_IN3    3 // sensor on J3
#define CHILD_ID_IN4    4 // sensor on J4 (unused)
#define CHILD_ID_OUT1   5 // relay on OUT1
#define CHILD_ID_OUT2   6 // relay on OUT2 (unused)
#define CHILD_ID_TEMPO  7 // timer
#define CHILD_ID_BUTTON 8 // H.A. button

#ifdef DEBUG_LED
#include <tinyNeoPixel_Static.h>
#define NUMLEDS 3
byte pixels[NUMLEDS * 3];
tinyNeoPixel leds = tinyNeoPixel(NUMLEDS, PIN_DEBUG_LED, NEO_GRB, pixels);
#define LED_INIT {pinMode(PIN_DEBUG_LED, OUTPUT); leds.setBrightness(10);}
#define LED_RED(x) {leds.setPixelColor(0, leds.Color(x, 0, 0)); leds.show();}
#define LED_GREEN(x) {leds.setPixelColor(0, leds.Color(0, x, 0)); leds.show();}
#define LED_BLUE(x) {leds.setPixelColor(0, leds.Color(0, 0, x)); leds.show();}
#define LED_OFF {leds.setPixelColor(0, leds.Color(0, 0, 0)); leds.show();}
#else
#define LED_INIT
#define LED_RED(x)
#define LED_GREEN(x)
#define LED_BLUE(x)
#define LED_OFF
#endif

Input* Tempo;
Relay* RelayOut1;

uint32_t curTime;
uint32_t tempoRelay = 0;

void setup()
{
  LED_INIT;

  DEBUGinit();
  DEBUGln("\nStart");

  // RST pin from LoRa module is used to active "pairing"
  pinMode(RL_DEFAULT_RESET_PIN, INPUT);
  while (analogRead(RL_DEFAULT_RESET_PIN) < 100)
  {
    LED_BLUE(255); delay(millis() > 10000 ? 100 : 300);
    LED_OFF; delay(millis() > 10000 ? 100 : 300);
    needPairing = true;
  }
  if (millis() > 10000)
  { // CFG pressed more than 10s : factory setting
    uid = 0xFF;
  } else
  {
    uid = EEPROM.read(EEP_UID);
  }

  LED_GREEN(255);
  if (uid == 0xFF)
  { // blank EEPROM
    DEBUGln(F("Initialize EEPROM"));
    uid = 40;
    hubid = 0;

    // update
    EEPROM.put(EEP_UID, uid);
    EEPROM.put(EEP_HUBID, hubid);

    inputRecord ir;
    ir = {0, 2000, 300, 1};             // min:0 max:2000 sel:300 div:1
    EEPROM.put(EEP_INPUT_TEMPO, ir);

    needPairing = true;
  }
  EEPROM.get(EEP_HUBID, hubid);

  // Initialisation des Elements
  deviceManager.addElement(new Binary(PIN_IN1, CHILD_ID_IN1, F("Ring"), stateInverted, nullptr));
  deviceManager.addElement(new Binary(PIN_IN2, CHILD_ID_IN2, F("Closed"), stateInverted, nullptr));
  deviceManager.addElement(new Binary(PIN_IN3, CHILD_ID_IN3, F("Opened"), stateInverted, nullptr));

  RelayOut1 = (Relay*)deviceManager.addElement(new Relay(PIN_OUT1, CHILD_ID_OUT1, F("Command")));

  Tempo = (Input*)deviceManager.addElement(new Input(CHILD_ID_TEMPO, EEP_INPUT_TEMPO, F("Pulse time"), F("ms")));

  deviceManager.addElement(new Button(CHILD_ID_BUTTON, F("Open")));

  LoraOK = MLiotComm.begin(LRfreq * 1E6, onReceive, NULL, 14, LRrange);
  if (LoraOK)
  {
    if (needPairing)
    {
      // publish config
      uint8_t h = hubid;
      hubid = RL_ID_BROADCAST;
      deviceManager.publishConfigElements(F("Gate"), F("MLE31"));
      while (needPairing)
      {
        uint32_t tick = millis() / 3;
        LED_GREEN(abs((tick % 511) - 255));
      }
    }
  } else
  {
#ifdef DEBUG_LED
    // To show LoRa error on H1 LED
    for (byte b = 0; b < 3; b++)
    {
       LED_RED(255); delay(200); LED_OFF; delay(200);
    }
#endif
  }
  LED_OFF;

}

void loop()
{
  curTime = millis();
  // control timer of Relay
  if ((tempoRelay > 0) && (curTime > tempoRelay))
  {
    tempoRelay = 0;
    RelayOut1->setValue(false);
  }

  deviceManager.processElements();
  deviceManager.sendElements();
}

void onReceive(uint8_t len, rl_packet_t* pIn)
{
  // ***************************************
  // ! ! ! don't publish anything here ! ! !
  // ! ! ! and stay short time         ! ! !
  // ***************************************
  if (pIn->destinationID == uid)
  {
    if (needPairing && pIn->childID == RL_ID_CONFIG)
    {
      rl_conf_t cnfIdx = (rl_conf_t)(pIn->sensordataType & 0x07);
      if (cnfIdx == C_PARAM)
      {
        rl_configParam_t* pcnfp = (rl_configParam_t*)&pIn->data.configs;
        if (pcnfp->childID == 0)
        { // 0 to change UID device
          uid = pcnfp->pInt;
          EEPROM.put(EEP_UID, uid);
        }
        return;
      }
      if (cnfIdx == C_END)
      {
        hubid = pIn->senderID;
        EEPROM.put(EEP_HUBID, hubid);
        needPairing = false;
        return;
      }
    }
    if (pIn->senderID == hubid)
    {
      if (pIn->childID == CHILD_ID_OUT1)
      { // Open door
        bool activate = pIn->data.num.value > 0;
        RelayOut1->setValue(activate);
        tempoRelay = 0;
        int t = Tempo->getValue();
        // active auto OFF timeout
        if (activate && t)
        {
          tempoRelay = (millis() + t) | 1;
        }
        return;
      }
      if (pIn->childID == CHILD_ID_TEMPO)
      {
        Tempo->setValue(pIn->data.num.value / pIn->data.num.divider);
        return;
      }
      if (pIn->childID == CHILD_ID_BUTTON)
      {
        int t = Tempo->getValue();
        // active auto OFF timeout
        if (t)
        {
          RelayOut1->setValue(1);
          tempoRelay = (millis() + t) | 1;
        }
        return;
      }
    }
  }
}

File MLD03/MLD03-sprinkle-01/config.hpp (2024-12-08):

// ATtiny3216 / ARDUINO
//                          _____
//                  VDD   1|*    |20  GND
// (nSS)  (AIN4) PA4  0~  2|     |19  16~ PA3 (AIN3)(SCK)(EXTCLK)
//        (AIN5) PA5  1~  3|     |18  15  PA2 (AIN2)(MISO)
// (DAC)  (AIN6) PA6  2   4|     |17  14  PA1 (AIN1)(MOSI)
//        (AIN7) PA7  3   5|     |16  17  PA0 (AIN0/nRESET/UPDI)
//        (AIN8) PB5  4   6|     |15  13  PC3
//        (AIN9) PB4  5   7|     |14  12  PC2
// (RXD) (TOSC1) PB3  6   8|     |13  11~ PC1 (PWM only on 1-series)
// (TXD) (TOSC2) PB2  7~  9|     |12  10~ PC0 (PWM only on 1-series)
// (SDA) (AIN10) PB1  8~ 10|_____|11   9~ PB0 (AIN11)(SCL)
//

// I/O pin
#if defined(__AVR_ATtiny1616__) || defined(__AVR_ATtiny3216__)
#define PIN_I_1        2
#define PIN_I_2        3
#define PIN_I_3        4
#define PIN_I_4        5
#define PIN_R_2        10
#define PIN_R_1        11
#define PIN_LEDS       12
#else
#define PIN_I_1        A0
#define PIN_I_2        A1
#define PIN_I_3        A2
#define PIN_I_4        A3
#define PIN_R_1        5
#define PIN_R_2        4
#define PIN_LEDS       3
#endif

// RadioLink Ids (child 250..255 are reserved, 0 prohibited
#define HUB_UID            0 // HUB ID
#define MODULE_ID         22 // module ID
#define CHILD_SENSOR1      1 // sensor on JI1
#define CHILD_SENSOR2      2 // sensor on JI2
#define CHILD_SENSOR3      3 // sensor on JI3
#define CHILD_SENSOR4      4 // sensor on JI4
#define CHILD_RELAY1       5 // relay on JR1
#define CHILD_RELAY2       6 // relay on JR2
#define CHILD_INPUT_DAY1   7 // input day config for Z1
#define CHILD_INPUT_HOUR1  8 // input start hour for Z1
#define CHILD_INPUT_DUR1   9 // input duration for Z1
#define CHILD_INPUT_HUM1  10 // input Humidity for Z1
#define CHILD_INPUT_DAY2  11 // input day config for Z2
#define CHILD_INPUT_HOUR2 12 // input start hour for Z2
#define CHILD_INPUT_DUR2  13 // input duration for Z2
#define CHILD_INPUT_HUM2  14 // input Humidity for Z2
#define CHILD_SCHED1      15 // mode for Regul 1
#define CHILD_SCHED2      16 // mode for Regul 2

#define CHILD_NONE         0

// EEPROM mapping (do not change order)
#define EEP_NONE -1

#define EEP_UID         0
#define EEP_HUBID       (EEP_UID+1)
#define EEP_INPUT_DAY1  (EEP_HUBID+1)
#define EEP_INPUT_HUM1  (EEP_INPUT_DAY1+sizeof(inputRecord))
#define EEP_INPUT_HOUR1 (EEP_INPUT_HUM1+sizeof(inputRecord))
#define EEP_INPUT_DUR1  (EEP_INPUT_HOUR1+sizeof(inputRecord))
#define EEP_INPUT_DAY2  (EEP_INPUT_DUR1+sizeof(inputRecord))
#define EEP_INPUT_HUM2  (EEP_INPUT_DAY2+sizeof(inputRecord))
#define EEP_INPUT_HOUR2 (EEP_INPUT_HUM2+sizeof(inputRecord))
#define EEP_INPUT_DUR2  (EEP_INPUT_HOUR2+sizeof(inputRecord))
#define EEP_SCHED1      (EEP_INPUT_DUR2+sizeof(inputRecord))
#define EEP_SCHED2      (EEP_SCHED1+1)

// ###########################################
// ## If LED debug wanted                   ##
// ##                                       ##
#ifdef DEBUG_LED
#include <tinyNeoPixel.h>
#define NUM_LEDS 3
tinyNeoPixel leds = tinyNeoPixel(NUM_LEDS, PIN_LEDS, NEO_GRB + NEO_KHZ800);
#define LED_INIT {leds.begin(); leds.setBrightness(10);}
#define LED_RED(x) {leds.setPixelColor(x, leds.Color(255, 0, 0)); leds.show();}
#define LED_GREEN(x) {leds.setPixelColor(x, leds.Color(0, 255, 0)); leds.show();}
#define LED_BLUE(x) {leds.setPixelColor(x, leds.Color(0, 0, 255)); leds.show();}
#define LED_OFF(x) {leds.setPixelColor(x, leds.Color(0, 0, 0)); leds.show();}
#else
#define LED_INIT
#define LED_RED(x)
#define LED_GREEN(x)
#define LED_BLUE(x)
#define LED_OFF(x)
#endif
// ##                                       ##
// ###########################################

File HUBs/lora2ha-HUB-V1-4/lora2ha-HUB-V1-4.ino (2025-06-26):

/*
  Designed for ESP32's series
  Radio module : SX1278 (Ra-01 / Ra-02)

  Wifi AP
    - default ssid : lora2ha
    - default password : 12345678
    - default address : 192.164.4.1 (lora2ha0.local)

*/
#include <EEPROM.h> // native library
#include <FS.h>     // native library
#include <SPIFFS.h> // native library

// needed for ArduinoJson library
#define ARDUINOJSON_ENABLE_NAN 1
#include <ArduinoJson.h>         // available in library manager

#include <ESPAsyncWebServer.h>   // https://github.com/me-no-dev/ESPAsyncWebServer (don't get fork in library manager)
#include "config.h"              // inside file
#include "src/datetime.h"        // inside file
#include <RadioLink.h>           // GitHub project : https://github.com/PM04290/RadioLink

#ifndef ESP32
#error Only designed for ESP32
#endif

//      PCB      MLH1          MLH2            MLH3         MLH4         MLH5
// LoRa pin    Lolin ESP32   OLIMEX-POE      WT32-ETH01     ESP32        TTGO
//             (S2 Mini)                                   D1 Mini     LoRa 1.6.1
// SCK             7            14              14           18           5
// MISO            9            15              15           19          19
// MOSI           11             2               2           23          27
// NSS             5             5              12            5          18
// NRST           12             4              4             4          23
// DIO0            3            36              35            2          26

RadioLinkClass RLcomm;
bool loraOK;
JsonDocument docJson;

// UPDI
String needUploadFilename = "";

// for rtc
DateTime rtc = DateTime(2020, 1, 1, 0, 0, 0);
volatile bool newRTC = false;
portMUX_TYPE ntpMux = portMUX_INITIALIZER_UNLOCKED;

// for availability
bool needPublishOnline = true;

// buffer table for LoRa incoming packet
#define MAX_PACKET 20
typedef struct __attribute__((packed))
{
  uint8_t version;
  int lqi;
  rl_packets packets;
} packet_version;
packet_version packetTable[MAX_PACKET];
volatile byte idxReadTable = 0;
volatile byte idxWriteTable = 0;

// extern function after hub.hpp
void MQTTcallback(char* topic, byte* payload, unsigned int length);
void notifyDeviceForm(uint8_t d);
void notifyDevicePairing(uint8_t d);
void notifyDeviceHeader(uint8_t d);
void notifyChildLine(uint8_t d, uint8_t c);
void TaskUploadModule(void *pvParameters);

#include "hub.hpp"       // inside file
#include "network.hpp"   // inside file
#include "webserver.hpp" // inside file

// for 1 Second interrup
hw_timer_t* secTimer = NULL;
portMUX_TYPE timerMux = portMUX_INITIALIZER_UNLOCKED;
volatile bool topSecond = false;

// for NTP update
TaskHandle_t xHandleNTP = NULL;

#ifdef UPDI_TX
// for Upload
#include "src/AVRProg.h"   // inside file
AVRProg avrProg = AVRProg();
#endif

// Callback for memory problem
void heap_caps_alloc_failed_hook(size_t requested_size, uint32_t caps, const char *function_name)
{
#ifdef DEBUG_SERIAL
  printf("!!! %s failed to allocate %d bytes with 0x%X capabilities. \n", function_name, requested_size, caps);
  printf("heap_caps_get_largest_free_block: %d\n", heap_caps_get_largest_free_block(MALLOC_CAP_8BIT));
#endif
}

void IRAM_ATTR onTimer()
{
  portENTER_CRITICAL_ISR(&timerMux);
  topSecond = true;
  portEXIT_CRITICAL_ISR(&timerMux);
}

void TaskNTP(void *pvParameters)
{
  DateTime* _rtc = (DateTime*)pvParameters;
  const TickType_t xDelay = 2000 / portTICK_PERIOD_MS;
  configTzTime(datetimeTZ, datetimeNTP, defaultNTP);
  while (true)
  {
    struct tm timeinfo;
    uint8_t retry = DEFAULT_RETRY_NTP;
    while (retry > 0) {
      if (getLocalTime(&timeinfo))
      {
        timeinfo.tm_year += 1900;
        timeinfo.tm_mon += 1;
        DEBUGf("NTP:%04d-%02d-%02d %02d:%02d:%02d\n", timeinfo.tm_year, timeinfo.tm_mon, timeinfo.tm_mday, timeinfo.tm_hour, timeinfo.tm_min, timeinfo.tm_sec);
        portENTER_CRITICAL_ISR(&ntpMux);
        *_rtc = DateTime(timeinfo.tm_year, timeinfo.tm_mon, timeinfo.tm_mday, timeinfo.tm_hour, timeinfo.tm_min, timeinfo.tm_sec);
        newRTC = true;
        portEXIT_CRITICAL_ISR(&ntpMux);
        retry = 0;
      } else {
        retry--;
        DEBUGf("NTP:no time yet %d/10\n", DEFAULT_RETRY_NTP - retry);
        vTaskDelay( xDelay );
      }
    }
    vTaskSuspend( NULL );
  }
}

#ifdef UPDI_TX
void TaskUploadFirmware(void *pvParameters)
{
}
#endif

//TODO Bouton Reset dans H.A

bool getPacket(packet_version* p)
{
  if (idxReadTable != idxWriteTable)
  {
    *p = packetTable[idxReadTable];
    //
    idxReadTable++;
    if (idxReadTable >= MAX_PACKET)
    {
      idxReadTable = 0;
    }
    return true;
  }
  return false;
}

void onLoRaReceive(uint8_t len, rl_packet_t* p)
{
  noInterrupts();
  memcpy(&packetTable[idxWriteTable].packets.current, p, len);
  packetTable[idxWriteTable].version = 1;
  packetTable[idxWriteTable].lqi = RLcomm.lqi();
  if (len == RL_PACKETV1_SIZE) packetTable[idxWriteTable].version = 1;
  idxWriteTable++;
  if (idxWriteTable >= MAX_PACKET)
  {
    idxWriteTable = 0;
  }
  if (idxWriteTable == idxReadTable) // overload
  {
    idxReadTable++;
    if (idxReadTable >= MAX_PACKET)
    {
      idxReadTable = 0;
    }
  }
  interrupts();
}
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

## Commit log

2024-02-07 device update and gerber
2024-04-13 fix olimex reset and new .bat files
    fix olimex reset
    add/modify .bat files and firmware binary
    [config.h, devices.hpp, network.hpp]
2024-04-14 add WMODE patch documentation for PCB MLH v1.0
2024-04-16 add 3D files
    [MLA30 v1.1.f3z, MLA30 v1.1.obj, MLA30 v1.1.stl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]
2024-06-28 Create Boitier MLH2.stl
    [Boitier MLH2.stl]
2024-07-01 add gerber for MLD03
2024-07-12 MLA30 2.1 (i2c fix)
2024-07-12 fix lora2HA Hub nameing
    [config.h, datetime.cpp, devices.hpp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]
2024-12-08 New version 2.0 of modules and 1.0 for HUB
    [Boitier MLH2.stl, MLA30 v1.1.f3z, MLA30 v1.1.obj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]
2024-12-28 add 3D OBJ files
    [MLA30 v2.1.obj, MLE31 v1.0.obj, MLH2 v2.0.obj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]
2025-01-24 HUB 1.2
    LoRa state error on web page and retained False on trigger
    [AVRProg.cpp, UPDIProg.cpp, config.h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]
2025-06-26 HUB v 1.4 and new communication driver
2025-07-30 Add MLT3216 v1.1 Gerber & JCLPCB procedure
    [BOM_MLT3216_V1.1.csv, PickAndPlace_PCB_MLT3216-V1.1.csv]
2025-08-28 update gerber files for MLT3216
    [BOM_MLT3216_2025-08-28.csv, BOM_MLT3216_V1.1.csv, PickAndPlace_PCB_MLT3216-V1.1.csv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]
